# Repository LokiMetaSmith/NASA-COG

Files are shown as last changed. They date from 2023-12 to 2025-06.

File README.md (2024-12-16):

# NASA-MCOG

## Final Report

The final report delivered to NASA for this project can be [read here](https://drive.google.com/file/d/1jfJcSLfsybuC49I7llPhfTNI8ucRUW3h/view?usp=sharing).

## Introduction

This is a repo for a control system made for NASA to drive a Ceramic Oxygen Generation
technology they have developed. It was forked from ["The Ox"]() project of Public Invention run by Mr. Ben Coombs, which was in turn a fork of the VentOS project of Helpful Engineering led by Ben Coombs, Dr. Erich Schulz, and Robert L. Read.

However, the main reason we are starting with this fork is not that the Pressure Swing
Adsorption system of the Ox is a particularly relevant, but rather that the code
represents a nice platform of simple (microcontroller) control of related machines.

To wit, includes PlatformIO configuration, a state machine (finite automata),
a superloop architecture, and a hardware abstraction layer.

This particular project of NASA will improve life support technology in space,
but may eventually greatly improve global health.

An unlisted [YouTube video](https://youtu.be/1nq-Mw7jZ5A) has been uploaded that shows this work in-progress as of September 2022.

## How to run

### Linux
The fundamental way to run this is to perform:  
> cd firmware  
> pio run -e native && ./.pio/build/native/program  
We are currently creating the [RibbonFish](https://github.com/PubInv/NASA-COG/blob/develop/RibbonFish.md) proof-of-concept.
This can be run on a Due by executing:  
> make pio-run-due_ribbonfish  
As this develops, it will use a specific Due hardware configuration,  
please see the [documentation](https://github.com/PubInv/NASA-COG/blob/develop/RibbonFish.md) for details to build your own.  

### Windows
With Powershell
Navigate to the firmware folder. 
Type: pio run -e due_ribbonfish


With Visual Studio Code.  
Install the Plateform IO extension  
To open the project in Visual Studio Code.  
Open Project. Navigate to the firmware folder.   
Select the file platformio.ini  
Press the build check mark on the bottom of the window.


To disable the automatic load and serial monitor comment out the lines with "targets = upload, monitor" in the file "platformio.ini"

## Annoyances

AFAIK, PlatformIO forces a directory tree depth of 5 levels.

This is not enough to organize the Hardware Abstraction Level the way I would prefer, forcing us to make some messy directories that are less than clear.

For example, to implement a Temperature Sensor, we would ideally have an
abstract (or virtual) implementation, a folder for real hardware,
and a folder for mock sensors.  I have no choice now but to jam
the mock sensors into the same directory with the real hardware and
use a naming convention to differentiate them.

## The Command System

The NASA-COG system needs to allow the user to enter commands. The most obvious of these is "turn off".
Because the system should avoid thermal shocks, this is actually not simple.

We have previously used an [approach](https://github.com/PubInv/PIRCS-pubinv-respiration-control-standard) of using simple JSON objects to represent commands. We propose to use the same idea here, but obviously,
the command will be custom to the NASA-COG.

### Parameter Setting Commands
The general scheme is to use a JSON object like:

```JavaScript
{ "com": "T",
  "par": 7,
  "mod": "T",
  "val" : 732.3
  }
```

1. "com" is the command. For example, "T" can mean "set Temperature".
2. "par" is a parameter used to specify something about how to execute the command. For example, 7 could mean location 7, which might be between the 6th and 7th stack.
3. "mod" is a modifier of the command. For example, the "set Temperature" command could be used to
set the minimum, maximum, or the target temperature.
4. "val" is the value that is to be set.

For this problem space, we can specify some global parameters of the problem, some of which
involve safety. These can of course have default values "hard wired" into the code, but an
experimenter may wish to change these values (carefully).

1. The maximum rate of voltage change applied to a stack. Nominally we have defined this as 1 volt/second.
We have evidence that too rapid a voltage change (such as that caused by pulse-width modulation) can destroy
a stack.
2. The maximum rate of temperature change for a stack. Nominally we may say this as 2 degree K per minute,
which would allow the machine to reach operating temperature in 6 hours.
3. The maximum temperature difference across a stack in any dimension. We may not be able to control
this directly, but we can use it as a target.
4. The maximum voltage applied to a stack.
5. The maximum amperage applied to a stack.

### Event-like Commands

We will need other commands that represent discrete events in time. For example, each transition in the
state transition diagram below may be initiated by a command from the user (they may also occur
automatically due to an internal fault or even normal operation.)

COG State Machine

We can implement particular commands with the same scheme.

For example, the simple object:

```JavaScript
{ "com": "C",
  "par": 0,
  "int": "s",
  "mod": "U",
  "val" : 0.0
  }
```

Could mean "Cool Down". The value "U" is used becasue the "mod" command is "unusued" in this case.

```JavaScript
{ "com": "W",
  "par": M,
  "int": "s",
  "mod": "U",
  "val" : 0.0
  }
```

In actual practice, these commands will be pasted into the serial port using either PlatformIO or the Arduino IDE.

Eventually, a user interface may be implemented that uses a knob or a nice webpage to enter commands.
However, by having each of these take only actions that can be implemented as such a command,
we bring discipline to the internal code.

## Actual Serial Commands

The serial port currently supports 6 one-character commands: w,c,e,a,i,o.
These mean:
1. warmup
2. cool down
3. emergency shutdown
4. acknowledge
5. idle
6. operate

Note: "acknowledge" means that the operator acknowledges that a critical
state has occurred and asserts it is okay to return to normal operation,
either because the problem as been removed or for some other reason.

Addtionally, the system supports "full commands", that look like this:

> { "com": "W", "par": "M", "int": "s", "mod": "U", "val" : 0.0 }

> { "com": "C", "par": "M", "int": "s", "mod": "U", "val" : 0.0 }

> { "com": "E", "par": "M", "int": "s", "mod": "U", "val" : 0.0 }

> { "com": "A", "par": "M", "int": "s", "mod": "U", "val" : 0.0 }

> { "com": "I", "par": "M", "int": "s", "mod": "U", "val" : 0.0 }

> { "com": "O", "par": "M", "int": "s", "mod": "U", "val" : 0.0 }

In fact, each "one character" command is a short hand for these commands.

The following format can be used to set parameters (P).
The three most important parameters are:
1. T : Temperature (in C) going into the stack
2. C : Current (in milliamps) going into the stack
3. F : Fan speed in RPM (we expect this to change to flow rate in SLM)
> { "com": "P", "par": "T", "int": "T", "mod": "U", "val" : 35 }

> { "com": "P", "par": "C", "int": "T", "mod": "U", "val" : 500 }

> { "com": "P", "par": "F", "int": "T", "mod": "U", "val" : 2000 }

These three commands set the:
1. Temperature into the stack to 35C
2. Set the Target current into the stack to 500 milliamps
3. Set the flow rate to 2000 ml/seconds

## License

In general we intend to follow the [Public Invention Licensed Guidelines](https://github.com/PubInv/PubInv-License-Guidelines) unless
NASA requests something different. If you are starting your own project, please
feel free to fork the license guidelines as a starting point if you like our
license policy.

This program includes free software: you can redistribute it and/or modify it under the terms of the GNU Affero General Public License as published by the Free Software Foundation, either version 3 of the License, or (at your option) any later version.

See the GNU Affero General Public License for more details. You should have received a copy of the GNU Affero General Public License along with this program. If not, see <https://www.gnu.org/licenses/>.

This program is distributed in the hope that it will be useful, but WITHOUT ANY WARRANTY; without even the implied warranty of MERCHANTABILITY or FITNESS FOR A PARTICULAR PURPOSE.

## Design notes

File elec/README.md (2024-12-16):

# Electrical Information on OEDCS Controler(s) and Plant(s)
PCB Connector Pin signal names, Due Signal Names, Chassis wiring and related information
Inverse cronological order

## Notes for creation of a Control 1.2 PCB  
tbd

## Notes for creation of a Control 1.1 PCB  
This table pulls from information in the references 1 and 2.   
References:
1. Due Pin-Out Map for OEDCS1 : https://docs.google.com/spreadsheets/d/18wP1Cyg5-j3FP92x7no_JsCCFNvo9y2avyn5nvmAj6I/edit#gid=0
2. Fan Controller and Fan Wiring for OEDCOS1: https://docs.google.com/document/d/1n3v-AxqNKEzcKqmHicGKnFmG8sKbNEL_pGaUlU9CZ8U/edit

   WARNING! At present pin D4 works without an external pull up resistor for the termocouples, but D5 does not; it requires an external pull up resistor
   Until we have time to rework our perf board, I am going to continue to use D4 for the MAX31850 OneWire interface.

#### Due Pin Wiring Control 1.1
| **Due Pin Number** 	| **Breakout** 	| **Signal Name** 	| **Set as I/O** 	| **Connection** 	| **Notes** 	|
|---	|---	|---	|---	|---	|---	|
| D0 	| J6-2 	| NA 	| Input pullup. 	| None 	| Not used 	|
| D1 	| J6-1 	| NA 	| Input pullup. 	| None 	| Not used 	|
| D2 	| J6-3 	| NA 	| Input pullup. 	| None 	| Not used 	|
| D3 	| J6-4 	| NA 	| Input pullup. 	| None 	| Not used 	|
| D4 	| J6-5 	| SD ENABLE (BUT ALSO TEMP1) | Input pullup. 	| None 	| SD CS on Ethernet card. 	|
| D5 	| J6-6 	| TEMP1 	| BiDirection 	| Dallas 1 Wire / MAX31850K 	| Three daisy chained, requires 4.7k ohm pull up resistor (but D4 does not!) Please see note 	|
| D6 	| J6-7 	| NA 	| Input pullup. 	| None 	| Not used 	|
| D7 	| J6-8 	| NA 	| Input pullup. 	| None 	| Not used 	|
| D8 	| J7-1 	| NA 	| Input pullup. 	| None 	| Not used 	|
| D9 	| J7-2 	| nFAN1_PWM 	| Output 	| Controlles transistor Q1 	| Was BLOWER_PWM 	|
| D10 	| J7-3 	| NA 	| Input pullup. 	| None 	| Not used 	|
| D11 	| J7-4 	| NA 	| Input pullup. 	| None 	| Not used 	|
| D12 	| J7-5 	| NA 	| Input pullup. 	| None 	| Not used 	|
| D13 	| J7-6 	| NA 	| Input pullup. 	| None 	| Not used 	|
| D13 	| J7-6 	| NA 	| Input pullup. 	| None 	| Not used 	|
| D14 	| J2-1 	| NA 	| 	| None 	| Not used 	|
| D15 	| J2-2 	| NA 	| Input pullup. 	| None 	| Not used 	|
| D16 	| J2-3 	| NA 	| Input pullup. 	| None 	| Can be TX2 	|
| D17 	| J2-4 	| NA 	| Input pullup. 	| None 	| Can be RX2 	|
| D18 	| J2-5 	| D_PSU_TX 	| UART1 TX 	| D_PSU_TX, R15 (then to Power Supply 	| TX1 	|
| D19 	| J2-6 	| D_PSU_RX 	| UART1 RX 	| D_PSU_RX, R14 (then to Power Supply 	| RX1 	|
| D20 	| J2-7 	| SDA 	| SDA 	| test point SDA1, R4, R13 	| SDA 	|
| D21 	| J2-8 	| SCL 	| SCL 	| test point SCL1, R2, R16 	| SCL 	|
| D22 	| J8-4 	| BLOWER_ENABLE 	| OUTPUT 	| R10 	| Enable Switched_Fan_Power at J15 9-12 	|
| D23 	| J8-3 	| NA 	| Input pullup. 	| None 	| Not used 	|
| D24 	| J8-6 	| NA 	| Input pullup. 	| None 	| Not used 	|
| D25 	| J8-5 	| NA 	| Input pullup. 	| None 	| Not used 	|
| D26 	| J8-8 	| NA 	| Input pullup. 	| None 	| Not used 	|
| D27 	| J8-7 	| NA 	| Input pullup. 	| None 	| Not used 	|
| D28 	| J8-10 	| NA 	| Input pullup. 	| None 	| Not used 	|
| D29 	| J8-9 	| NA 	| Input pullup. 	| None 	| Not used 	|
| D30 	| J8-12 	| NA 	| Input pullup. 	| None 	| Not used 	|
| D31 	| J8-11 	| NA 	| Input pullup. 	| None 	| Not used 	|
| D32 	| J8-14 	| nCS_GPAD 	| Output for nCS 	| R55, R61, Q5 	| on 3.3 Volt 	|
| D33 	| J8-13 	| TC_nCS1 	| Output for nCS 	| Thermocouple 1, R7 	| on 3.3 Volt 	|
| D34 	| J8-16 	| TC_nCS2 	| Output for nCS 	| Thermocouple 2, R3 	| on 3.3 Volt 	|
| D35 	| J8-15 	| TC_nCS3 	| Output for nCS 	| Thermocouple 3, R1 	| on 3.3 Volt 	|
| D36 	| J8-18 	| NA 	| Input pullup. 	| None 	| Not used 	|
| D37 	| J8-17 	| NA 	| Input pullup. 	| None 	| Not used 	|
| D38 	| J8-20 	| NA 	| Input pullup. 	| None 	| Not used 	|
| D39 	| J8-19 	| NA 	| Input pullup. 	| None 	| Not used 	|
| D39 	| J8-19 	| NA 	| Input pullup. 	| None 	| Not used 	|
| D40 	| J8-22 	| NA 	| Input pullup. 	| None 	| Not used 	|
| D41 	| J8-21 	| NA 	| Input pullup. 	| None 	| Not used 	|
| D42 	| J8-24 	| NA 	| Input pullup. 	| None 	| Not used 	|
| D43 	| J8-23 	| NA 	| Input pullup. 	| None 	| Not used 	|
| D44 	| J8-26 	| NA 	| Input pullup. 	| None 	| Not used 	|
| D45 	| J8-25 	| NA 	| Input pullup. 	| None 	| Not used 	|
| D46 	| J8-28 	| NA 	| Input pullup. 	| None 	| Not used 	|
| D47 	| J8-27 	| NA 	| Input pullup. 	| None 	| Not used 	|
| D48 	| J8-30 	| NA 	| Input pullup. 	| None 	| Not used 	|
| D49 	| J8-29 	| NA 	| Input pullup. 	| None 	| Not used 	|
| D50 	| J8-32 	| NA 	| Input pullup. 	| None 	| Not used 	|
| D51 	| J8-31 	| SSR_PWM 	| OUTPUT 	| R9 	| Active High. 	|
| D52 	| J8-34 	| NA 	| Input pullup. 	| None 	| Not used 	|
| D53 	| J8-33 	| NA 	| Input pullup. 	| None 	| Not used 	|
| SDA1 	| J7-9 	| NA 	| Input pullup. 	| None 	| Not used 	|
| SCL1 	| J7-10 	| NA 	| Input pullup. 	| None 	| Not used 	|
| CANR 	| J4-7 	| NA 	| Input pullup. 	| None 	| Not used 	|
| CANT 	| J4-8 	| NA 	| Input pullup. 	| None 	| Not used 	|
| DAC0 	| J4-5 	| Disable 	| Only Output 	| None 	| Not used 	|
| DAC1 	| J4-6 	| Disable 	| Only Output 	| None 	| Not used 	|
| A0 	| J5-1 	| BLOWER_TACH 	| Input pullup. 	| R11 	| Measure RPM 	|
| A1 	| J5-2 	| NA 	| Input pullup. 	| None 	| Not used 	|
| A2 	| J5-3 	| NA 	| Input pullup. 	| None 	| Not used 	|
| A3 	| J5-4 	| NA 	| Input pullup. 	| None 	| Not used 	|
| A4 	| J5-5 	| NA 	| Input pullup. 	| None 	| Not used 	|
| A5 	| J5-6 	| NA 	| Input pullup. 	| None 	| Not used 	|
| A6 	| J5-7 	| NA 	| Input pullup. 	| None 	| Not used 	|
| A7 	| J5-8 	| NA 	| Input pullup. 	| None 	| Not used 	|
| A8 	| J4-1 	| NA 	| Input pullup. 	| None 	| Not used 	|
| A9 	| J4-2 	| NA 	| Input pullup. 	| None 	| Not used 	|
| A9 	| J4-2 	| NA 	| Input pullup. 	| None 	| Not used 	|
| A10 	| J4-3 	| NA 	| Input pullup. 	| None 	| Not used 	|
| A11 	| J4-4 	| NA 	| Input pullup. 	| None 	| Not used 	|
| AREF 	| J7-8 	| NA 	| From DUE 	| None 	| Not used 	|
| nRST1 	| J3-6 	| NA 	| Pulled up on DUE 	| None 	| Not used 	|
| IOREF 	| J3-7 	| NA 	| NA 	| None 	| Not used 	|
| VIN 	| J3-1 	| VIN 	| NA 	| +12V into this pin through R76 	| 	|
| +5V 	| J3-4 	| VIN+5V 	| NA 	| Power from Due voltage regulator 	| Three pins. 	|
| 3.3V 	| J3-5 	| 3.3V 	| NA 	| Power from Due voltage regulator 	| One pin. 	|
| MISO 	| tp CPIO1 	| CIPO 	| Input 	| SPI bus 	| 	|
| MOSI 	| tp COPI 	| COPI 	| Output 	| SPI bus 	| 	|
| SCK 	| tp SPI_SCK 	| SPI_SCK 	| Output 	| SPI bus 	| 	|
| nRST2 	| NA 	| SPI_nRST 	| Input 	| S1 reset switch 	| 	|
| end 	| 	| 	| 	| 	| 	|  

**Ethernet pin usage:**
Pins usage on Arduino
* D4: SD card chip select
* D10: W5200 Chip Select
* D11: SPI MOSI
* D12: SPI MISO
* D13: SPI SCK

### Chassis Wiring of OEDCS Unit 2.
Diagram(s) here...

## Unit 1
**Wiring of OEDCOS Unit 1 before the swap out with Control 1.1 assembly**
Notes
1. Due Pin-Out Map for OEDCS SN1 : https://docs.google.com/spreadsheets/d/18wP1Cyg5-j3FP92x7no_JsCCFNvo9y2avyn5nvmAj6I/edit#gid=0
2. Fan Controller and Fan Wiring for OEDCS1: https://docs.google.com/document/d/1n3v-AxqNKEzcKqmHicGKnFmG8sKbNEL_pGaUlU9CZ8U/edit

Wiring of thermocouple amplifires


Revisions:
* 20230821, Update DB25 Male 2-5 from +12V to "+24V Switched (fans)"

| Fan Breakout 	| Signal-Function 	| DB25 MALE Pin # 	| DB25 FEMALE Pin # 	| Other 	| Due Pin 	| Due Signal 	|
|---	|---	|---	|---	|---	|---	|---	|
| 1 	| +24V Switched (fans) 	| 2-5 	| 9-12 	| 	| ??? 	| FAN_POWER 	|
| 2 	| GND for all fans  	| 22-25 	| 14-17 	| 	| GND 	| NA 	|
| 3 	| #1 PWM 	| 13 	| 1 	| J10-1 	| D9 	| nFAN1_PWM  	|
| 4 	| #1 Tach 	| 9 	| 5 	| J9-1  	| A0 	| FAN1_FG 	|
| 5 	| #2 PWM 	| 12 	| 2 	| J10-2 	| 	| nFAN2_PWM  	|
| 6 	| #2 Tach 	| 8 	| 6 	| J9-2  	| 	| FAN2_FG 	|
| 7 	| #3 Tach 	| 11 	| 3 	| J10-3 	| 	| nFAN3_PWM  	|
| 8 	| #3 PWM 	| 7 	| 7 	| J9-3  	| 	| FAN3_FG 	|
| 9 	| #4 Tach 	| 10 	| 4 	| J10-4 	| 	| nFAN4_PWM  	|
| 10 	| #4 PWM 	| 6 	| 8 	| J9-4  	| 	| FAN4_FG 	|
| 	| 	| 	| 25 	| J11-3 	| 	| 	|
| 	| 	| 	| 13 	| J11-4 	| 	| 	|
| 	| 	| 	| 18 	| J12-1 	| 	| 	|
| 	| 	| 	| 19 	| J12-2 	| 	| 	|
| 	| 	| 	| 20 	| J12-3 	| 	| 	|
| 	| 	| 	| 21 	| J12-4 	| 	| 	|
| 	| 	| 	| 22 	| J12-5 	| 	| 	|
| 	| 	| 	| 23 	| J12-6 	| 	| 	|
| 	| 	| 	| 24 	| J12-7 	| 	| 	|

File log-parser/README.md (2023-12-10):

json_log_parser.py is a simple scraper that reads malformed JSON data and performs a series of statistical operations on the data to display the graphs of different properties of the data. 

Usage:

Server access to raw files is nessisary for viewing, in the script there is an array of file locations that can be used to load one or more logs for analysis. They are read in order, so time series data should be preserved if read in the correct order. 

Currently the standard deviation for Temperature, Voltage, Current, and Resistance(as a function of Voltage and Current) are calculated
Other statistical parameters can be added easily

Currently six graphs are produced, Temperature vs Time (unitless), Voltage and current vs Time (unitless), Resistance vs Time (Unix Standard ), Change in Resistance Vs Change in Temperature (this doesn't appear useful at this time), Delta Resistance vs average temperature

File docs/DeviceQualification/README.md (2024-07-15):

# Summary
Part of a test plan for qualifying the OEDCS (Oxygen Engine Digital Control System) 
Written during the Task6 development effort which is to deliver a controller for "long duration" reliability testing of the OEDCS when attached to a CFC.  

## Scope: AC Drop Out / Brown Out Testing
A test specification and procedure for low AC input, aka Brownout.  
A test specification and procedure for interrupted AC input, aka drop out.  

## Required Test Equipment and Setup
Device under test. The device under test must NOT be receiving power from the USB connection.  Modify (cut up) a USB cable to interrupt the +5V to the DUT.  

In addition to a device under test, 
Both typical and corner case loads for the stack supply 
* Shunt
* Nominal load
* Open 
AC line auto transformer make: Model number: Serial number: 
Device for interrupting the AC power. (A switched outlet is a start. However an AC relay under computer control for set drop out duration and phase is even better.)  
Multi meter for monitoring RAW AC Line Input.  
Multi meter for monitoring AC output of Auto transformer, the input to the OEDCS.  
Multi meter for monitoring +24 power supply at Controller TP20.  
Multi meter for monitoring +12 power supply at Controller TP2.  
Multi meter for monitoring +5 power supply at Controler J3 pin 4.  
Multi meter for monitoring voltage Back Up (Sealed Lead Acid batter) at Controller TP???  
Possible oscilloscope for capturing sequence of events and the unexpected.  
Possible logic analyzer for capturing sequence of events and the unexpected.  
Lab thermometer to capture ambient temperature.  

### Setup For Test
*Describe the solution you'd like* 
*A clear and concise description of what you want to happen.* 
Set up of DUT and testing system in a test state(s) 
Connect multi meters at TP2, TP20, the sealed lead acid battery.
> Screen shot of +5V, TP2 and TP20 


Connect OEDCS at front panel (except where noted) to:
1. USB and a PC with a logging terminal program such as TeraTerm
2. NO LAN connection (Future feature expansion)
3. Three or four thermocouples
4. I2C to pressure transducer (Future feature expansion)
5. Blower
6. AC to heater
7. DC to: Stack or shunt or open
8. Through the AC interrupt fixture and the auto transformer connect the AC input **on back panel**

Connect multi meters at +5V, +12 PT2, and +24 TP20.  
Connect current meter in line with Back Up battery.  

## Test Procedure Brown Out
Test conditions and procedures and expected results or information to be captured 
### Test Capture Normal Operation Conditions with Stack Supply: Open Load
During this test, journal how the system fails, the sequence and at what voltages supplies go out of regulation. At what AC input voltage does the controller stop if any?

Capture lab ambient temperature.  
All external power to the device is off.
Connect the USB cable to the DUT and a PC.
Use Serial Monitor the USB to Serial connection to the DUT.  Capture to a TIME STAMPED file with a name reflecting the test a log during the test. Example OEDCS_SN1_NOMINAL_AC_STACK_OPEN.txt 
??? Do we press reset now ???

Apply nominal 120VAC power. 
Monitor system status.  Verify that the controller is operating normally by monitoring the USB serial report.
Capture these parameters at this nominal input.
1. AC into ODECS
2. +24 at TP20
3. +12 at TP2
4. V sealed battery
5. +5V at Back Up battery
6. Current drain on the sealed lead acid battery

### Test For Condition Brown Out with Stack Supply: Open Load
Capture lab ambient temperature.  
Lower AC input voltage, 5V steps may be a good step size. Allow to stabilize for 15 seconds (Verify that this seams to be a good time.) 
At each AC voltage input capture the following:
1. AC into ODECS
2. +24 at TP20
3. +12 at TP2
4. V sealed battery
5. +5V at Back Up battery
6. Current drain on the sealed lead acid battery

### Test For Condition Brown Out Recovery with Stack Supply: Open Load
Capture lab ambient temperature.  
Raise from zero AC input voltage, 5V steps may be a good step size. Allow to stabilize for 15 seconds (Verify that this seams to be a good time.) 
Journal how the system restarts, what is the sequence of each supply. 
At each AC voltage input capture the following:
1. AC into ODECS
2. +24 at TP20
3. +12 at TP2
4. V sealed battery
5. +5V at Back Up battery
6. Current drain on the sealed lead acid battery

Any pathological behaviours?
On what conditions do the controller become active?  
On what conditions does the +12V supply become active?  
On what conditions does the +24V supply become active?  
Describe how the stack power supply recovers and any intervention required by firmware to be implemented in an issue.

### Test For Condition Brown Out with Stack Supply: Shunt
Change out stack supply for a shunt. Retest same as above 
### Test For Condition Brown Out Recovery with Stack Supply: Shunt
Retest same as above. 

### Test For Condition Brown Out with Stack Supply: Nominal load
Change out stack supply for a shunt. Retest same as above 
### Test For Condition Brown Out Recovery with Stack Supply: Nominal load
Retest same as above. 

## Test Procedure AC Drop Out
Test conditions and procedures and expected results or information to be captured 
It is assumed the system still has normal conditions as per the test above "Test Capture Normal Operation Conditions with Stack Supply"
If not journal again the nominal conditions

### Test Capture Normal Operation Conditions with Stack Supply: Nominal load
During this test, journal how the system fails, the sequence and at what voltages supplies go out of regulation or recover in pathological ways. 
Power will be interrupted for short but increasingly long times to root out pathological behavior. 

All external power to the device is off.
Connect the USB cable to the DUT and a PC.
Use Serial Monitor the USB to Serial connection to the DUT.  Capture to a TIME STAMPED file with a name reflecting the test a log during the test. Example OEDCS_SN1_NOMINAL_AC_STACK_OPEN.txt 
??? Do we press reset now ???

Apply nominal 120VAC power. 
Monitor system status.  Verify that the controller is operating normally by monitoring the USB serial report.
Capture these parameters at this nominal input.
1. AC into ODECS
2. +24 at TP20
3. +12 at TP2
4. V sealed battery
5. +5V at Back Up battery
6. Current drain on the sealed lead acid battery

### Test For Condition Manual AC Drop Out with Stack Supply: Nominal load
#### Minimum Interruption
Assuming using a toggle switch, Interrupt (off then on) the AC as fast as possible at least five times in hopes of sampling several phases of the AC line at the time of interruption.
Observe the system for pathological behaviors.
Did the system operate normally through the interruption?  Describe system operation: 
______________________________________________________________________________________ 
______________________________________________________________________________________ 
______________________________________________________________________________________ 

#### Longer Interruption
Gradually Increase the off time repeating with the same off time for about five times

Observe the system for pathological behaviors.
Did the system operate normally through the interruption?  Describe system operation: 
______________________________________________________________________________________ 
______________________________________________________________________________________ 
______________________________________________________________________________________ 

### Test For Condition Automated AC Drop Out with Stack Supply: Nominal load
An AC Drop Out test system based on OEDCS.
Use an OEDCS with custom firmware for this test function as a AC interrupt fixture with which to test the OEDCS under actual test.
Connect from the AC output of the the drop out text fixture in to the the OEDCS under actual test.
Develop firm ware which can turn off (Open) the solid state relay SSR1 for increasing duration. Extra credit if the firmware can be phased triggered from the AC line. 

#### Interruption profile
Set for minimum phase delay
Set for minimum interruption time
Set for number if interruptions

With zero phase delay, increase interruption time till the system behavior changes and journal that change. Continue to look for pathological behaviors.
Observe the system for pathological behaviors.
Did the system operate normally through the interruption?  Describe system operation: 
______________________________________________________________________________________ 
______________________________________________________________________________________ 
______________________________________________________________________________________ 

With insight from the interruption time increase phase delay from zero through at least 32mS (two AC cycles),
Observe the system for pathological behaviors.
Did the system operate normally through the interruption?  Describe system operation: 
______________________________________________________________________________________ 
______________________________________________________________________________________ 
______________________________________________________________________________________

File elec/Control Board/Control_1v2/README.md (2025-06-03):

# Contents of This Folder Copyed. MAKE NO MORE CHANGES HERE
See: https://github.com/PubInv/high-amp-controller-board
Copied on date: 20250526

<hr>
# Control V1.1 aka 1V1
Version 1.1 control board for NASA COG

On line schematic viewing from **Kicanvas** See: https://kicanvas.org  
The Control V1 is an Arduino DUE "Shield". The DUE will live below this printed wiring assembly. An Ethernet shield will live above as a "Socket". See KiCad Symbol & Footprint Library for Arduino Modules for "Shield" and "Socket"

## Schematics
### Browser page view of the schematic by KiCanvas.org 
Top page is "Control v1.kicad_sch". Note the page for MAX31856 is actualy for an MCP9600 but the page was not renamed (as of 20230830)
*  [Control1v1.kicad_sch](https://kicanvas.org/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)
* [Adafruit-MAX31850-thermocouple-breakout-board.kicad_sch](https://kicanvas.org/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)
* [Adafruit-MAX31855-breakout-board.kicad_sch](https://kicanvas.org/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)
* [Adafruit-MAX31856-PCB-master.kicad_sch](https://kicanvas.org/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)
* [Fan controller.kicad_sch](https://kicanvas.org/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)
* [I2C_Level_Shifter.kicad_sch](https://kicanvas.org/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)
* [SPI_ControllerLevel_Shifter.kicad_sch](https://kicanvas.org/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)
* [SSR Interface.kicad_sch](https://kicanvas.org/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)
* [display_interface.kicad_sch](https://kicanvas.org/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)

## PCB / PWA
### Browser page view of the PCB by KiCanvas.org 
Printed Circuit Board, Printed Wiring Assembly
* [Control 1v1.kicad_pcb](https://kicanvas.org/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)

### PCB / PWA 3D Snapshot


### BOM and Parts List
File Notes:
See notes on the Gerbers, BOM and placement files at:
https://github.com/PubInv/NASA-COG/issues/342

## License, Public Invention for this PCB, PWA
* [Firmware: Affero GPL 3.0](https://www.gnu.org/licenses/agpl-3.0.en.html#license-text)
* [CERN Open Hardware Licence Version 2 - Strongly Reciprocal](https://ohwr.org/cern_ohl_s_v2.txt)

<hr> 

## KiCad Symbol & Footprint Library for Arduino Modules
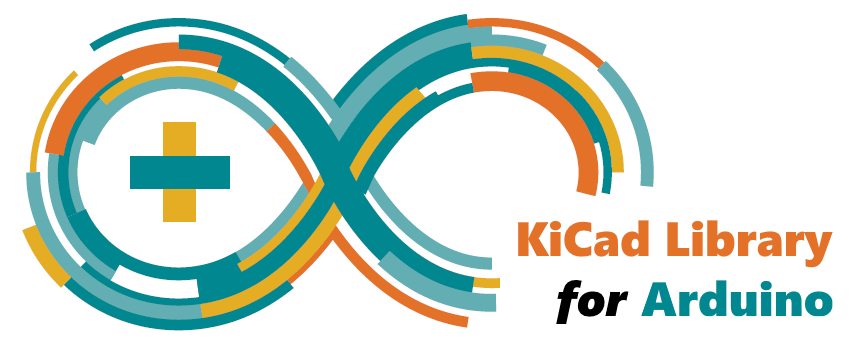
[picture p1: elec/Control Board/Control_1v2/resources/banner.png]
<a href="./PICS/Rev2/PWA_FrontView.png">  
*Version 4.1.0*  

     

This is a library of KiCad schematic symbols and PCB footprints for most Arduino modules. You can use them to make your own PCB design which will effortlessly connect with your chosen Arduino module.

Currently included modules:
- Arduino **101** Shield
- Arduino **Due** Shield
- Arduino **Giga R1 WiFi** Shield
- Arduino **Leonardo** Shield
- Arduino **M0** Shield
- Arduino **M0 Pro** Shield
- Arduino **Mega 2560 R3** Shield
- Arduino **Micro** Socket
- Arduino **Mini** Socket
- Arduino **MKR 1000 WiFi** Socket
- Arduino **MKR WiFi 1010** Socket
- Arduino **MKR FOX 1200** Socket
- Arduino **MKR WAN 1300** Socket
- Arduino **MKR WAN 1310** Socket
- Arduino **MKR GSM 1400** Socket
- Arduino **MKR NB 1500** Socket
- Arduino **MKR Vidor 4000** Socket
- Arduino **MKR Zero** Socket
- Arduino **Nano** Socket
- Arduino **Nano 33 BLE** Socket / Tile
- Arduino **Nano 33 BLE Sense** Socket / Tile
- Arduino **Nano 33 BLE Sense R2** Socket / Tile
- Arduino **Nano 33 IoT** Socket / Tile
- Arduino **Nano Every** Socket / Tile
- Arduino **Nano RP2040 Connect** Socket / Tile
- Arduino **Nicla Sense ME** Socket / Tile
- Arduino **Nicla Vision** Socket / Tile
- Arduino **Nicla Voice** Socket / Tile
- Arduino **Pro Mini** Socket
- Arduino **Uno R1** Shield
- Arduino **Uno R2** Shield
- Arduino **Uno R3** Shield
- Arduino **Uno R3 SMD** Shield
- Arduino **Uno R4 Minima** Shield
- Arduino **Uno R4 WiFi** Shield
- Arduino **Uno WiFi R2** Shield
- Arduino **Zero** Shield
- Clone **Mega 2560 Pro** Socket
- Clone **Pro Mini** Socket

*"Shield" means the module is designed to plug in from beneath your PCB. "Socket" means the module is designed to plug in from above your PCB. "Tile" means the module is designed to be soldered directly on to your PCB using surface-mount pads.*

## KiCad Version Compatibility
This library requires at least KiCad 6 to function, and is tested on KiCad versions 6.0.8 and 7.0.2. Note that the installation procedure is different for KiCad 6 and 7; please see the [Library Installation](#library-installation) section below.

## Comments, Requests, Bugs & Contributions
All are welcome!
Please open an [Issue](https://github.com/Alarm-Siren/arduino-kicad-library/issues) or [Pull Request](https://github.com/Alarm-Siren/arduino-kicad-library/pulls), as appropriate.

## Library Installation
To install this library in your copy of KiCad, choose the correct section for your version of KiCad and follow the steps given. These instructions only cover automated installation using KiCad's built-in Package and Content Manager (PCM); manual installation is possible but not supported.

### KiCad 7

**Warning**: Do not change the nickname prefix from that given in step 4 below. If you do so KiCad will not assign the correct footprints to the symbols by default.

1. Open KiCad and open the Preferences window at "Preferences" -> "Preferences..."
2. Select the "Plugin and Content Manager" section in the left-hand pane.
3. Ensure that the "Automatically add installed libraries to the global lib table" option is ticked.
4. Ensure that the "Library nickname prefix" is set to "PCM_".
5. Ensuring that the "Check for package updates on startup" option is ticked is recommended. **(Optional)**
6. Click "OK" to close the Preferences window.
7. Click the "Plugin and Content Manager" button.
8. Select the "KiCad official repository" from the top drop-down box (if not already selected).
9. Go the Libraries tab and locate the "KiCad Library for Arduino Modules" in the list.
10. Click the "Install" button for that entry in the list.
11. Click "Apply Pending Changes".
12. Close the "Applying Package Changes" window once it has finished.
13. You should now find that this library is listed in the "Installed" tab.
14. Close the Plugin and Content Manager.
15. You may need to restart KiCad for the library installation to fully take effect. **(Optional)**
16. All done: you are now ready to use these schematic components and footprints in your projects!

### KiCad 6
**Recommendation:** If you can, you should upgrade to KiCad 7.

**Warning**: Do not change the Nicknames from those given in steps 12 and 18 below. If you do so KiCad will not assign the correct footprints to the symbols by default.

1. Open KiCad and click the "Plugin and Content Manager" button.
2. Select the "KiCad official repository" from the top drop-down box (if not already selected).
3. Go the Libraries tab and locate the "KiCad Library for Arduino Modules" in the list.
4. Click the "Install" button for that entry in the list.
5. Click "Apply Changes".
6. Close the "Applying Package Changes" window once it has finished.
7. You should now find that this library is listed in the "Installed" tab.
8. Close the Plugin and Content Manager.
9. Go to the "Preferences" -> "Manage Symbol Libraries..." menu option.
10. In the Symbol Libraries dialogue that appears, switch to the "Global Libraries" tab (if not already selected).
11. Click "Add empty row to table" button (the button with a big cross in it, beneath the table).
12. In the new line of the table, set the Nickname to "PCM_arduino-library", and ensure the Library Format is set to "KiCad".
13. In the same line of the table, set Library Path to "${KICAD6_3RD_PARTY}/symbols/com_github_alarm-siren_arduino-kicad-library/arduino-library.kicad_sym".
14. Click "OK" to close the Symbol Libraries dialogue.
15. Go to "Preferences" -> "Manage Footprint Libraries..." menu option.
16. In the Footprint Libraries dialogue that appears, switch to the "Global Libraries" tab (if not already selected).
17. Click "Add empty row to table" button (the button with a big cross in it, beneath the table).
18. In the new line of the table, set the Nickname to "PCM_arduino-library", and ensure the Library Format is set to "KiCad".
19. In the same line of the table, set Library Path to "${KICAD6_3RD_PARTY}/footprints/com_github_alarm-siren_arduino-kicad-library/arduino-library.pretty".
20. Click "OK" to close the Footprint Libraries dialogue.
21. All done: you are now ready to use these schematic components and footprints in your projects!

## Donations

I really hope you've found this library useful. If you'd like to buy me a beer in thanks for the work I put into it, you can make a donation using the button below:



## License & Legal
Copyright 2017-2023, [Nicholas Parks Young](https://github.com/Alarm-Siren).

Except as otherwise noted, all content of this library is licensed under the 
[Creative Commons Attribution-ShareAlike 4.0 International License](https://creativecommons.org/licenses/by-sa/4.0/), with the following additional exception:
> To the extent that the creation of electronic designs that use the Licensed Material can be considered to be Adapted Material, the Licensor waives Section 3 of the Public License with respect to these electronic designs and any generated files which incorporate data provided as part of the Licensed Material.



### "KiCad Library for Arduino" Banner & Icon

The two images "resources/banner.png" and "resources/icon.png" are licensed under the [Creative Commons Attribution-NonCommercial-ShareAlike 4.0 International License](https://creativecommons.org/licenses/by-nc-sa/4.0/). These images are derivatives of ["Arduino Open-Source Community: Main Logotype RGB Colors" originally created by Arduino](https://www.arduino.cc/en/trademark/community-logo). 

Original Images: Copyright 2013, [Arduino](https://www.arduino.cc/). Derived Images: Copyright 2023, [Nicholas Parks Young](https://github.com/Alarm-Siren).



### Arduino Trademark

The word "Arduino" is a registered trademark of [Arduino](https://www.arduino.cc/). This trademark is used in this library to refer to Arduino products and to identify Arduino-related non-commercial content, as permitted by Arduino's [trademark guidelines](https://www.arduino.cc/en/trademark). This project is not affiliated with nor endorsed by Arduino.

## FAQ

Answers to some common questions about this library.

### Is this library in active development?

Yes. For the foreseeable future, I will be providing support, bug-fixes and updating the library with any new Arduino modules as they are released.

### What does the license exception in the License & Legal section mean?

This library uses the same license as KiCad's own built-in parts library does, including the exception. The KiCad Libraries team have a [page which explains the meaning of the exception](https://www.kicad.org/libraries/license/). My version of the exception uses slightly better wording, but the effect is the same.

### Why do the footprints not have an `Edge.Cuts` outline?

If I put in an `Edge.Cuts` outline, then those users who want to have a PCB larger than the module footprint would have to modify the footprint to do so. In my experience, it is far more common for users to want a PCB larger than the module anyway, so I prefer to cater to those users. If you want your PCB to be the same size and shape as the Arduino module, you can trace the `F.Silkscreen` or `B.Silkscreen` layer (as appropriate) out in the `Edge.Cuts` layer yourself, or you can modify the footprint to change the outline from `F.Silkscreen` or `B.Silkscreen` layer to `Edge.Cuts`.

### Why do the Nicla Vision and Nicla Voice tile footprints have cut-outs?

The cut-outs are necessary to accommodate components on the back of those modules; without them the components would physically prevent you from getting the module's pads down to the footprint's SMD pads.

### Why does the whole footprint have an `F.Courtyard` or `B.Courtyard` outline? I can't place my components where I need to!

Firstly, this does not stop you from placing your components wherever you want. It does mean that the KiCad DRC will, by default, report errors or warnings in some circumstances because the module footprint and your circuit's footprints' courtyards are overlapping, but you can ignore or disable these errors/warnings without issue.

Secondly, the intention is that it acts as a warning to the user that they've put components in the 'danger zone' between their PCB and the Module. I do not model all of the tall components on the module, so it is possible that a user might unknowingly place their own tall component in a position that would conflict with one on the module. My hope is that the DRC errors/warnings will flag this potential problem to the user to manually check that their placement does not conflict with the module.

In principle I'm open to marking the taller components specifically, which would remove this issue, but this is a lot of work and requires data I don't have access to for all the modules.

### Why is this Power Pin set to Power Input/Power Output/Unconnected? I get DRC errors because of it!

The short answer is that some power pins on some modules can be used as either inputs or outputs, depending on your circuit design / where you're powering the assembly from.

For those pins where I've been able to categorically confirm that the given power pin is Unconnected by default, or must necessarily be a Power Input or a Power Output, I have set it as such. For those pins that can be used as either an input or output, I have set it to Power Input as this is the more flexible option whilst still preserving some element of DRC capability. If you're using one of these Power Input pins as a Power Output from the module, you'll need to add the special "PWR_FLAG" component to the affected net to make the DRC error go away.

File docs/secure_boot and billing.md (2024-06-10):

## Secure Billing Using Secure Boot and TrustZone

### Overview

Secure Boot is a series of techniques designed to ensure the integrity of firmware and prevent unauthorized modifications without detection. Leveraging cryptographic methods, Secure Boot creates a unique cryptographic identity for the device, protecting it from being copied, modified, or compromised. This ensures that only trusted software is executed during the boot process.

Espressif's Secure Boot[^1]  and ARM's TrustZone technology[^2] provides a hardware-enforced security boundary between the secure world (trusted) and the non-secure world (untrusted) within a single processor. This separation ensures that sensitive operations can be carried out in a secure environment, even if the non-secure world is compromised.

[^1]: https://docs.espressif.com/projects/esp-idf/en/v5.2.2/esp32s3/security/security.html

[^2]: https://developer.arm.com/documentation/PRD29-GENC-009492/c/TrustZone-Software-Architecture/Booting-a-secure-system/Secure-boot

### Secure Billing System Design

**1. Logging Coulombs:**

- The firmware integrates (sums) the amperage over time to calculate the total number of coulombs used, ensuring accurate billing.
- The log of total coulombs is stored in non-volatile memory, such as EEPROM or an external flash memory connected via SPI or I2C. This ensures that the data is retained even if the device is powered off or disconnected from the internet.

**2. Secure Storage:**

- The logs are encrypted using a secure encryption algorithm before being stored, preventing unauthorized access or tampering.
- Encryption keys are securely stored within the device’s secure hardware, such as the ESP32’s Secure Boot or ARM’s TrustZone capabilities.

**3. Offline Operation:**

- The device can operate offline and continue logging the total coulombs. When the device reconnects to the internet, it transmits the encrypted logs to the billing system.
- Each log entry includes a timestamp and a cryptographic signature to ensure authenticity and integrity.

**4. External Server Monthly Billing:**

* An external server reads the encrypted logs transmitted by the device, when the device is online.
* The cryptographic signature ensures that the logs cannot be altered without detection.
* The server decrypts the logs and verifies the cryptographic signatures to ensure the data's integrity.
* Based on the verified data, the server generates the monthly bill. The bill includes the total coulombs logged during the period.
- At the end of each billing period, an external server  generates a bill of usage for a customer.
- This bill includes the total coulombs logged during the period and is transmitted to the billing system.

**5. Verification and Integrity:**

- To prevent cheating by either party, the system must be designed to allow for independent verification of the oxygen production.
- A pressure transducer and other sensors validate the oxygen produced, cross-referencing with the logged coulombs, providing an additional layer of integrity.

### Implementation Example

**ESP32-S3:**

- The ESP32-S3’s Secure Boot feature ensures the integrity of the firmware.
- Encrypted logs are stored in external flash memory via SPI or I2C, utilizing the ESP32’s built-in cryptographic capabilities for secure storage and encryption.

**ARM TrustZone:**

- ARM’s TrustZone creates a secure environment for storing encryption keys and performing cryptographic operations.
- Logs are securely stored in non-volatile memory, with TrustZone ensuring that only trusted software can access and modify these logs.

### Diagram

```plaintext
                          +-----------------------+
                          |                       |
                          |     Secure Boot       |
                          |   (ESP32 / TrustZone) |
                          |                       |
                          +-----------------------+
                                    |
                                    |
                                    V
                       +---------------------------+
                       |                           |
                       |  Firmware Integrates      |
                       |  Amperage Over Time       |
                       |  (Calculates Coulombs)    |
                       |                           |
                       +---------------------------+
                                    |
                                    |
                                    V
                       +---------------------------+
                       |                           |
                       |    Store Encrypted Logs   |
                       |  (EEPROM / External Flash)|
                       |                           |
                       +---------------------------+
                                    |
                                    |
                                    V
                       +---------------------------+
                       |                           |
                       |    Generate Monthly Bill  |
                       |  (Signed with Secret Key) |
                       |                           |
                       +---------------------------+
                                    |
                                    |
                                    V
                       +---------------------------+
                       |                           |
                       |    Transmit Bill and Logs |
                       |    When Online            |
                       |                           |
                       +---------------------------+
```

### Conclusion

This secure billing system ensures that the reported usage is accurate and tamper-proof, providing a reliable basis for billing in a commercial setting. By leveraging Secure Boot and TrustZone technologies, the system can operate independently of an internet connection while maintaining the integrity and authenticity of the usage data.

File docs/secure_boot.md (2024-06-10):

Secure Boot [^1] and TrustZone [^2] are a series of techniques to ensure the integrity of the firmware and to prevent unauthorized modification without detection. Modern microprocessors use cryptographic techniques to achieve this security. 

By establishing a unique cryptographic idenity that is protected from being copied, modified, or compromised, devices can securely sign messages with a private key. The recipient of these messages can then verify that the underlying firmware is secure, ensuring that only trusted software can be executed during the boot process.

For example, on the ESP32-S3, Secure Boot is implemented by ensuring that the firmware is cryptographically signed, and this signature is verified during the boot process . Similarly, ARM's TrustZone architecture uses Secure Boot to create a chain of trust, starting from a root of trust that validates each subsequent stage of the boot process . This approach helps maintain the integrity and security of the system from the moment it powers on.

[^1]: https://docs.espressif.com/projects/esp-idf/en/v5.2.2/esp32s3/security/security.html

[^2]: https://developer.arm.com/documentation/PRD29-GENC-009492/c/TrustZone-Software-Architecture/Booting-a-secure-system/Secure-boot

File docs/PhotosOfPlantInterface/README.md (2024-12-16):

| Column 1 | Column 2 | Notes |
|---|---|---|
|  |  | |
| Austin CFC with Interface Panel.png | Austin Plant Interface Panel.png | |
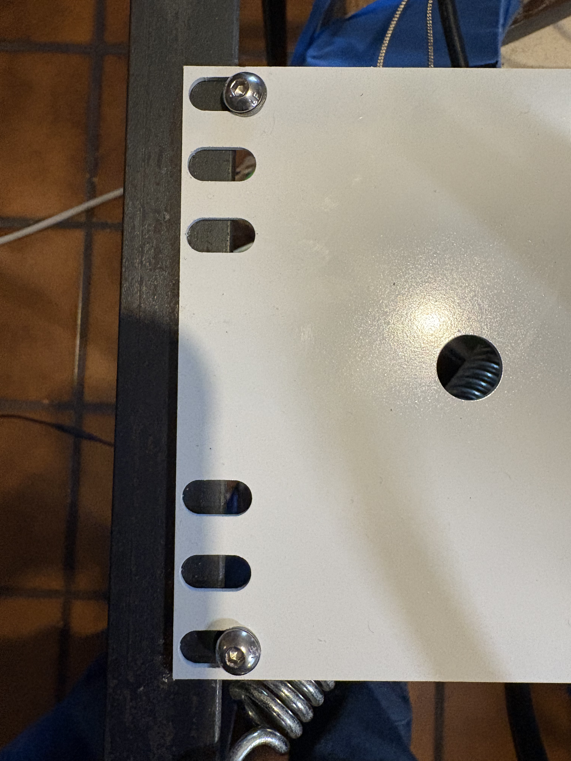
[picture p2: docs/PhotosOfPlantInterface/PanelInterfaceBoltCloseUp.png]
|  |  | |
| Complete System.png | PanelInterfaceBoltCloseUp.png | |

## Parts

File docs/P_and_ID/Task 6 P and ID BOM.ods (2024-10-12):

Note: Update this document, then copy changes to P&ID diagram SVG
Quantity | Reference | Connections | Description | Merchant Link | Purchase Date | Price |  | model | notes
1 | R1 | 1/4 NPT Male x 1/4 NPT Female | Oxygen Hose, with Brass 1/4 NPT Male x 1/4 NPT Female Fittings, 5/8" OD , Length 6 ft. | https://www.mcmaster.com/5665K61-5665K65/ |  | $147.29 | don’t need
1 | R2 | 1/8" Barbed Tube ID | Miniature Brass Quick-Disconnect Coupling for Air, Socket, for 1/8" Barbed Tube ID | https://www.mcmaster.com/9414K31/ | 07/05/24 | $12.41
1 | R3 | 1/4 NPT Female x male | High-Pressure Inline Filter,Brass Housing, 1/4 NPT Female x Male, 10 Microns | https://www.mcmaster.com/9811K64/ | 09/07/24 | $24.15
1 | R4 | 3/8 NPT Male | Muffler, 3/8 NPT Male, Steel, 23 scfm @ 100 PSI Maximum Flow Rate | https://www.mcmaster.com/4450K3/ |  | $4.07 | don’t need
1 | R5 | 3/8 NPT Inlet x 1/4 NPT Outlet | Brass Right-Angle Flow Rectangular Manifold, 3 Outlets, 3/8 NPT Inlet x 1/4 NPT Outlet | https://www.mcmaster.com/5627K505/ | 09/07/24 | $82.50 | Will return
1 | R6 | 1/4 NPT Male | Gas Pressure Gauge 0 to 30psi with Brass Case.1/4 NPT Male Bottom Connection, 2" Dial | https://www.mcmaster.com/products/gauges/case-material~brass-2/ |  | $33.90
1 | R7 | Two 1/8" NPT Female | Digital Mass Flow Meter with Temperature and Pressure | https://www.aalborg.com/index.php/main_page/product_info/products_id/534448/show_table_build/show/confback/28 |  | $1,033.00
1 | R8 | 0-5v, 4-20mA, USB | USB DAQ and Stand-alone Data Logger, 32GB USB Flash Drive, 4-8 Analog Inputs, ±10 V, 160kHz, Anti-aliasing Filter, 7 D I/O, Free WinDaq Software | https://www.dataq.com/products/di-2108/ |  | $199.00
1 | R9 | 1/4 NPT Male | Fast-Acting Pressure-Relief Valve 5 psi,for Cryogenic Liquids, 1/4 NPT Male | https://www.mcmaster.com/9137K11-9137K41/ | 09/07/24 | $59.29
1 | R10 | Male Hose Plugs x Female Regulator Sckts CGA-022 and 023(cga-23 not used) | Quick-Disconnect Hose Coupling Set for Compre,CGA-022 and 023, Male Hose Plugs x Female Regulator Sckts | https://www.mcmaster.com/7934A6/ | 09/07/24 | $104.13
1 | R11 | 1/4" OD | General Purpose Copper Tubing, 1/4" OD, 0.049" Wall Thickness, Coil | https://www.mcmaster.com/8955K112-8955K31/ | 09/07/24 | $48.15 |  | 8955K31_General Purpose Copper Tubing.STEP
1 | R12 | 4mm x 1/4" Tube OD | Yor-Lok Fitting for Stainless Steel Tubing, Straight Adapter for 4mm x 1/4" Tube OD | https://www.mcmaster.com/5305K401/ | 09/07/24 | $23.69 |  | 5305K401_Yor-Lok Fitting for Stainless Steel Tubing.STEP
1 | R13 | 1/4 NPTF Female | High-Pressure Nickel-Plated Brass Pipe Fitting, Tee Connector, 1/4 NPTF Female | https://www.mcmaster.com/9151K42/ | 09/07/24 | $8.48 |  | 9151K42_High-Pressure Nickel-Plated Brass Pipe Fitting.STEP
1 | R14 | 18 UNF Right-Hand Female x 1/4 NPT Male | Hose Fitting for Compressed Gas, Adapter, CGA-022, 9/16"-18 UNF Right-Hand Female x 1/4 NPT Male | https://www.mcmaster.com/7919A51/ | 07/05/24 | $10.42 |  | 7919A51_Hose Fitting for Compressed Gas.STEP
1 | R15 | 1/4" Tube OD x 1/4 NPT Male | Yor-Lok Fitting for Copper Tubing, Straight Adapter for 1/4" Tube OD x 1/4 NPT Male | https://www.mcmaster.com/5272K191/ | 07/05/24 | $6.93 |  | 5272K191_Yor-Lok Fitting for Copper Tubing.STEP
2 | R16, R17 | 1/4 x 1/8 NPT Male | Precision Extreme-Pressure Brass Pipe Fitting, Straight Reducer, 1/4 x 1/8 NPT Male | https://www.mcmaster.com/9171K213/ | 07/05/24 | $11.94
1 | R18 | 1/8" Hose ID x 1/4 NPT Male | Barbed Hose Fitting for Drinking Water, Straight Adapter for 1/8" Hose ID x 1/4 NPT Male | https://www.mcmaster.com/2838N12/ | 07/05/24 | $3.52
1 | R19, | 1/8" ID, 1/4" OD | High-Purity Soft Tygon Plastic Blend Tubing, 1/8" ID, 1/4" OD | https://www.mcmaster.com/5466K32/ | 07/05/24 | $13.15
2 | R20, R21 | 13/64" to 1/4" ID | Vibration-Resistant Pinch Clamp for Soft Hose and Tube, 13/64" to 1/4" ID, Packs of 10 | https://www.mcmaster.com/52545K932/ | 07/05/24 | $6.47
1 | R22 | 3/8 Male x 1/4 Female NPT | Low-Pressure Brass Threaded Pipe Fitting, Bushing Adapter with Hex Body, 3/8 Male x 1/4 Female NPT | https://www.mcmaster.com/4429K412/ | 07/05/24 | $4.27 | ordered on amazon
1 | R23 | 9/16"-18 UNF Male x 1/4 NPT Male | Hose Fitting for Compressed Gas, CGA 022 Adapter, 9/16"-18 UNF Male x 1/4 NPT Male | https://www.mcmaster.com/79215a1/ | 07/05/24 | $1.84
 | R24 | 1/4 NPT Male | Fast-Acting Pressure-Relief Valve 200 psi,for Cryogenic Liquids, 1/4 NPT Male | https://www.mcmaster.com/9137K11-9137K71/ | 09/07/24 | $59.29 |  | 9137K71_Fast-Acting Pressure-Relief Valve.STEP
 | R25 | M18 x 1.5 Male Thread | Air Quality Sensors Oxygen Sensor System, zirconia, 0.1 to 100% O2, RS485 Modbus RTU output | https://www.mouser.com/ProductDetail/SST-Sensing/ZrO2-System-485?qs=3jNSNtuqJTLI%2FbQpiEeOeA%3D%3D | 01/01/23 | $462.16
 | R26 | Right-Angle Tee Adapter, 3/8 NPT Female x Male | Low-Pressure Brass Threaded Pipe Fitting, Right-Angle Tee Adapter, 3/8 NPT Female x Male | https://www.mcmaster.com/4429K325/ |  | $29.10 | ordered on amazon
 | R27 | 3/8 NPT Male, M18 x 1.50 mm Male | Compact Extreme-Pressure Steel Pipe Fitting, Adapter, 3/8 NPT Male, M18 x 1.50 mm Male Thread | https://www.mcmaster.com/4936K768/ |  | $28.36 | don’t need
 | R28 | M18 x 1.5 Female Thread | Compact Extreme-Pressure Steel Pipe Fitting, Straight Connector, M18 x 1.5 Female Thread | https://www.mcmaster.com/4936K984/ |  | $20.98 |  |  | This coupled correctly to the sensor
 | R29 | ID 18 mm | Chemical-Resistant Viton® Fluoroelastomer O-Ring, Super-Resilient, 2 mm Wide, 18 mm ID | https://www.mcmaster.com/1295n244/ | 09/07/24 | $5.26 |  |  | Turned out to be too big, needs to be inner dia.=17mm, 2mm or less thickness.
 | R30 | 5 mm (0.19") OD stub with “quickconnect” barb fitting for 6.3 mm (¼") ID tube | OMEGA GAB-1700 oxygen analyzer non-depleting, (magnetodynamic paramagnetic) | https://sea.omega.com/th/pptst/GAB-1700.html | 01/01/23 | $2,600.00
 | R31 | 1/2" Screw Size, 0.562" ID, 1.5" OD, 0.112"-0.138" Thick | Chemical-Resistant PVC Plastic Washer for 1/2" Screw Size, 0.562" ID, 1.5" OD, 0.112"-0.138" Thick | https://www.mcmaster.com/95611A286/ | 09/07/24 | $4,892.94 |  | 95611A286_Chemical-Resistant PVC Plastic Washer.STEP
 | R32 | ¼” NPT Female inlet, ¼” NPT Female outlet | Back Pressure Regulator 100 to 350 PSIG (6.9 to 24.1 bar) , P/N: BPR-250-C-325 | https://www.generant.com/product/back-pressure-regulator-bpr/ |  | $250.00
 | R33 | ¼” NPT Male | Gas Pressure Gauge 0 to 200psi with Brass Case.1/4 NPT Male Bottom Connection, 2" Dial | https://www.mcmaster.com/32255K7/ |  | $33.90
 | R34 | 1/8" NPT Male | digital pressure gauge 5psi, Pressure Transducer Sender Sensor with Connector, 1/8"NPT Thread Stainless Steel Fuel Pressure Sensor for Oil Fuel Air Water (5 PSI) | https://www.amazon.com/dp/B0D2H253X1 |  | $19.99
 | R35 | 1/8" NPT Male | digital pressure gauge 200psi, 200 PSI Pressure Transducer Sensor with Connector Harness, 1/8"NPT Thread Stainless Steel Pressure Transmitter | https://www.amazon.com/dp/B0CRQVDJJ7 | 08/27/24 | $16.69
 | R36, R37 | 1/8” NPT Female to ¼” NPT Male | High-Pressure Brass Pipe Fitting, Bushing Adapter with Hex Body, 1/4 Male x 1/8 Female NPT | https://www.mcmaster.com/50785K61/ |  | $1.23
 | R38 | ¼” NPT male to ½” NPT Female | High-Pressure Brass Pipe Fitting, Reducing Adapter, 1/2 NPT Female x 1/4 NPT Male | https://www.mcmaster.com/50785K614/ |  | $6.28
 | R39 | ½” NPT Male to M16x1mm Female | Schedule 80 3” pipe, cut in half, with M16x1mm tapped thread | https://www.mcmaster.com/9149K54/ |  | $18.26
 | R40 | M16x1mm Male | Air Quality Sensors Air Quality Sensors Oxygen Sensor 0-100% | https://www.mouser.com/ProductDetail/523-SGX-VOX | 09/01/24 | $59.40

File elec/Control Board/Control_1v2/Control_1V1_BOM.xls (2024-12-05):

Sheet: RAW
Source: | C:\Users\Public\Downloads\Arduino\PubInv\NASA-COG\elec\Control Board\Control_1v1\Control_1v1\Control_1v1.kicad_sch
Date: | 10/11/2023 9:02:01 PM
Tool: | Eeschema 7.0.5
Generator: | C:\Program Files\KiCad\6.0\bin\scripting\plugins/bom_csv_grouped_by_value.py
Component Count: | 287
Individual Components:
Item | Qty | Reference(s) | Value | LibPart | Footprint | Datasheet | Assembly Type | AssemblyType | Category | Cost | DK_Datasheet_Link | DK_Detail_Page | Description | Digi-Key_PN | Distributor 1 | Distributor 1 PN | Distributor 2 | Distributor 2 PN | Family | LongLead | MPN | Manufacturer | Part Number | Status
 |  | A1 | Arduino_Due_Shield | arduino-library:Arduino_Due_Shield | PubInv_KiCad_PCB:Arduino_Due_Shield_Annotated | https://docs.arduino.cc/hardware/due
 |  | C1 | 39pF | Device:C | Capacitor_SMD:C_0603_1608Metric_Pad1.08x0.95mm_HandSolder | https://datasheet.lcsc.com/lcsc/1811082118_YAGEO-CC0603JRNPO9BN390_C107049.pdf |  | SMT |  | 0.003 |  |  | 50V 39pF NP0 Â±5% 0603 Multilayer Ceramic Ca |  | JLCPCB | C107049 |  |  |  | NO | CC0603JRNPO9BN390 | YAGEO
 |  | C2 | 39pF | Device:C | Capacitor_SMD:C_0603_1608Metric_Pad1.08x0.95mm_HandSolder | https://datasheet.lcsc.com/lcsc/1811082118_YAGEO-CC0603JRNPO9BN390_C107049.pdf |  | SMT |  | 0.003 |  |  | 50V 39pF NP0 Â±5% 0603 Multilayer Ceramic Ca |  | JLCPCB | C107049 |  |  |  | NO | CC0603JRNPO9BN390 | YAGEO
 |  | C3 | 39pF | Device:C | Capacitor_SMD:C_0603_1608Metric_Pad1.08x0.95mm_HandSolder | https://datasheet.lcsc.com/lcsc/1811082118_YAGEO-CC0603JRNPO9BN390_C107049.pdf |  | SMT |  | 0.003 |  |  | 50V 39pF NP0 Â±5% 0603 Multilayer Ceramic Ca |  | JLCPCB | C107049 |  |  |  | NO | CC0603JRNPO9BN390 | YAGEO
 |  | C4 | 39pF | Device:C | Capacitor_SMD:C_0603_1608Metric_Pad1.08x0.95mm_HandSolder | https://datasheet.lcsc.com/lcsc/1811082118_YAGEO-CC0603JRNPO9BN390_C107049.pdf |  | SMT |  | 0.003 |  |  | 50V 39pF NP0 Â±5% 0603 Multilayer Ceramic Ca |  | JLCPCB | C107049 |  |  |  | NO | CC0603JRNPO9BN390 | YAGEO
 |  | C5 | 39pF | Device:C | Capacitor_SMD:C_0603_1608Metric_Pad1.08x0.95mm_HandSolder | https://datasheet.lcsc.com/lcsc/1811082118_YAGEO-CC0603JRNPO9BN390_C107049.pdf |  | SMT |  | 0.003 |  |  | 50V 39pF NP0 Â±5% 0603 Multilayer Ceramic Ca |  | JLCPCB | C107049 |  |  |  | NO | CC0603JRNPO9BN390 | YAGEO
 |  | C6 | 39pF | Device:C | Capacitor_SMD:C_0603_1608Metric_Pad1.08x0.95mm_HandSolder | https://datasheet.lcsc.com/lcsc/1811082118_YAGEO-CC0603JRNPO9BN390_C107049.pdf |  | SMT |  | 0.003 |  |  | 50V 39pF NP0 Â±5% 0603 Multilayer Ceramic Ca |  | JLCPCB | C107049 |  |  |  | NO | CC0603JRNPO9BN390 | YAGEO
 |  | C7 | 39pF | Device:C | Capacitor_SMD:C_0603_1608Metric_Pad1.08x0.95mm_HandSolder | https://datasheet.lcsc.com/lcsc/1811082118_YAGEO-CC0603JRNPO9BN390_C107049.pdf |  | SMT |  | 0.003 |  |  | 50V 39pF NP0 Â±5% 0603 Multilayer Ceramic Ca |  | JLCPCB | C107049 |  |  |  | NO | CC0603JRNPO9BN390 | YAGEO
 |  | C8 | 39pF | Device:C | Capacitor_SMD:C_0603_1608Metric_Pad1.08x0.95mm_HandSolder | https://datasheet.lcsc.com/lcsc/1811082118_YAGEO-CC0603JRNPO9BN390_C107049.pdf |  | SMT |  | 0.003 |  |  | 50V 39pF NP0 Â±5% 0603 Multilayer Ceramic Ca |  | JLCPCB | C107049 |  |  |  | NO | CC0603JRNPO9BN390 | YAGEO
 |  | C9 | 39pF | Device:C | Capacitor_SMD:C_0603_1608Metric_Pad1.08x0.95mm_HandSolder | https://datasheet.lcsc.com/lcsc/1811082118_YAGEO-CC0603JRNPO9BN390_C107049.pdf |  | SMT |  | 0.003 |  |  | 50V 39pF NP0 Â±5% 0603 Multilayer Ceramic Ca |  | JLCPCB | C107049 |  |  |  | NO | CC0603JRNPO9BN390 | YAGEO
 |  | C10 | 39pF | Device:C | Capacitor_SMD:C_0603_1608Metric_Pad1.08x0.95mm_HandSolder | https://datasheet.lcsc.com/lcsc/1811082118_YAGEO-CC0603JRNPO9BN390_C107049.pdf |  | SMT |  | 0.003 |  |  | 50V 39pF NP0 Â±5% 0603 Multilayer Ceramic Ca |  | JLCPCB | C107049 |  |  |  | NO | CC0603JRNPO9BN390 | YAGEO
 |  | C11 | 39pF | Device:C | Capacitor_SMD:C_0603_1608Metric_Pad1.08x0.95mm_HandSolder | https://datasheet.lcsc.com/lcsc/1811082118_YAGEO-CC0603JRNPO9BN390_C107049.pdf |  | SMT |  | 0.003 |  |  | 50V 39pF NP0 Â±5% 0603 Multilayer Ceramic Ca |  | JLCPCB | C107049 |  |  |  | NO | CC0603JRNPO9BN390 | YAGEO
 |  | C12 | 39pF | Device:C | Capacitor_SMD:C_0603_1608Metric_Pad1.08x0.95mm_HandSolder | https://datasheet.lcsc.com/lcsc/1811082118_YAGEO-CC0603JRNPO9BN390_C107049.pdf |  | SMT |  | 0.003 |  |  | 50V 39pF NP0 Â±5% 0603 Multilayer Ceramic Ca |  | JLCPCB | C107049 |  |  |  | NO | CC0603JRNPO9BN390 | YAGEO
 |  | C13 | 39pF | Device:C | Capacitor_SMD:C_0603_1608Metric_Pad1.08x0.95mm_HandSolder | https://datasheet.lcsc.com/lcsc/1811082118_YAGEO-CC0603JRNPO9BN390_C107049.pdf |  | SMT |  | 0.003 |  |  | 50V 39pF NP0 Â±5% 0603 Multilayer Ceramic Ca |  | JLCPCB | C107049 |  |  |  | NO | CC0603JRNPO9BN390 | YAGEO
 |  | C14 | 39pF | Device:C | Capacitor_SMD:C_0603_1608Metric_Pad1.08x0.95mm_HandSolder | https://datasheet.lcsc.com/lcsc/1811082118_YAGEO-CC0603JRNPO9BN390_C107049.pdf |  | SMT |  | 0.003 |  |  | 50V 39pF NP0 Â±5% 0603 Multilayer Ceramic Ca |  | JLCPCB | C107049 |  |  |  | NO | CC0603JRNPO9BN390 | YAGEO
 |  | C15 | 39pF | Device:C | Capacitor_SMD:C_0603_1608Metric_Pad1.08x0.95mm_HandSolder | https://datasheet.lcsc.com/lcsc/1811082118_YAGEO-CC0603JRNPO9BN390_C107049.pdf |  | SMT |  | 0.003 |  |  | 50V 39pF NP0 Â±5% 0603 Multilayer Ceramic Ca |  | JLCPCB | C107049 |  |  |  | NO | CC0603JRNPO9BN390 | YAGEO
 |  | C16 | 1uF | Device:C | Capacitor_SMD:C_0603_1608Metric_Pad1.08x0.95mm_HandSolder | CC0603JRX7R9BB104.pdf |  | SMT |  | 0.0037 |  |  | 50V 1uF Â±5% 0603 Multilayer Ceramic Ca |  | JLCPCB | C91183 |  |  |  | NO | CC0603JRX7R9BB104 | YAGEO
 |  | C17 | 1uF | Device:C | Capacitor_SMD:C_0603_1608Metric_Pad1.08x0.95mm_HandSolder | CC0603JRX7R9BB104.pdf |  | SMT |  | 0.0037 |  |  | 50V 1uF Â±5% 0603 Multilayer Ceramic Ca |  | JLCPCB | C91183 |  |  |  | NO | CC0603JRX7R9BB104 | YAGEO
 |  | C18 | 1uF | Device:C | Capacitor_SMD:C_0603_1608Metric_Pad1.08x0.95mm_HandSolder | CC0603JRX7R9BB104.pdf |  | SMT |  | 0.0037 |  |  | 50V 1uF Â±5% 0603 Multilayer Ceramic Ca |  | JLCPCB | C91183 |  |  |  | NO | CC0603JRX7R9BB104 | YAGEO
 |  | C19 | 1uF | Device:C | Capacitor_SMD:C_0603_1608Metric_Pad1.08x0.95mm_HandSolder | CC0603JRX7R9BB104.pdf |  | SMT |  | 0.0037 |  |  | 50V 1uF Â±5% 0603 Multilayer Ceramic Ca |  | JLCPCB | C91183 |  |  |  | NO | CC0603JRX7R9BB104 | YAGEO
 |  | C20 | 39pF | Device:C | Capacitor_SMD:C_0603_1608Metric_Pad1.08x0.95mm_HandSolder | https://datasheet.lcsc.com/lcsc/1811082118_YAGEO-CC0603JRNPO9BN390_C107049.pdf |  | SMT |  | 0.003 |  |  | 50V 39pF NP0 Â±5% 0603 Multilayer Ceramic Ca |  | JLCPCB | C107049 |  |  |  | NO | CC0603JRNPO9BN390 | YAGEO
 |  | C21 | 39pF | Device:C | Capacitor_SMD:C_0603_1608Metric_Pad1.08x0.95mm_HandSolder | https://datasheet.lcsc.com/lcsc/1811082118_YAGEO-CC0603JRNPO9BN390_C107049.pdf |  | SMT |  | 0.003 |  |  | 50V 39pF NP0 Â±5% 0603 Multilayer Ceramic Ca |  | JLCPCB | C107049 |  |  |  | NO | CC0603JRNPO9BN390 | YAGEO
 |  | C22 | 10nF | Device:C | Capacitor_SMD:C_0603_1608Metric_Pad1.08x0.95mm_HandSolder | ~ |  | SMT |  | 0.0132 |  |  |  |  | JLCPCB | C389113 |  |  |  |  | CC0603JRNPO9BN103 | YAGEO
 |  | C23 | 39pF | Device:C | Capacitor_SMD:C_0603_1608Metric_Pad1.08x0.95mm_HandSolder | https://datasheet.lcsc.com/lcsc/1811082118_YAGEO-CC0603JRNPO9BN390_C107049.pdf |  | SMT |  | 0.003 |  |  | 50V 39pF NP0 Â±5% 0603 Multilayer Ceramic Ca |  | JLCPCB | C107049 |  |  |  | NO | CC0603JRNPO9BN390 | YAGEO
 |  | CIPO1 | CIPO | Connector:TestPoint | TestPoint:TestPoint_Loop_D2.54mm_Drill1.5mm_Beaded | ~ |  | HAND |  | 0
 |  | COPI1 | COPI | Connector:TestPoint | TestPoint:TestPoint_Loop_D2.54mm_Drill1.5mm_Beaded | ~ |  | HAND |  | 0
 |  | D1 | 5.1V | Diode:BZV55B3V3 | Diode_SMD:D_MiniMELF | https://assets.nexperia.com/documents/data-sheet/BZV55_SER.pdf BZV55B3V3 |  | SMT |  | 0.0433 |  |  | Â±5% Single 1W 5.1V MELF Zener Diodes ROHS |  | JLCPCB | C841097 |  |  |  |  | DL4733A | LGE
 |  | D2 | 5.1V | Diode:BZV55B3V3 | Diode_SMD:D_MiniMELF | https://assets.nexperia.com/documents/data-sheet/BZV55_SER.pdf BZV55B3V3 |  | SMT |  | 0.0433 |  |  | Â±5% Single 1W 5.1V MELF Zener Diodes ROHS |  | JLCPCB | C841097 |  |  |  |  | DL4733A | LGE
 |  | D3 | 1N5819WS | Diode:1N5819WS | Diode_SMD:D_SOD-323 | https://datasheet.lcsc.com/lcsc/2204281430_Guangdong-Hottech-1N5819WS_C191023.pdf |  | SMT |  | 0.0119 |  |  | 40V 600mV@1A 1A SOD-323 Schottky Barrier Diodes (SBD) ROHS |  | JLCPCB | C191023 |  |  |  |  | 1N5819WS | Guangdong Hottech
 |  | D4 | RED 0603 | Device:LED | LED_SMD:LED_0603_1608Metric_Pad1.05x0.95mm_HandSolder | ~ |  | HAND | Optoelectronics | 0.0054 | http://optoelectronics.liteon.com/upload/download/DS22-2000-109/LTST-C171KRKT.pdf | /product-detail/en/lite-on-inc/LTST-C171KRKT/160-1427-1-ND/386800 | LED RED CLEAR SMD | 160-1427-1-ND | JLCPCB | C2286 |  |  | LED Indication - Discrete |  | LTST-C171KRKT | Lite-On Inc. |  | Active
 |  | D_PSU_RX1 | D_PSU_RX | Connector:TestPoint | TestPoint:TestPoint_Loop_D2.54mm_Drill1.5mm_Beaded | ~ |  | HAND |  | 0
 |  | D_PSU_RX2 | D_PSU_RX2 | Connector:TestPoint | TestPoint:TestPoint_Loop_D2.54mm_Drill1.5mm_Beaded | ~ |  | HAND |  | 0
 |  | D_PSU_TX1 | D_PSU_TX | Connector:TestPoint | TestPoint:TestPoint_Loop_D2.54mm_Drill1.5mm_Beaded | ~ |  | HAND |  | 0
 |  | D_PSU_TX2 | D_PSU_TX2 | Connector:TestPoint | TestPoint:TestPoint_Loop_D2.54mm_Drill1.5mm_Beaded | ~ |  | HAND |  | 0
 |  | H1 | MountingHole_Pad_3.5mm | GPAD_SCH_LIB:MountingHole_Pad_3.5mm | PubInv_KiCad_PCB:MountingHole_3.5mm_Pad_Via | ~ |  | NA |  | 0 |  |  | MountingHole_Pad_3.5mm |  | NA | NA
 |  | H2 | MountingHole_Pad_3.5mm | GPAD_SCH_LIB:MountingHole_Pad_3.5mm | PubInv_KiCad_PCB:MountingHole_3.5mm_Pad_Via | ~ |  | NA |  | 0 |  |  | MountingHole_Pad_3.5mm |  | NA | NA
 |  | H3 | MountingHole_Pad_3.5mm | GPAD_SCH_LIB:MountingHole_Pad_3.5mm | PubInv_KiCad_PCB:MountingHole_3.5mm_Pad_Via | ~ |  | NA |  | 0 |  |  | MountingHole_Pad_3.5mm |  | NA | NA
 |  | H4 | MountingHole_Pad_3.5mm | GPAD_SCH_LIB:MountingHole_Pad_3.5mm | PubInv_KiCad_PCB:MountingHole_3.5mm_Pad_Via | ~ |  | NA |  | 0 |  |  | MountingHole_Pad_3.5mm |  | NA | NA
 |  | H5 | MountingHole_Pad_3.5mm | GPAD_SCH_LIB:MountingHole_Pad_3.5mm | PubInv_KiCad_PCB:MountingHole_3.5mm_Pad_Via | ~ |  | NA |  | 0 |  |  | MountingHole_Pad_3.5mm |  | NA | NA
 |  | ISO1 | MountingHole_Pad_3.5mm | GPAD_SCH_LIB:MountingHole_Pad_3.5mm | PubInv_KiCad_PCB:MountingHole_3.5mm_Pad_Via | ~ |  | NA |  | 0 |  |  | MountingHole_Pad_3.5mm |  | NA | NA
 |  | ISO2 | MountingHole_Pad_3.5mm | GPAD_SCH_LIB:MountingHole_Pad_3.5mm | PubInv_KiCad_PCB:MountingHole_3.5mm_Pad_Via | ~ |  | NA |  | 0 |  |  | MountingHole_Pad_3.5mm |  | NA | NA
 |  | ISO3 | MountingHole_Pad_3.5mm | GPAD_SCH_LIB:MountingHole_Pad_3.5mm | PubInv_KiCad_PCB:MountingHole_3.5mm_Pad_Via | ~ |  | NA |  | 0 |  |  | MountingHole_Pad_3.5mm |  | NA | NA
 |  | ISO4 | MountingHole_Pad_3.5mm | GPAD_SCH_LIB:MountingHole_Pad_3.5mm | PubInv_KiCad_PCB:MountingHole_3.5mm_Pad_Via | ~ |  | NA |  | 0 |  |  | MountingHole_Pad_3.5mm |  | NA | NA
 |  | ISO5 | MountingHole_Pad_3.5mm | GPAD_SCH_LIB:MountingHole_Pad_3.5mm | PubInv_KiCad_PCB:MountingHole_3.5mm_Pad_Via | ~ |  | NA |  | 0 |  |  | MountingHole_Pad_3.5mm |  | NA | NA
 |  | J1 | DB9_Female_MountingHoles | Connector:DB9_Female_MountingHoles | Connector_Dsub:DSUB-9_Female_Horizontal_P2.77x2.84mm_EdgePinOffset4.94mm_Housed_MountingHolesOffset7.48mm | C141882_D-DMR009PF-D002.pdf |  | HAND |  | 0.2718 |  |  | 9P Female D-Sub Shrouded 2 3A -50â„ƒ~+105â„ƒ Plugin D-Sub/DVI/HDMI Connectors ROHS |  | JLCPCB | C141882 |  |  |  |  | D-DMR009PF-D002 | Ckmtw(Shenzhen Cankemeng)
 |  | J2 | Conn_01x08 | Connector_Generic:Conn_01x08 | Connector_PinSocket_2.54mm:PinSocket_1x08_P2.54mm_Vertical | https://jlcpcb.com/partdetail/Hctl-PZ254_1_08_Z_85/C2894931 |  | HAND |  | 0.0762 |  |  | 3A Straight Square Pins 2.5mm 8P 6mm -40â„ƒ~+105â„ƒ 3mm 2.54mm Plugin Black 1x8P Plugin,P=2.54mm Pin Headers ROHS |  | JLCPCB | C2894931 |  |  |  |  | PZ254-1-08-Z-8.5 | HCTL
 |  | J3 | Conn_01x08 | Connector_Generic:Conn_01x08 | Connector_PinSocket_2.54mm:PinSocket_1x08_P2.54mm_Vertical | https://jlcpcb.com/partdetail/Hctl-PZ254_1_08_Z_85/C2894931 |  | HAND |  | 0.0762 |  |  | 3A Straight Square Pins 2.5mm 8P 6mm -40â„ƒ~+105â„ƒ 3mm 2.54mm Plugin Black 1x8P Plugin,P=2.54mm Pin Headers ROHS |  | JLCPCB | C2894931 |  |  |  |  | PZ254-1-08-Z-8.5 | HCTL
 |  | J4 | Conn_01x08 | Connector_Generic:Conn_01x08 | Connector_PinSocket_2.54mm:PinSocket_1x08_P2.54mm_Vertical | https://jlcpcb.com/partdetail/Hctl-PZ254_1_08_Z_85/C2894931 |  | HAND |  | 0.0762 |  |  | 3A Straight Square Pins 2.5mm 8P 6mm -40â„ƒ~+105â„ƒ 3mm 2.54mm Plugin Black 1x8P Plugin,P=2.54mm Pin Headers ROHS |  | JLCPCB | C2894931 |  |  |  |  | PZ254-1-08-Z-8.5 | HCTL
 |  | J5 | Conn_01x08 | Connector_Generic:Conn_01x08 | Connector_PinSocket_2.54mm:PinSocket_1x08_P2.54mm_Vertical | https://jlcpcb.com/partdetail/Hctl-PZ254_1_08_Z_85/C2894931 |  | HAND |  | 0.0762 |  |  | 3A Straight Square Pins 2.5mm 8P 6mm -40â„ƒ~+105â„ƒ 3mm 2.54mm Plugin Black 1x8P Plugin,P=2.54mm Pin Headers ROHS |  | JLCPCB | C2894931 |  |  |  |  | PZ254-1-08-Z-8.5 | HCTL
 |  | J6 | Conn_01x08 | Connector_Generic:Conn_01x08 | Connector_PinSocket_2.54mm:PinSocket_1x08_P2.54mm_Vertical | https://jlcpcb.com/partdetail/Hctl-PZ254_1_08_Z_85/C2894931 |  | HAND |  | 0.0762 |  |  | 3A Straight Square Pins 2.5mm 8P 6mm -40â„ƒ~+105â„ƒ 3mm 2.54mm Plugin Black 1x8P Plugin,P=2.54mm Pin Headers ROHS |  | JLCPCB | C2894931 |  |  |  |  | PZ254-1-08-Z-8.5 | HCTL
 |  | J7 | Conn_01x10 | Connector_Generic:Conn_01x10 | Connector_PinSocket_2.54mm:PinSocket_1x10_P2.54mm_Vertical | https://jlcpcb.com/partdetail/Hctl-PZ254_1_10_Z_85/C2894933 |  | HAND |  | 0.0942 |  |  | 3A Straight Square Pins 2.5mm 10P 6mm -40â„ƒ~+105â„ƒ 3mm 2.54mm Plugin Black 1x10P Plugin,P=2.54mm Pin Headers ROHS |  | JLCPCB | C2894933 |  |  |  |  | PZ254-1-10-Z-8.5 | HCTL
 |  | J8 | Conn_02x18_Odd_Even | Connector_Generic:Conn_02x18_Odd_Even | Connector_PinSocket_2.54mm:PinSocket_2x18_P2.54mm_Vertical | C132131_DS1023-2_18SF11.pdf |  | HAND |  | 0.3441 |  |  | 2.54mm 2.54mm åŒæŽ’ 36P Straight 2x18P Plugin,P=2.54mm Female Headers ROHS |  | JLCPCB | C132131
 |  | J9 | Conn_01x10 | Connector_Generic:Conn_01x10 | Connector_PinSocket_2.54mm:PinSocket_1x10_P2.54mm_Vertical | https://jlcpcb.com/partdetail/Hctl-PZ254_1_10_Z_85/C2894933 |  | HAND |  | 0.0942 |  |  | 3A Straight Square Pins 2.5mm 10P 6mm -40â„ƒ~+105â„ƒ 3mm 2.54mm Plugin Black 1x10P Plugin,P=2.54mm Pin Headers ROHS |  | JLCPCB | C2894933 |  |  |  |  | PZ254-1-10-Z-8.5 | HCTL
 |  | J10 | Conn_02x12_Odd_Even | Connector_Generic:Conn_02x12_Odd_Even | PubInv_KiCad_PCB.pretty:PinHeader_2x12_P2.00mm_Vertical_JST | https://www.jst-mfg.com/product/pdf/eng/ePHD.pdf |  | HAND |  | 1000000 |  |  |  |  |  |  | JLCPCB | ?https://jlcpcb.com/partdetail/Jst_SalesAmerica-B24B_PHDSS_B_LF_SN/C160327? |  |  |  |  | B24B-PHDSS
 |  | J11 | Screw_Terminal_01x02 | Connector:Screw_Terminal_01x02 | TerminalBlock_TE-Connectivity:TerminalBlock_TE_282834-2_1x02_P2.54mm_Horizontal | DB128V-5.08-2P-GN-S.pdf |  | HAND |  | 0.1537 |  |  | 1x2P 20A -40â„ƒ~+105â„ƒ 300V Green 12~30 Straight pin 5.08mm 2.5 1 2 Plugin,P=5.08mm Screw terminal ROHS |  | JLCPCB | C918120 |  |  |  |  | DB125-2.54-2P-GN-S | DIBO
 |  | J12 | Screw_Terminal_01x02 | Connector:Screw_Terminal_01x02 | TerminalBlock_TE-Connectivity:TerminalBlock_TE_282834-2_1x02_P2.54mm_Horizontal | DB128V-5.08-2P-GN-S.pdf |  | HAND |  | 0.1537 |  |  | 1x2P 20A -40â„ƒ~+105â„ƒ 300V Green 12~30 Straight pin 5.08mm 2.5 1 2 Plugin,P=5.08mm Screw terminal ROHS |  | JLCPCB | C918120 |  |  |  |  | DB125-2.54-2P-GN-S | DIBO
 |  | J13 | Screw_Terminal_01x02 | Connector:Screw_Terminal_01x02 | TerminalBlock_TE-Connectivity:TerminalBlock_TE_282834-2_1x02_P2.54mm_Horizontal | DB128V-5.08-2P-GN-S.pdf |  | HAND |  | 0.1537 |  |  | 1x2P 20A -40â„ƒ~+105â„ƒ 300V Green 12~30 Straight pin 5.08mm 2.5 1 2 Plugin,P=5.08mm Screw terminal ROHS |  | JLCPCB | C918120 |  |  |  |  | DB125-2.54-2P-GN-S | DIBO
 |  | J14 | Conn_01x10 | Connector_Generic:Conn_01x10 | Connector_PinSocket_2.54mm:PinSocket_1x10_P2.54mm_Vertical | https://jlcpcb.com/partdetail/Hctl-PZ254_1_10_Z_85/C2894933 |  | HAND |  | 0.0942 |  |  | 3A Straight Square Pins 2.5mm 10P 6mm -40â„ƒ~+105â„ƒ 3mm 2.54mm Plugin Black 1x10P Plugin,P=2.54mm Pin Headers ROHS |  | JLCPCB | C2894933 |  |  |  |  | PZ254-1-10-Z-8.5 | HCTL
 |  | J15 | DB25_Female_MountingHoles | Connector:DB25_Female_MountingHoles | Connector_Dsub:DSUB-25_Female_Horizontal_P2.77x2.84mm_EdgePinOffset4.94mm_Housed_MountingHolesOffset7.48mm | C190083_D-DMR025PF-D002.pdf |  | HAND |  | 0.7217 |  |  | 25P Female D-Sub Shrouded 2 3A -50â„ƒ~+105â„ƒ Plugin D-Sub/DVI/HDMI Connectors ROHS |  | JLCPCB | C190083 |  |  |  |  | D-DMR025PF-D002 | Ckmtw(Shenzhen Cankemeng)
 |  | J16 | Conn_01x04 | Connector_Generic:Conn_01x04 | Connector_PinHeader_2.54mm:PinHeader_1x04_P2.54mm_Vertical | KH-2.54FH-1X4P-H8.5.pdf |  | HAND |  | 0.0342 |  |  | 2.54mm Plugin 3A 4P -40â„ƒ~+105â„ƒ Straight 1x4P 8.5mm Top Square Holes Plugin,P=2.54mm Female Headers ROHS |  | JLCPCB | C2905415 |  |  |  |  | KH-2.54FH-1X4P-H8.5 | Shenzhen Kinghelm Elec
 |  | J17 | Conn_01x05 | Connector_Generic:Conn_01x05 | Connector_PinHeader_2.54mm:PinHeader_1x05_P2.54mm_Vertical | C2897368_PM254-1-05-Z-8.5.pdf |  | HAND |  | 0.0791 |  |  | 2.54mm Plugin 3A 5P -40â„ƒ~+105â„ƒ Straight 1x5P 8.5mm Top Square Holes Plugin,P=2.54mm Female Headers ROHS |  | JLCPCB | C2897368 |  |  |  |  | PM254-1-05-Z-8.5 | HCTL
 |  | J18 | Conn_01x04 | Connector_Generic:Conn_01x04 | Connector_PinHeader_2.54mm:PinHeader_1x04_P2.54mm_Vertical | KH-2.54FH-1X4P-H8.5.pdf |  | HAND |  | 0.0342 |  |  | 2.54mm Plugin 3A 4P -40â„ƒ~+105â„ƒ Straight 1x4P 8.5mm Top Square Holes Plugin,P=2.54mm Female Headers ROHS |  | JLCPCB | C2905415 |  |  |  |  | KH-2.54FH-1X4P-H8.5 | Shenzhen Kinghelm Elec
 |  | J19 | Conn_01x07 | Connector_Generic:Conn_01x07 | Connector_PinHeader_2.54mm:PinHeader_1x07_P2.54mm_Vertical | C2932672_KH-2.54FH-1X7P-H8.5.pdf |  | HAND |  | 0.0543 |  |  | 2.54mm Plugin 3A 7P -40â„ƒ~+105â„ƒ Straight 1x7P 8.5mm Top Square Holes Plugin,P=2.54mm Female Headers ROHS |  | JLCPCB | C2932672
 |  | J20 | Conn_01x04 | Connector:Conn_01x04_Pin | Connector_PinHeader_2.54mm:PinHeader_1x04_P2.54mm_Vertical | KH-2.54FH-1X4P-H8.5.pdf |  | HAND |  | 0.0342 |  |  | 2.54mm Plugin 3A 4P -40â„ƒ~+105â„ƒ Straight 1x4P 8.5mm Top Square Holes Plugin,P=2.54mm Female Headers ROHS |  | JLCPCB | C2905415 |  |  |  |  | KH-2.54FH-1X4P-H8.5 | Shenzhen Kinghelm Elec
 |  | J21 | RJ12_6P6C_HORZ | GPAD_SCH_LIB:RJ12_6P6C_HORZ | PubInv_KiCad_PCB:RJ12_Amphenol_54601 | https://datasheet.lcsc.com/lcsc/1811141146_TE-Connectivity-5555165-1_C305981.pdf |  | HAND |  | 0.8901 |  |  | Jack Modular Connector 6p6c (RJ11, RJ12, RJ14, RJ25) 90Â° Angle (Right) Unshielded Cat3 |  | JLCPCB | C305981 | Digikey | A31422-ND |  | YES | 5555165-1 | TE Connectivity
 |  | J22 | 0.100_2Pin | GPAD_SCH_LIB:22-23-2021 | Connector_PinHeader_2.54mm:PinHeader_1x02_P2.54mm_Vertical | https://datasheet.lcsc.com/lcsc/1811011511_Amphenol-ICC-68000-102HLF_C168673.pdf | HAND | HAND | Connectors, Interconnects | 0.1458 | https://media.digikey.com/pdf/Data%20Sheets/Molex%20PDFs/A-6373-N_Series_Dwg_2010-12-03.pdf | /product-detail/en/molex/22-23-2021/WM4200-ND/26667 | HEADER VERT 2POS 2.54MM | WM4200-ND | JLCPCB | C168673 |  |  | Rectangular Connectors - Headers, Male Pins | YES | 68000-102HLF | Amphenol ICC |  | Active
 |  | J23 | 0.100_2Pin | GPAD_SCH_LIB:22-23-2021 | Connector_PinHeader_2.54mm:PinHeader_1x02_P2.54mm_Vertical | https://datasheet.lcsc.com/lcsc/1811011511_Amphenol-ICC-68000-102HLF_C168673.pdf | HAND | HAND | Connectors, Interconnects | 0.1458 | https://media.digikey.com/pdf/Data%20Sheets/Molex%20PDFs/A-6373-N_Series_Dwg_2010-12-03.pdf | /product-detail/en/molex/22-23-2021/WM4200-ND/26667 | HEADER VERT 2POS 2.54MM | WM4200-ND | JLCPCB | C168673 |  |  | Rectangular Connectors - Headers, Male Pins | YES | 68000-102HLF | Amphenol ICC |  | Active
 |  | J24 | Conn_01x04 | Connector_Generic:Conn_01x04 | Connector_PinHeader_2.54mm:PinHeader_1x04_P2.54mm_Vertical | KH-2.54FH-1X4P-H8.5.pdf |  | HAND |  | 0.0342 |  |  | 2.54mm Plugin 3A 4P -40â„ƒ~+105â„ƒ Straight 1x4P 8.5mm Top Square Holes Plugin,P=2.54mm Female Headers ROHS |  | JLCPCB | C2905415 |  |  |  |  | KH-2.54FH-1X4P-H8.5 | Shenzhen Kinghelm Elec
 |  | J25 | Screw_Terminal_01x02 | Connector:Screw_Terminal_01x02 | TerminalBlock_TE-Connectivity:TerminalBlock_TE_282834-2_1x02_P2.54mm_Horizontal | DB128V-5.08-2P-GN-S.pdf |  | HAND |  | 0.1537 |  |  | 1x2P 20A -40â„ƒ~+105â„ƒ 300V Green 12~30 Straight pin 5.08mm 2.5 1 2 Plugin,P=5.08mm Screw terminal ROHS |  | JLCPCB | C918120 |  |  |  |  | DB125-2.54-2P-GN-S | DIBO
 |  | J26 | Conn_01x10 | Connector_Generic:Conn_01x10 | Connector_PinSocket_2.54mm:PinSocket_1x10_P2.54mm_Vertical | https://jlcpcb.com/partdetail/Hctl-PZ254_1_10_Z_85/C2894933 |  | HAND |  | 0.0942 |  |  | 3A Straight Square Pins 2.5mm 10P 6mm -40â„ƒ~+105â„ƒ 3mm 2.54mm Plugin Black 1x10P Plugin,P=2.54mm Pin Headers ROHS |  | JLCPCB | C2894933 |  |  |  |  | PZ254-1-10-Z-8.5 | HCTL
 |  | J27 | Conn_02x12_Odd_Even | Connector_Generic:Conn_02x12_Odd_Even | PubInv_KiCad_PCB.pretty:PinHeader_2x12_P2.00mm_Vertical_JST | https://www.jst-mfg.com/product/pdf/eng/ePHD.pdf |  | HAND |  | 1000000 |  |  |  |  |  |  | JLCPCB | ?https://jlcpcb.com/partdetail/Jst_SalesAmerica-B24B_PHDSS_B_LF_SN/C160327? |  |  |  |  | B24B-PHDSS
 |  | J28 | Screw_Terminal_01x02 | Connector:Screw_Terminal_01x02 | TerminalBlock_TE-Connectivity:TerminalBlock_TE_282834-2_1x02_P2.54mm_Horizontal | DB128V-5.08-2P-GN-S.pdf |  | HAND |  | 0.1537 |  |  | 1x2P 20A -40â„ƒ~+105â„ƒ 300V Green 12~30 Straight pin 5.08mm 2.5 1 2 Plugin,P=5.08mm Screw terminal ROHS |  | JLCPCB | C918120 |  |  |  |  | DB125-2.54-2P-GN-S | DIBO
 |  | J29 | Conn_01x10 | Connector_Generic:Conn_01x10 | Connector_PinSocket_2.54mm:PinSocket_1x10_P2.54mm_Vertical | https://jlcpcb.com/partdetail/Hctl-PZ254_1_10_Z_85/C2894933 |  | HAND |  | 0.0942 |  |  | 3A Straight Square Pins 2.5mm 10P 6mm -40â„ƒ~+105â„ƒ 3mm 2.54mm Plugin Black 1x10P Plugin,P=2.54mm Pin Headers ROHS |  | JLCPCB | C2894933 |  |  |  |  | PZ254-1-10-Z-8.5 | HCTL
 |  | J30 | Screw_Terminal_01x02 | Connector:Screw_Terminal_01x02 | TerminalBlock_TE-Connectivity:TerminalBlock_TE_282834-2_1x02_P2.54mm_Horizontal | DB128V-5.08-2P-GN-S.pdf |  | HAND |  | 0.1537 |  |  | 1x2P 20A -40â„ƒ~+105â„ƒ 300V Green 12~30 Straight pin 5.08mm 2.5 1 2 Plugin,P=5.08mm Screw terminal ROHS |  | JLCPCB | C918120 |  |  |  |  | DB125-2.54-2P-GN-S | DIBO
 |  | J31 | Screw_Terminal_01x02 | Connector:Screw_Terminal_01x02 | TerminalBlock_TE-Connectivity:TerminalBlock_TE_282834-2_1x02_P2.54mm_Horizontal | DB128V-5.08-2P-GN-S.pdf |  | HAND |  | 0.1537 |  |  | 1x2P 20A -40â„ƒ~+105â„ƒ 300V Green 12~30 Straight pin 5.08mm 2.5 1 2 Plugin,P=5.08mm Screw terminal ROHS |  | JLCPCB | C918120 |  |  |  |  | DB125-2.54-2P-GN-S | DIBO
 |  | J32 | Screw_Terminal_01x02 | Connector:Screw_Terminal_01x02 | TerminalBlock_TE-Connectivity:TerminalBlock_TE_282834-2_1x02_P2.54mm_Horizontal | DB128V-5.08-2P-GN-S.pdf |  | HAND |  | 0.1537 |  |  | 1x2P 20A -40â„ƒ~+105â„ƒ 300V Green 12~30 Straight pin 5.08mm 2.5 1 2 Plugin,P=5.08mm Screw terminal ROHS |  | JLCPCB | C918120 |  |  |  |  | DB125-2.54-2P-GN-S | DIBO
 |  | J33 | Screw_Terminal_01x02 | Connector:Screw_Terminal_01x02 | TerminalBlock_TE-Connectivity:TerminalBlock_TE_282834-2_1x02_P2.54mm_Horizontal | DB128V-5.08-2P-GN-S.pdf |  | HAND |  | 0.1537 |  |  | 1x2P 20A -40â„ƒ~+105â„ƒ 300V Green 12~30 Straight pin 5.08mm 2.5 1 2 Plugin,P=5.08mm Screw terminal ROHS |  | JLCPCB | C918120 |  |  |  |  | DB125-2.54-2P-GN-S | DIBO
 |  | J34 | Screw_Terminal_01x02 | Connector:Screw_Terminal_01x02 | TerminalBlock_TE-Connectivity:TerminalBlock_TE_282834-2_1x02_P2.54mm_Horizontal | DB128V-5.08-2P-GN-S.pdf |  | HAND |  | 0.1537 |  |  | 1x2P 20A -40â„ƒ~+105â„ƒ 300V Green 12~30 Straight pin 5.08mm 2.5 1 2 Plugin,P=5.08mm Screw terminal ROHS |  | JLCPCB | C918120 |  |  |  |  | DB125-2.54-2P-GN-S | DIBO
 |  | JP1 | SolderJumper_3_Bridged12 | Jumper:SolderJumper_3_Bridged12 | Jumper:SolderJumper-3_P1.3mm_Bridged12_RoundedPad1.0x1.5mm | NA |  | DNI |  | 0 |  |  | SolderJumper_3_Bridged12 |  | PublicInvention | NA |  |  |  |  | NA | NA
 |  | JP2 | SolderJumper_3_Bridged12 | Jumper:SolderJumper_3_Bridged12 | Jumper:SolderJumper-3_P1.3mm_Bridged12_RoundedPad1.0x1.5mm | NA |  | DNI |  | 0 |  |  | SolderJumper_3_Bridged12 |  | PublicInvention | NA |  |  |  |  | NA | NA
 |  | JP3 | SolderJumper_3_Bridged12 | Jumper:SolderJumper_3_Bridged12 | Jumper:SolderJumper-3_P1.3mm_Bridged12_RoundedPad1.0x1.5mm | NA |  | DNI |  | 0 |  |  | SolderJumper_3_Bridged12 |  | PublicInvention | NA |  |  |  |  | NA | NA
 |  | JP4 | SolderJumper_3_Bridged12 | Jumper:SolderJumper_3_Bridged12 | Jumper:SolderJumper-3_P1.3mm_Bridged12_RoundedPad1.0x1.5mm | NA |  | DNI |  | 0 |  |  | SolderJumper_3_Bridged12 |  | PublicInvention | NA |  |  |  |  | NA | NA
 |  | JP5 | SolderJumper_3_Bridged12 | Jumper:SolderJumper_3_Bridged12 | Jumper:SolderJumper-3_P1.3mm_Bridged12_RoundedPad1.0x1.5mm | NA |  | DNI |  | 0 |  |  | SolderJumper_3_Bridged12 |  | PublicInvention | NA |  |  |  |  | NA | NA
 |  | JP6 | SolderJumper_3_Bridged12 | Jumper:SolderJumper_3_Bridged12 | Jumper:SolderJumper-3_P1.3mm_Bridged12_RoundedPad1.0x1.5mm | NA |  | DNI |  | 0 |  |  | SolderJumper_3_Bridged12 |  | PublicInvention | NA |  |  |  |  | NA | NA
 |  | JP7 | SolderJumper_3_Bridged12 | Jumper:SolderJumper_3_Bridged12 | Jumper:SolderJumper-3_P1.3mm_Bridged12_RoundedPad1.0x1.5mm | NA |  | DNI |  | 0 |  |  | SolderJumper_3_Bridged12 |  | PublicInvention | NA |  |  |  |  | NA | NA
 |  | JP8 | SolderJumper_3_Bridged12 | Jumper:SolderJumper_3_Bridged12 | Jumper:SolderJumper-3_P1.3mm_Bridged12_RoundedPad1.0x1.5mm | NA |  | DNI |  | 0 |  |  | SolderJumper_3_Bridged12 |  | PublicInvention | NA |  |  |  |  | NA | NA
 |  | JP9 | MAX31850K | Connector_Generic:Conn_01x08 | PubInv_KiCad_PCB:Adafruit_MAX31850K_Module | https://www.adafruit.com/product/1727 |  | HAND |  | 14.95 |  |  | Thermocouple Amplifier with 1-Wire Breakout Board - MAX31850K |  | adafruit | 1727 |  |  |  |  | 1727 | Adafruit
 |  | JP10 | MAX31850K | Control v1-eagle-import:microbuilder_HEADER-1X870MIL | PubInv_KiCad_PCB:Adafruit_MAX31850K_Module | https://www.adafruit.com/product/1727 |  | HAND |  | 14.95 |  |  | Thermocouple Amplifier with 1-Wire Breakout Board - MAX31850K |  | adafruit | 1727 |  |  |  |  | 1727 | Adafruit
 |  | JP11 | SolderJumper_3_Bridged12 | Jumper:SolderJumper_3_Bridged12 | Jumper:SolderJumper-3_P1.3mm_Bridged12_RoundedPad1.0x1.5mm | NA |  | DNI |  | 0 |  |  | SolderJumper_3_Bridged12 |  | PublicInvention | NA |  |  |  |  | NA | NA
 |  | JP12 | SolderJumper_3_Bridged12 | Jumper:SolderJumper_3_Bridged12 | Jumper:SolderJumper-3_P1.3mm_Bridged12_RoundedPad1.0x1.5mm | NA |  | DNI |  | 0 |  |  | SolderJumper_3_Bridged12 |  | PublicInvention | NA |  |  |  |  | NA | NA
 |  | JP13 | SolderJumper_3_Bridged12 | Jumper:SolderJumper_3_Bridged12 | Jumper:SolderJumper-3_P1.3mm_Bridged12_RoundedPad1.0x1.5mm | NA |  | DNI |  | 0 |  |  | SolderJumper_3_Bridged12 |  | PublicInvention | NA |  |  |  |  | NA | NA
 |  | JP14 | SolderJumper_3_Bridged12 | Jumper:SolderJumper_3_Bridged12 | Jumper:SolderJumper-3_P1.3mm_Bridged12_RoundedPad1.0x1.5mm | NA |  | DNI |  | 0 |  |  | SolderJumper_3_Bridged12 |  | PublicInvention | NA |  |  |  |  | NA | NA
 |  | JP15 | MAX31850K | Control v1-eagle-import:microbuilder_HEADER-1X870MIL | PubInv_KiCad_PCB:Adafruit_MAX31850K_Module | https://www.adafruit.com/product/1727 |  | HAND |  | 14.95 |  |  | Thermocouple Amplifier with 1-Wire Breakout Board - MAX31850K |  | adafruit | 1727 |  |  |  |  | 1727 | Adafruit
 |  | JP16 | MAX31855 | Control v1-eagle-import:HEADER-1X676MIL | PubInv_KiCad_PCB:Adafruit_MAX31855_Module | https://www.adafruit.com/product/269 |  | HAND |  | 14.95 |  |  | Thermocouple Amplifier MAX31855 breakout board (MAX6675 upgrade) |  | adafruit | 269 |  |  |  |  | 269 | Adafruit
 |  | JP17 | MAX31855 | Control v1-eagle-import:HEADER-1X676MIL | PubInv_KiCad_PCB:Adafruit_MAX31855_Module | https://www.adafruit.com/product/269 |  | HAND |  | 14.95 |  |  | Thermocouple Amplifier MAX31855 breakout board (MAX6675 upgrade) |  | adafruit | 269 |  |  |  |  | 269 | Adafruit
 |  | JP18 | MAX31855 | Control v1-eagle-import:HEADER-1X676MIL | PubInv_KiCad_PCB:Adafruit_MAX31855_Module | https://www.adafruit.com/product/269 |  | HAND |  | 14.95 |  |  | Thermocouple Amplifier MAX31855 breakout board (MAX6675 upgrade) |  | adafruit | 269 |  |  |  |  | 269 | Adafruit
 |  | JP19 | MCP9600 | Control v1-eagle-import:HEADER-1X970MIL | PubInv_KiCad_PCB:Adafruit_MCP9600_Module | https://www.adafruit.com/product/4101 |  | HAND |  | 15.95 |  |  | Adafruit MCP9600 I2C Thermocouple Amplifier - K, J, T, N, S, E, B and R Type T |  | adafruit | 4101 |  |  |  |  | 4101 | Adafruit
 |  | JP20 | MCP9600 | Control v1-eagle-import:HEADER-1X970MIL | PubInv_KiCad_PCB:Adafruit_MCP9600_Module | https://www.adafruit.com/product/4101 |  | HAND |  | 15.95 |  |  | Adafruit MCP9600 I2C Thermocouple Amplifier - K, J, T, N, S, E, B and R Type T |  | adafruit | 4101 |  |  |  |  | 4101 | Adafruit
 |  | JP21 | MCP9600 | Control v1-eagle-import:HEADER-1X970MIL | PubInv_KiCad_PCB:Adafruit_MCP9600_Module | https://www.adafruit.com/product/4101 |  | HAND |  | 15.95 |  |  | Adafruit MCP9600 I2C Thermocouple Amplifier - K, J, T, N, S, E, B and R Type T |  | adafruit | 4101 |  |  |  |  | 4101 | Adafruit
 |  | MF1 | PCB_BKT_OEDCS_01 | GPAD_SCH_LIB:PCB_GPAD_VER1 | NA | PCB_BKT_OEDCS_01 |  | HAND |  | 1000000 |  |  | PCB_BKT_OEDCS_01 |  | PublicInvention | PCB_BKT_OEDCS_01 |  |  |  | YES | PCB_BKT_OEDCS_01 | PublicInvention
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

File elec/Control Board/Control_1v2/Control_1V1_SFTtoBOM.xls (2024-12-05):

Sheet: Instructions
Instructions for using this spread sheet.
These instructions apply to KiCad 6 and modified for KiCad 7 |  | KiCad BOM generator
Using OpenOffice Calc spread sheet features.
 | This spread sheet is for processing the CSV BOM file generated by KiCad into a form useful for ordering parts and assemblies. It assumes you understand the spread sheet enough to edit the formulas which must change to accommodate the exact number of unique components in a schematic. To the right are screen shots to help you recognize some of the steps described below.
Step# | Description
1 | Using the KiCAD BOM generator “bom_csv_grouped_by_value” generate the “Bill of Materals” CSV file. Rename the file as appropriate to describe the build event.
2 | Open this spread sheet. Save as a new name as appropriate
3 | Open the file from step one OpenOffice CALC by “Text Import” the CSV file in and set for separate by comma delimited fields. This will open in a separate spread sheet. Select the entire contents by clicking on the top cell to the left of “A” column. Copy with <Ctrl>C.
4 | Past into the RAW tab of this spread sheet. To do so, again select the entire RAW sheet by clicking on the top cell to the left of the “A” column. Then Past with <Ctrl>V. Examine the rows till you locate the row “Collated Components:” where several lines below the BOM begins with a row the first cell of which is “item”.
5 | In the BOMNoSort tab on row 5, edit the formula cell by cell to adjust the start of the copy from the row in the RAW tab with the column description cell in the RAW input of the BOM fields. Note the cell copy are not consecutive going to the right an as a consequence the BOMB spread sheet reorders and selects only the information most useful for ordering parts. | OOCalc file import dialog
6 | Copy the BOM_NoSort table into the BOM tab.
7 | Sort the BOM by distributor type (column G) to break out the parts for easy ordering.
8 | Copy the rows with JLCPCB parts from BOM to BOM_JCLPCB tab
9 | Copy the BOM_JLCPCB tab and special past into BOM_JLCPCB_Values for clear text. Save this page as a CSV for example.
 | Use a corresponding process for the PL (Parts List) tab.
 | BOM column headings needed
 |  | Finding the BOM cell A5 and pressing F2 to edit the formula. In this case already set for cell A85
 |  | The formulas in row 5 have been copied down to row 35 which for this BOM includes one empty row of the RAW tab.
 |  | The formulas in PL row 5 have been copied down to row 5 which for this split view of the Parts List includes one empty row of the RAW tab.

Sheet: BOM_NoSort
Selected BOM Report |  |  | A “BOM” has one row per part number.
0 |  |  |  |  |  |  |  |  | Manually Adjust the total part cost summation range |  |  |  | Manually Adjust the total part cost summation range
0 | 0 |  |  |  |  |  |  |  | Total Part Cost= | 0 |  |  | Total Part Cost= | 0
0 | 0 | 0 | 0 | 0 | 0 | 0 | 0 | 0 | 0 | 0 | 0 | 0 | 0 | Extended Cost
0 | 0 | 0 | 0 | 0 | 0 | 0 | 0 | 0 | 0 | 0 | 0 | 0 | 0 | Extended Cost
0 | 0 | 0 | 0 | 0 | 0 | 0 | 0 | 0 | 0 | 0 | 0 | 0 | 0 | Extended Cost
0 | 0 | 0 | 0 | 0 | 0 | 0 | 0 | 0 | 0 | 0 | 0 | 0 | 0 | Extended Cost
0 | 0 | 0 | 0 | 0 | 0 | 0 | 0 | 0 | 0 | 0 | 0 | 0 | 0 | Extended Cost
0 | 0 | 0 | 0 | 0 | 0 | 0 | 0 | 0 | 0 | 0 | 0 | 0 | 0 | Extended Cost
0 | 0 | 0 | 0 | 0 | 0 | 0 | 0 | 0 | 0 | 0 | 0 | 0 | 0 | Extended Cost
0 | 0 | 0 | 0 | 0 | 0 | 0 | 0 | 0 | 0 | 0 | 0 | 0 | 0 | Extended Cost
0 | 0 | 0 | 0 | 0 | 0 | 0 | 0 | 0 | 0 | 0 | 0 | 0 | 0 | Extended Cost
0 | 0 | 0 | 0 | 0 | 0 | 0 | 0 | 0 | 0 | 0 | 0 | 0 | 0 | Extended Cost
0 | 0 | 0 | 0 | 0 | 0 | 0 | 0 | 0 | 0 | 0 | 0 | 0 | 0 | Extended Cost
0 | 0 | 0 | 0 | 0 | 0 | 0 | 0 | 0 | 0 | 0 | 0 | 0 | 0 | Extended Cost
0 | 0 | 0 | 0 | 0 | 0 | 0 | 0 | 0 | 0 | 0 | 0 | 0 | 0 | Extended Cost
0 | 0 | 0 | 0 | 0 | 0 | 0 | 0 | 0 | 0 | 0 | 0 | 0 | 0 | Extended Cost
0 | 0 | 0 | 0 | 0 | 0 | 0 | 0 | 0 | 0 | 0 | 0 | 0 | 0 | Extended Cost
0 | 0 | 0 | 0 | 0 | 0 | 0 | 0 | 0 | 0 | 0 | 0 | 0 | 0 | Extended Cost
0 | 0 | 0 | 0 | 0 | 0 | 0 | 0 | 0 | 0 | 0 | 0 | 0 | 0 | Extended Cost
0 | 0 | 0 | 0 | 0 | 0 | 0 | 0 | 0 | 0 | 0 | 0 | 0 | 0 | Extended Cost
0 | 0 | 0 | 0 | 0 | 0 | 0 | 0 | 0 | 0 | 0 | 0 | 0 | 0 | Extended Cost
0 | 0 | 0 | 0 | 0 | 0 | 0 | 0 | 0 | 0 | 0 | 0 | 0 | 0 | Extended Cost
0 | 0 | 0 | 0 | 0 | 0 | 0 | 0 | 0 | 0 | 0 | 0 | 0 | 0 | Extended Cost
0 | 0 | 0 | 0 | 0 | 0 | 0 | 0 | 0 | 0 | 0 | 0 | 0 | 0 | Extended Cost
0 | 0 | 0 | 0 | 0 | 0 | 0 | 0 | 0 | 0 | 0 | 0 | 0 | 0 | Extended Cost
0 | 0 | 0 | 0 | 0 | 0 | 0 | 0 | 0 | 0 | 0 | 0 | 0 | 0 | Extended Cost
0 | 0 | 0 | 0 | 0 | 0 | 0 | 0 | 0 | 0 | 0 | 0 | 0 | 0 | Extended Cost
0 | 0 | 0 | 0 | 0 | 0 | 0 | 0 | 0 | 0 | 0 | 0 | 0 | 0 | Extended Cost
0 | 0 | 0 | 0 | 0 | 0 | 0 | 0 | 0 | 0 | 0 | 0 | 0 | 0 | Extended Cost
0 | 0 | 0 | 0 | 0 | 0 | 0 | 0 | 0 | 0 | 0 | 0 | 0 | 0 | Extended Cost
0 | 0 | 0 | 0 | 0 | 0 | 0 | 0 | 0 | 0 | 0 | 0 | 0 | 0 | Extended Cost
0 | 0 | 0 | 0 | 0 | 0 | 0 | 0 | 0 | 0 | 0 | 0 | 0 | 0 | Extended Cost
0 | 0 | 0 | 0 | 0 | 0 | 0 | 0 | 0 | 0 | 0 | 0 | 0 | 0 | Extended Cost
0 | 0 | 0 | 0 | 0 | 0 | 0 | 0 | 0 | 0 | 0 | 0 | 0 | 0 | Extended Cost
0 | 0 | 0 | 0 | 0 | 0 | 0 | 0 | 0 | 0 | 0 | 0 | 0 | 0 | Extended Cost
0 | 0 | 0 | 0 | 0 | 0 | 0 | 0 | 0 | 0 | 0 | 0 | 0 | 0 | Extended Cost
0 | 0 | 0 | 0 | 0 | 0 | 0 | 0 | 0 | 0 | 0 | 0 | 0 | 0 | Extended Cost
0 | 0 | 0 | 0 | 0 | 0 | 0 | 0 | 0 | 0 | 0 | 0 | 0 | 0 | Extended Cost
0 | 0 | 0 | 0 | 0 | 0 | 0 | 0 | 0 | 0 | 0 | 0 | 0 | 0 | Extended Cost
0 | 0 | 0 | 0 | 0 | 0 | 0 | 0 | 0 | 0 | 0 | 0 | 0 | 0 | Extended Cost
0 | 0 | 0 | 0 | 0 | 0 | 0 | 0 | 0 | 0 | 0 | 0 | 0 | 0 | Extended Cost
0 | 0 | 0 | 0 | 0 | 0 | 0 | 0 | 0 | 0 | 0 | 0 | 0 | 0 | Extended Cost
0 | 0 | 0 | 0 | 0 | 0 | 0 | 0 | 0 | 0 | 0 | 0 | 0 | 0 | Extended Cost
0 | 0 | 0 | 0 | 0 | 0 | 0 | 0 | 0 | 0 | 0 | 0 | 0 | 0 | Extended Cost
0 | 0 | 0 | 0 | 0 | 0 | 0 | 0 | 0 | 0 | 0 | 0 | 0 | 0 | Extended Cost
0 | 0 | 0 | 0 | 0 | 0 | 0 | 0 | 0 | 0 | 0 | 0 | 0 | 0 | Extended Cost
0 | 0 | 0 | 0 | 0 | 0 | 0 | 0 | 0 | 0 | 0 | 0 | 0 | 0 | Extended Cost
0 | 0 | 0 | 0 | 0 | 0 | 0 | 0 | 0 | 0 | 0 | 0 | 0 | 0 | Extended Cost
0 | 0 | 0 | 0 | 0 | 0 | 0 | 0 | 0 | 0 | 0 | 0 | 0 | 0 | Extended Cost
0 | 0 | 0 | 0 | 0 | 0 | 0 | 0 | 0 | 0 | 0 | 0 | 0 | 0 | Extended Cost
0 | 0 | 0 | 0 | 0 | 0 | 0 | 0 | 0 | 0 | 0 | 0 | 0 | 0 | Extended Cost
0 | 0 | 0 | 0 | 0 | 0 | 0 | 0 | 0 | 0 | 0 | 0 | 0 | 0 | Extended Cost
0 | 0 | 0 | 0 | 0 | 0 | 0 | 0 | 0 | 0 | 0 | 0 | 0 | 0 | Extended Cost
0 | 0 | 0 | 0 | 0 | 0 | 0 | 0 | 0 | 0 | 0 | 0 | 0 | 0 | Extended Cost
0 | 0 | 0 | 0 | 0 | 0 | 0 | 0 | 0 | 0 | 0 | 0 | 0 | 0 | Extended Cost
0 | 0 | 0 | 0 | 0 | 0 | 0 | 0 | 0 | 0 | 0 | 0 | 0 | 0 | Extended Cost
0 | 0 | 0 | 0 | 0 | 0 | 0 | 0 | 0 | 0 | 0 | 0 | 0 | 0 | Extended Cost
0 | 0 | 0 | 0 | 0 | 0 | 0 | 0 | 0 | 0 | 0 | 0 | 0 | 0 | Extended Cost
0 | 0 | 0 | 0 | 0 | 0 | 0 | 0 | 0 | 0 | 0 | 0 | 0 | 0 | Extended Cost
0 | 0 | 0 | 0 | 0 | 0 | 0 | 0 | 0 | 0 | 0 | 0 | 0 | 0 | Extended Cost
0 | 0 | 0 | 0 | 0 | 0 | 0 | 0 | 0 | 0 | 0 | 0 | 0 | 0 | Extended Cost
0 | 0 | 0 | 0 | 0 | 0 | 0 | 0 | 0 | 0 | 0 | 0 | 0 | 0 | Extended Cost
0 | 0 | 0 | 0 | 0 | 0 | 0 | 0 | 0 | 0 | 0 | 0 | 0 | 0 | Extended Cost
0 | 0 | 0 | 0 | 0 | 0 | 0 | 0 | 0 | 0 | 0 | 0 | 0 | 0 | Extended Cost
0 | 0 | 0 | 0 | 0 | 0 | 0 | 0 | 0 | 0 | 0 | 0 | 0 | 0 | Extended Cost
0 | 0 | 0 | 0 | 0 | 0 | 0 | 0 | 0 | 0 | 0 | 0 | 0 | 0 | Extended Cost
0 | 0 | 0 | 0 | 0 | 0 | 0 | 0 | 0 | 0 | 0 | 0 | 0 | 0 | Extended Cost
0 | 0 | 0 | 0 | 0 | 0 | 0 | 0 | 0 | 0 | 0 | 0 | 0 | 0 | Extended Cost
0 | 0 | 0 | 0 | 0 | 0 | 0 | 0 | 0 | 0 | 0 | 0 | 0 | 0 | Extended Cost
0 | 0 | 0 | 0 | 0 | 0 | 0 | 0 | 0 | 0 | 0 | 0 | 0 | 0 | Extended Cost
0 | 0 | 0 | 0 | 0 | 0 | 0 | 0 | 0 | 0 | 0 | 0 | 0 | 0 | Extended Cost
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

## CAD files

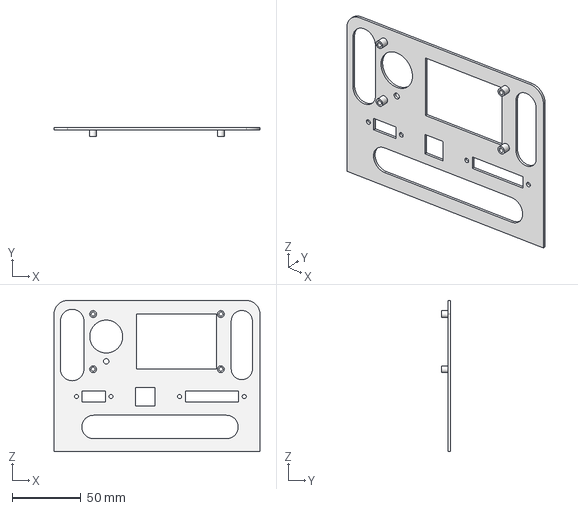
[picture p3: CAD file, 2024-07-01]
elec/Control Board/Control_1v1/MountMini12864/MountMini12864-Part_MountMini12864Body_MountMini12864_c.step
150.0 x 6.35 x 110.0 mm

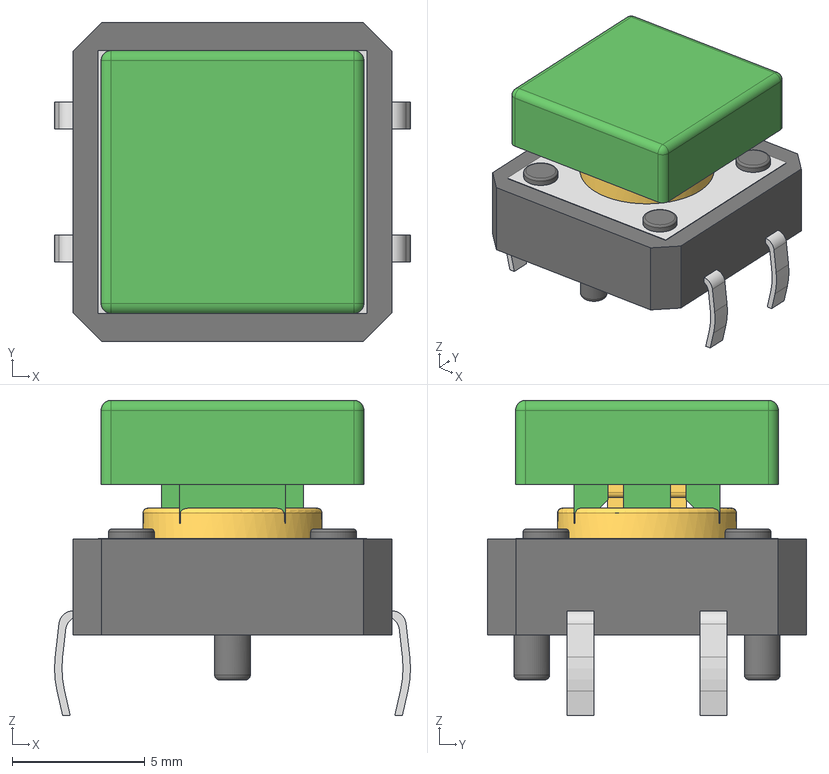
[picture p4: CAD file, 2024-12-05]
elec/Control Board/Control_1v2/PublicInvention_KiCad_Library/Parts/12mmx12mm With Green cap.stp
13.4 x 12.0 x 11.9 mm
Tactal Switch - THRU(12mmx12mmx__mm)-Square Yellow
12mm Cap

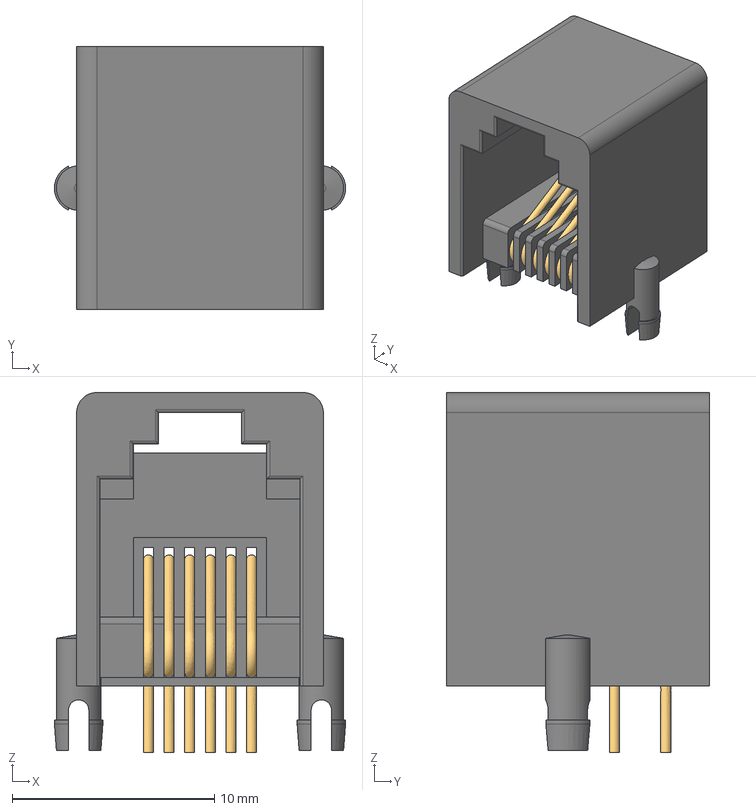
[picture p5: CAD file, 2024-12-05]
elec/Control Board/Control_1v2/PublicInvention_KiCad_Library/Parts/rj11-connectors-6p-1.snapshot.1/rj-69-horiz-615006138421 (rev1).stp
14.4 x 13.0 x 17.8 mm
615006138421_PIN x 3
615006138421_PIN_LONGUE x 3
6150xx138421

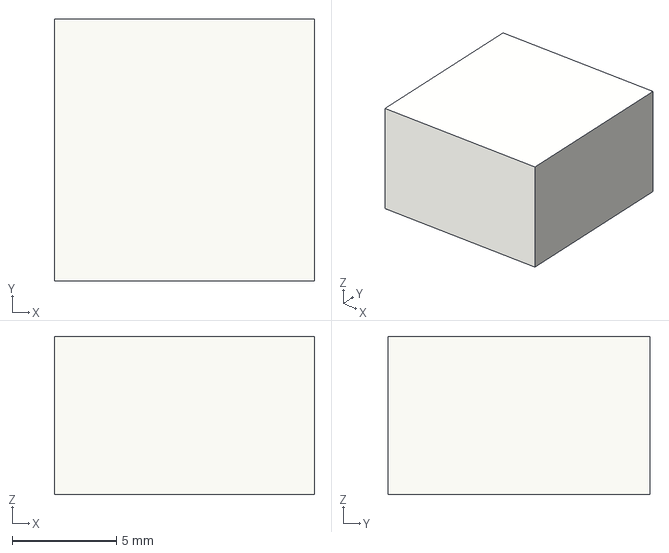
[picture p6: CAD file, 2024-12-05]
elec/Control Board/Control_1v2/PublicInvention_KiCad_Library/Parts/S04B-XASK-1/Cube.step
12.5 x 12.6 x 7.59 mm

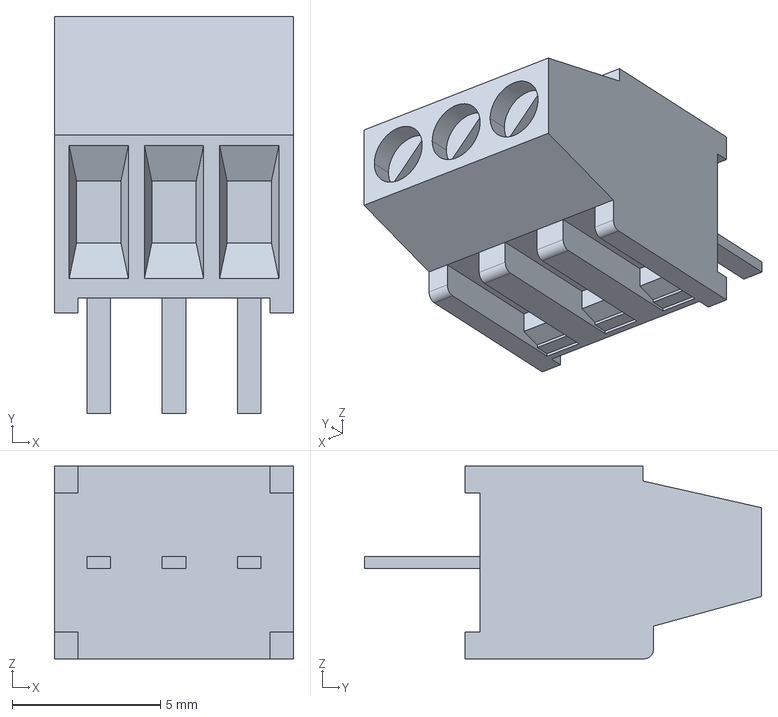
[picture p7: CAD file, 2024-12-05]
elec/Control Board/Control_1v2/PublicInvention_KiCad_Library/Parts/TEConnect/ENG_CVM_CVM_282834-3_C.3d_stp/c-282834-3-c-3d.stp
8.08 x 13.4 x 6.50 mm

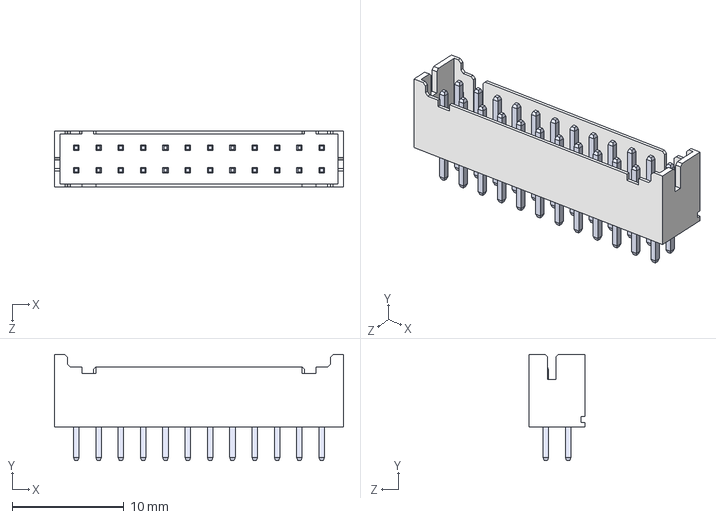
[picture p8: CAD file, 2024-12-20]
elec/Control Board/Control_1v2/resources/B24B/B24B-PHDSS-B-LF--SN---3DModel-STEP-56544.STEP
25.9 x 9.50 x 5.00 mm
BxB-PHDSS_24
pin^BxB-PHDSS ass x 24

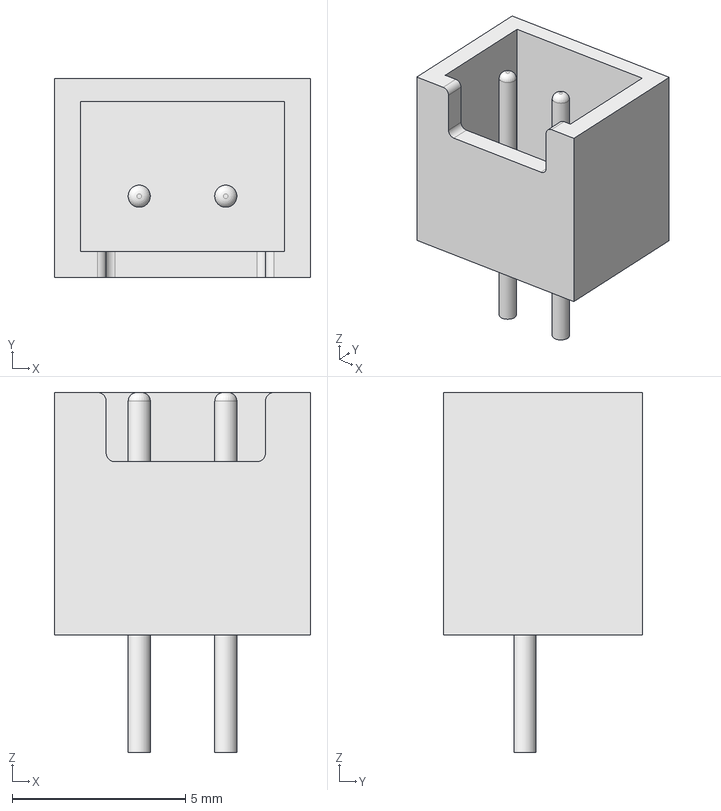
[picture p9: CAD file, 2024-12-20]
elec/Control Board/Control_1v2/resources/B2B-XH-A-GU_MODEL.step
7.40 x 5.75 x 10.4 mm

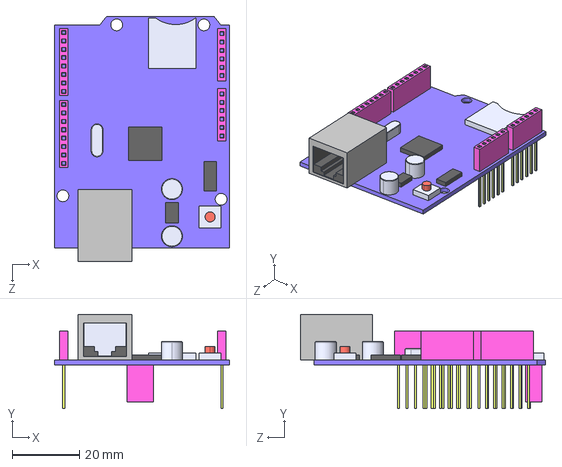
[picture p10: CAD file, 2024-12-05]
elec/Control Board/Control_1v2/resources/Due/Ethernet_shield_Arduino.STEP
52.0 x 28.0 x 72.8 mm

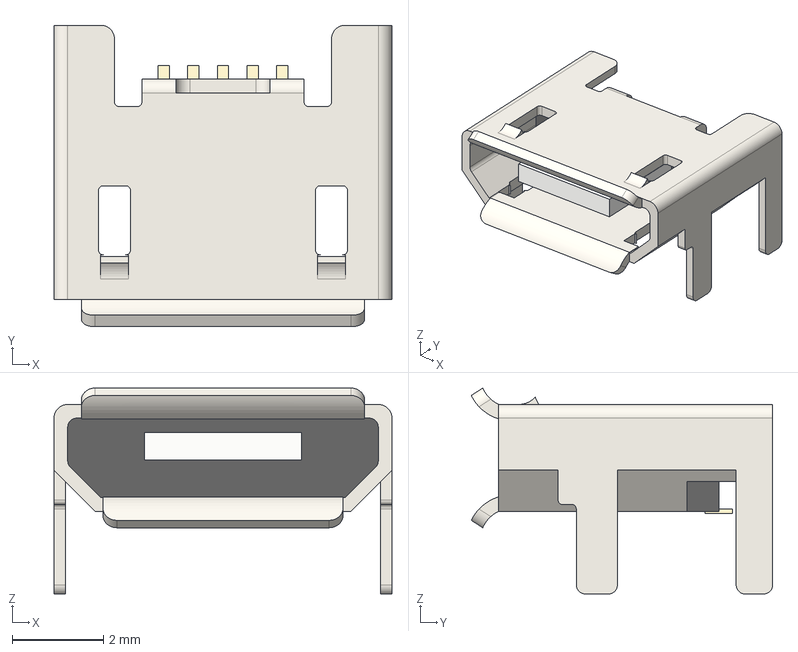
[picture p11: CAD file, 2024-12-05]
elec/Control Board/Control_1v2/PublicInvention_KiCad_Library/Parts/NotGood_XKB Connectivity U254-051N-4BH806.step
7.40 x 6.60 x 4.51 mm

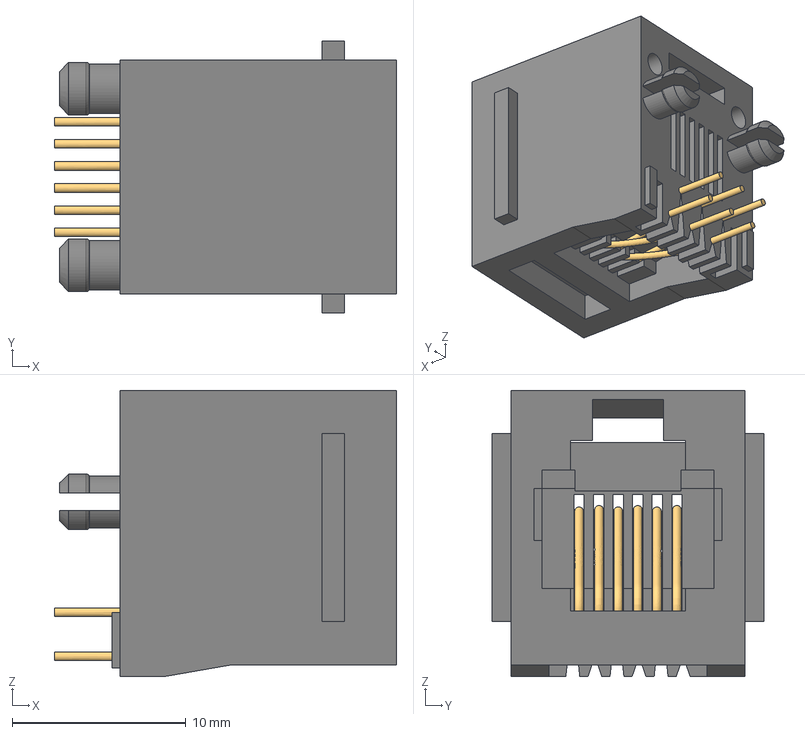
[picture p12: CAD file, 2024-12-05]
elec/Control Board/Control_1v2/PublicInvention_KiCad_Library/Parts/rj11-connectors-6p-1.snapshot.1/rj_6p_615006144121 (rev1).stp
19.7 x 15.7 x 16.5 mm
pin1
pin3
pin5
pin2
pin4
pin6
housing

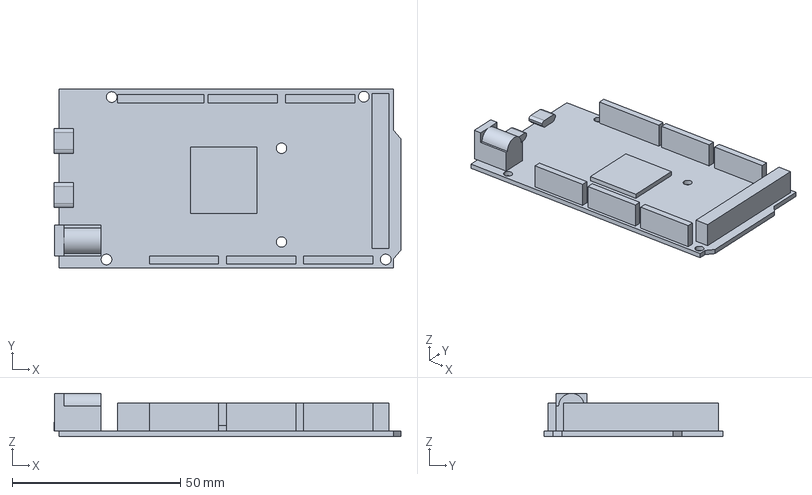
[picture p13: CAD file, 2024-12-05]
elec/Control Board/Control_1v2/resources/Due/Arduino_Due_13571747.stp
103.1 x 53.2 x 12.8 mm

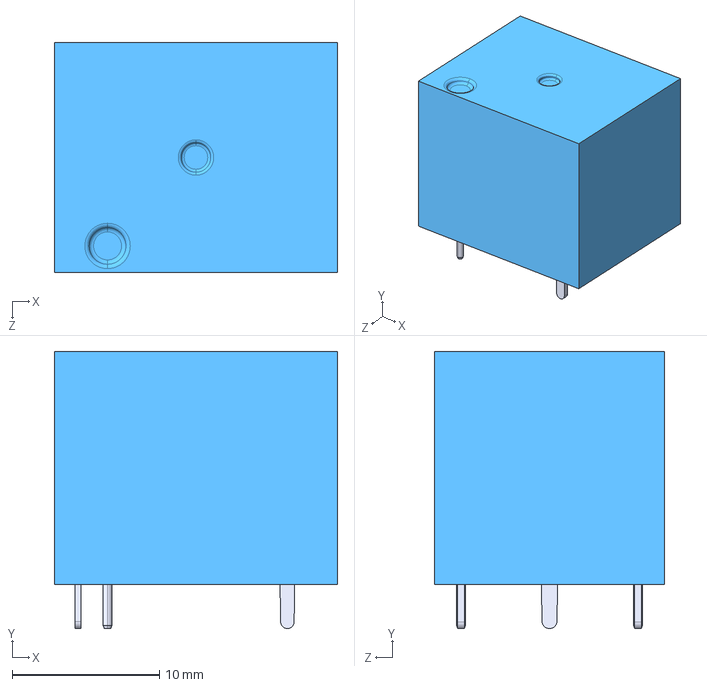
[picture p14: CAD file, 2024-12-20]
elec/Control Board/Control_1v2/resources/SRD-05VDC-SL-C.STEP
19.2 x 18.8 x 15.6 mm

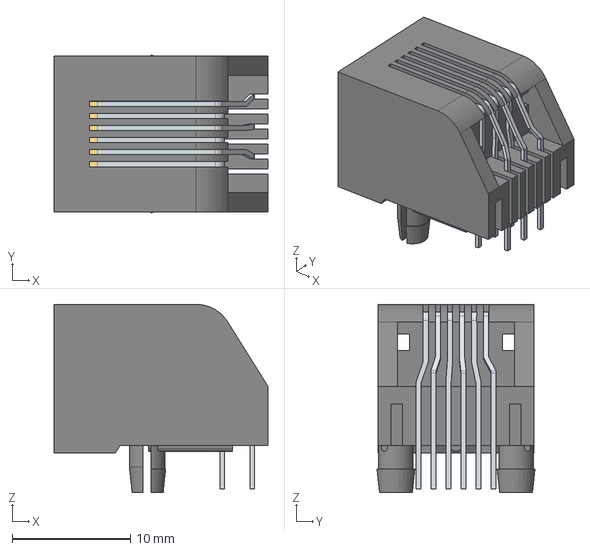
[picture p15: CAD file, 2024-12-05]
elec/Control Board/Control_1v2/PublicInvention_KiCad_Library/Parts/rj11-connectors-6p-1.snapshot.1/rj-6--horiz-tabdown-615006143621 (rev1).stp
18.1 x 13.4 x 15.9 mm

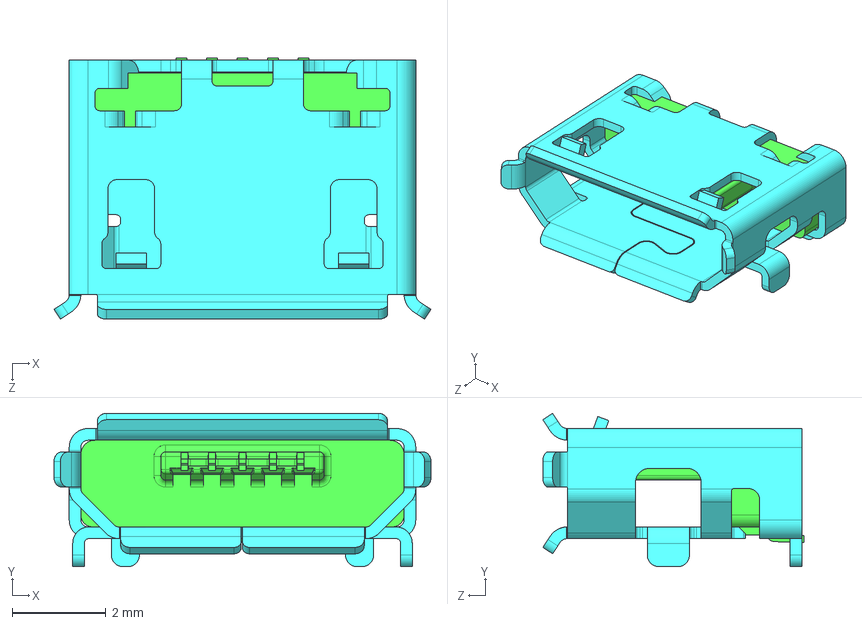
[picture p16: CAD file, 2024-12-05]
elec/Control Board/Control_1v2/PublicInvention_KiCad_Library/Parts/USB User Library-10118194.STEP
8.05 x 3.28 x 5.58 mm

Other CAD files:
elec/Control Board/Control_1v2/PublicInvention_KiCad_Library/Parts/S04B-XASK-1/first/Cube.step
elec/Control Board/Control_1v1/MountMini12864/MountMini12864 - 20231215_1654.FCStd
elec/Control Board/Control_1v1/MountMini12864/MountMini12864-Part_MountMini12864Body_MountMini12864_b.step
elec/Control Board/Control_1v1/MountMini12864/MountMini12864 - Facebook20231209.FCStd
docs/P_and_ID/models/4936K768_Compact Extreme-Pressure Steel Pipe Fitting.STEP
elec/Control Board/Control_1v1/MountMini12864/MountMini12864-Part_MountMini12864Body_MountMini12864.3mf
elec/Control Board/Control_1v1/MountMini12864/MountMini12864-Part_MountMini12864Body_MountMini12864.step
elec/Control Board/Control_1v1/MountMini12864/MountMini12864-Part_MountMini12864Body_MountMini12864.stl
elec/Control Board/Control_1v1/MountMini12864/MountMini12864-Part_MountMini12864Body_MountMini12864_b.3mf
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

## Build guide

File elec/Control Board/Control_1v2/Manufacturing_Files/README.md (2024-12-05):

# Discription of these files

The files used to order Control V1 printed wiring assemblies from JLCPCB on about 20230828

* Control v1 bom and placement 28_8_2023 .zip
* Control v1Gerbers 28_8_2023.zip
* bom (3).xls

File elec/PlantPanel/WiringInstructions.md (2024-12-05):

# Wiring Instructions for the Plant Panel

The plant panel is meant to be close enough to the CFC that it can be directly wired. The direct connections are:
1. The Line Voltage (heater) connections and Grounding
2. The Fan Connector
3. The Thermocouples
4. The High Amperage, Low-voltage stack power

Although simple, some adive may be helpful here.

I choose to use 18" wires for all the wires that I controlled, except the fan wires, which are 24" long (because the must reach the fan, which is further away from the top of the CFC.

## The Line Voltage (heater) connections and Grounding

I found it convenient to use Spade-type connectors here.

Note that the heater has no ground; the ground connection in a 3-prong connector is connected to the CFC chassis with a wire of the same ampacity as the line voltage.



## The Fan Connector

The fan connector wires can be soldered dirctly to the solder cups. This is an error-prone operation,
it is important to get it correct.

Lawrence made the following chart of the connectors:

FanPinChart

This chart must be absolutely respected, because the cable takes these same wires to the OEDCS. Note the plastic connectors have wire numbers (1,2,3,4) embossed on them, but they are VERY hard to read and quite small.



I connect the wires to a terminal block to connect them to fan/blower. However, if making more than a few units, these connections should be soldered.



## The Thermocouples

The thermocouples are directly wired to the connectors. This is quite challenging because the wires in the thermocouples are quite stiff.



## The High-Amperage Connector

I created 18" wires and crimped on the Anderson lugs. These are 6 AWG wires.

We coneect these directly to the two-stranded silver wires for the heaters using ceramic blocks. These ceramics blocks have 
an orifice which is too small to accept the 6AWG wires. We therefore have to carefully trim or bend away many of the 
copper strandes to get them to fit, as shown in the photo below:

As shown here:


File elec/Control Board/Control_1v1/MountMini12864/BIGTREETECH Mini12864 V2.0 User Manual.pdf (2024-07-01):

Shenzhen Big Tree Technology Co., Ltd.

## BIGTREETECH

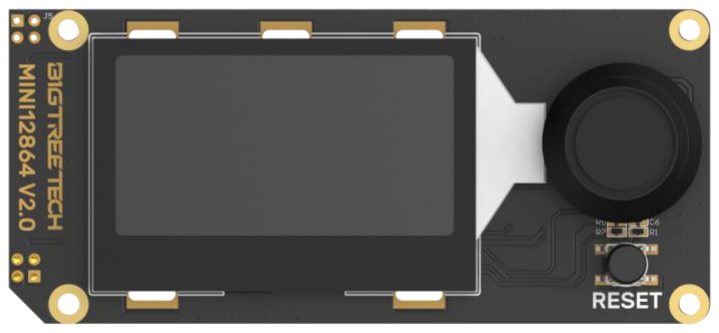
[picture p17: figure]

1 / 8

# BIGTREETECH MINI12864 V2.0

# User Manual

## BIGTREETECH

2 / 8

## CONTENTS

## BIGTREETECH

3 / 8

## Revision History

Version | Revisions | Date
01.00 | Original | 2022/10/11

## BIGTREETECH

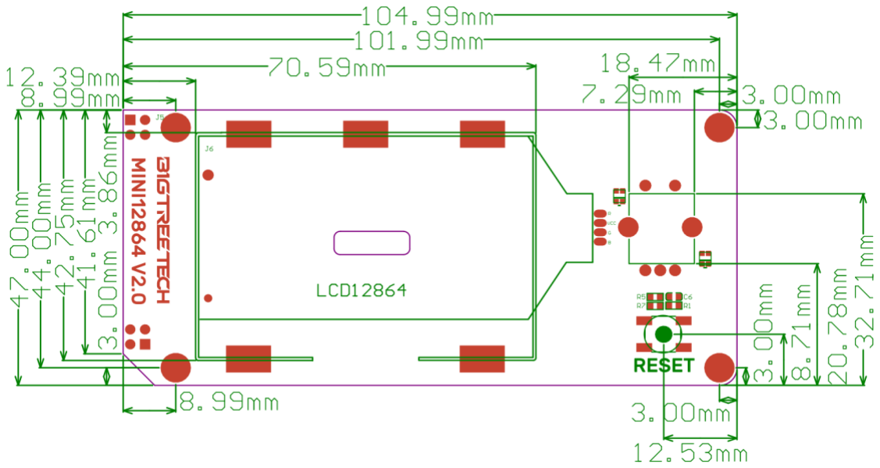
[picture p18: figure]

4 / 8

## Product Profile

BIGTREETECH Mini12864 V2.0 is a medium-sized screen with RGB backlight launched by the 3D printing team of Shenzhen Big Tree Technology Co., Ltd.

### Feature Highlights

1. Communicate with the motherboard via EXP1 and EXP2;
2. RGB backlight, so cool;
3. Designed with the FPC connector to allow customers to choose their preferred connection way.

### Specifications

1. Dimensions: 104.99mm x 47mm
2. Mounting Size: Please refer to BIGTREETECH Mini12864 V2.0top-SIZE.pdf
3. Input: DC 5V
4. SD Card Logic Voltage: 3.3V and 5V (e.g.: motherboards that support MEGA2560 MCU, higher compatibility)
5. Interface: EXP1+EXP2 or FPC (Display)
6. Onboard Buzzer, RGB Light, RGB-LCD Screen

### Dimensions

## BIGTREETECH

## Peripheral Port

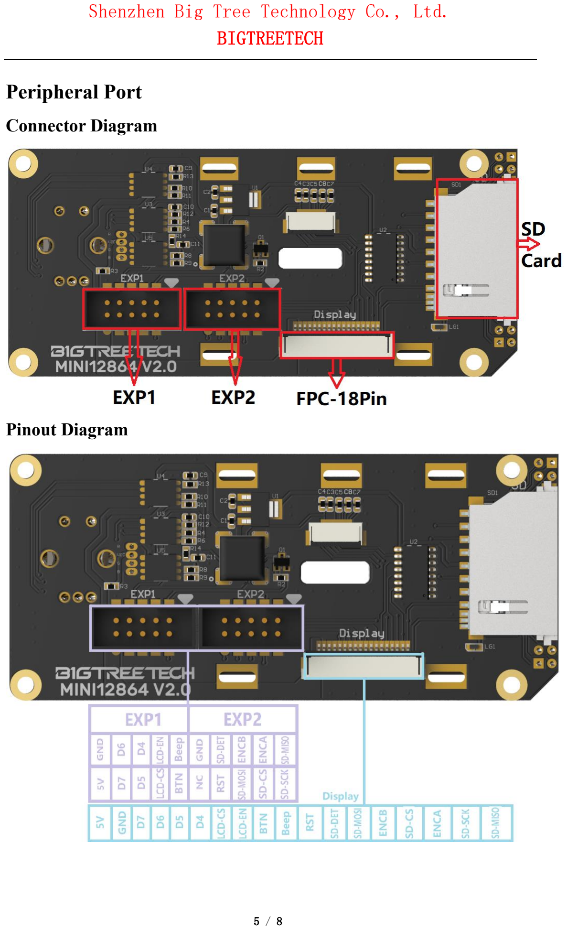
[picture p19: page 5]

5 / 8

### Connector Diagram

### Pinout Diagram

## BIGTREETECH

## Connection Description

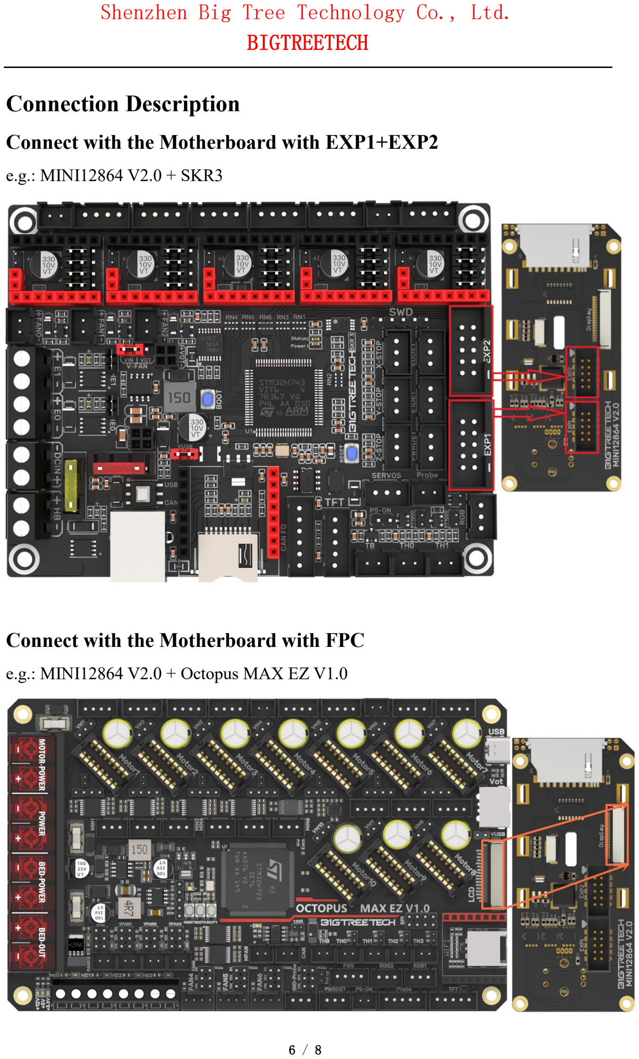
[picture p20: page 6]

6 / 8

### Connect with the Motherboard with EXP1+EXP2

e.g.: MINI12864 V2.0 + SKR3

### Connect with the Motherboard with FPC

e.g.: MINI12864 V2.0 + Octopus MAX EZ V1.0

## BIGTREETECH

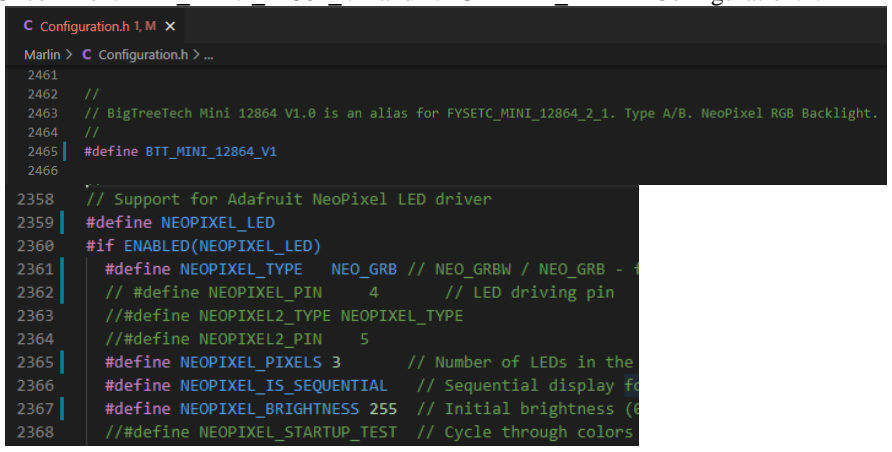
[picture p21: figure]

7 / 8

## Motherboard Firmware Instruction

### Marlin

1. Uncomment BTT_MINI_12864_V1 and NEOPIXEL_LED in Configuration.h.
2. If the screen does not display content, you may need to initialize EEPROM with "M502" and then "M500" after flashing to ensure the new contrast settings are used.

### Klipper

###################################################################### # BigTreeTech mini12864 (with neopixel backlight leds) ######################################################################

[display]
lcd_type: uc1701
cs_pin: EXP1_3
a0_pin: EXP1_4
rst_pin: EXP1_5
contrast: 63
encoder_pins: ^EXP2_5, ^EXP2_3
click_pin: ^!EXP1_2
## Some micro-controller boards may require an spi bus to be specified: #spi_bus: spi

## Alternatively, some micro-controller boards may work with software spi: #spi_software_miso_pin: EXP2_1

#spi_software_mosi_pin: EXP2_6

#spi_software_sclk_pin: EXP2_2

[output_pin beeper]
pin: EXP1_1

## BIGTREETECH

8 / 8

[neopixel btt_mini12864]
pin: EXP1_6
chain_count: 3
color_order: RGB
initial_RED: 0.4
initial_GREEN: 0.4
initial_BLUE: 0.4

### Cautions

Ensure that the power is turned off when wiring. Turn on the power only after checking the correct connection of the cables and the driver to prevent the board and screen from being burnt due to incorrect wiring, causing unnecessary costs.

If you need other resources for this product, please visit https://github.com/bigtreetech/ and find them yourself. If you cannot find the resources you need, you can contact our after-sales support.

If you encounter other problems during use, feel free to contact us, and we are answering them carefully; any good opinions or suggestions on our products are welcome, too and we will consider them carefully. Thank you for choosing BIGTREETECH. Your support means a lot to us!

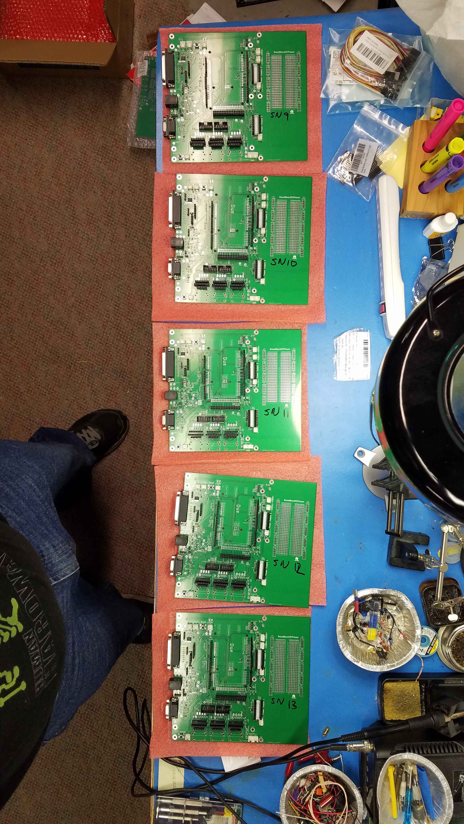
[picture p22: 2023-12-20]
elec/Control Board/Control_1v1/FabricationPhotos/20231026_185839.jpg

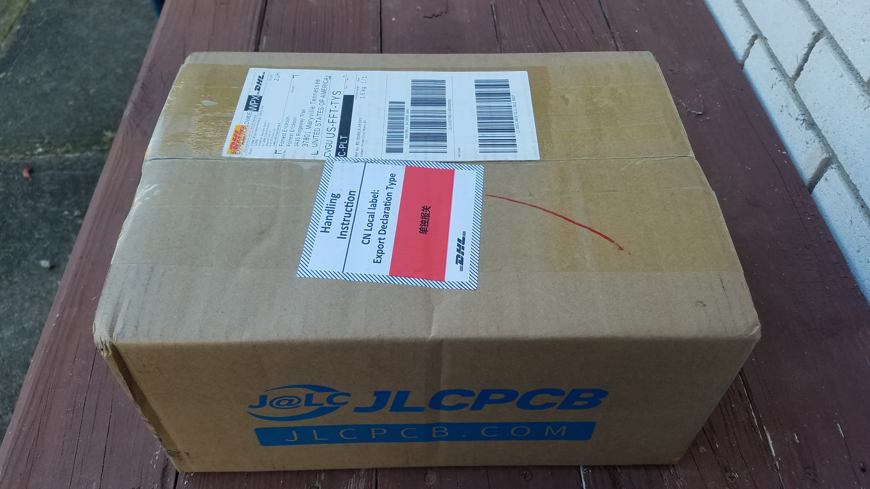
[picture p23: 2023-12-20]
elec/Control Board/Control_1v1/FabricationPhotos/20231026_165317.jpg

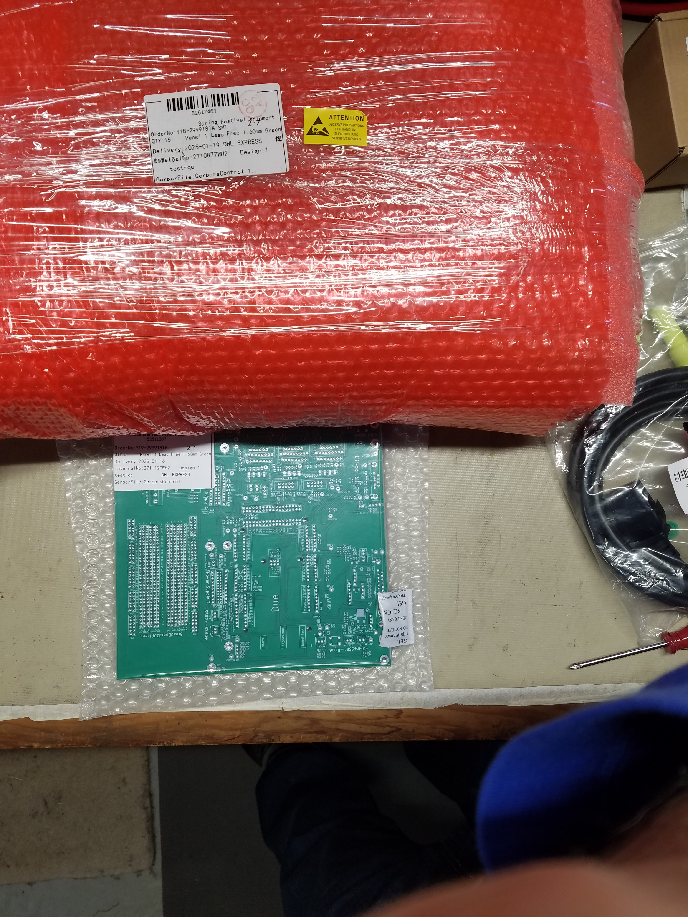
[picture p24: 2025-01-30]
elec/Control Board/Control_1v2/Manufacturing_Files/FabricationPhotos/20250129_141251.jpg

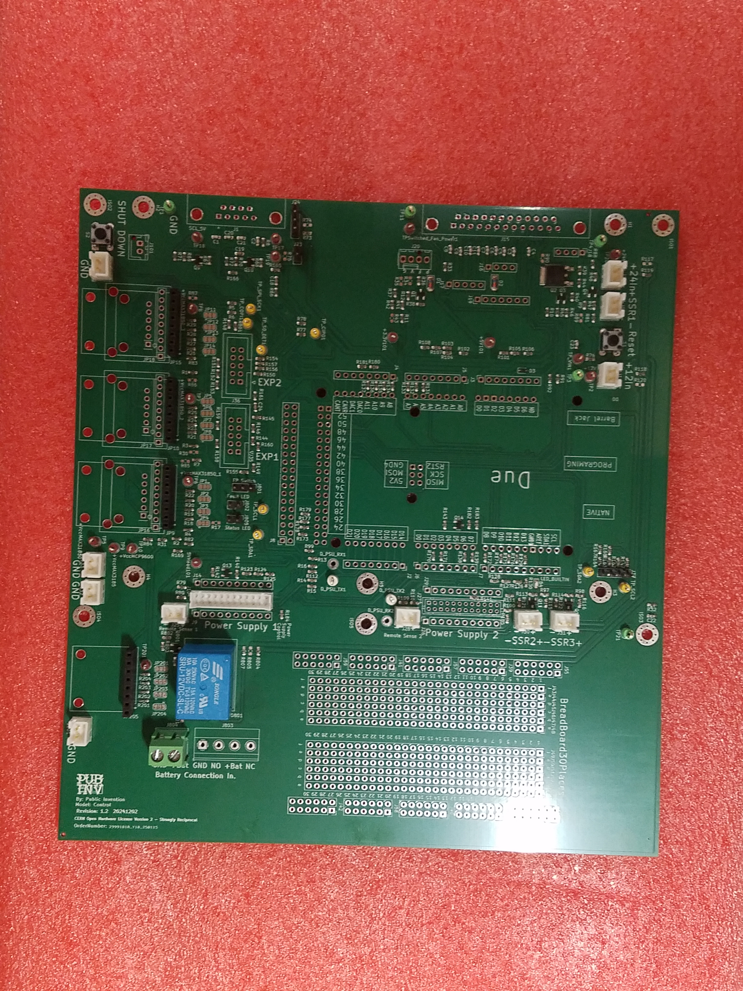
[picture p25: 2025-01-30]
elec/Control Board/Control_1v2/Manufacturing_Files/FabricationPhotos/20250130_080157.jpg

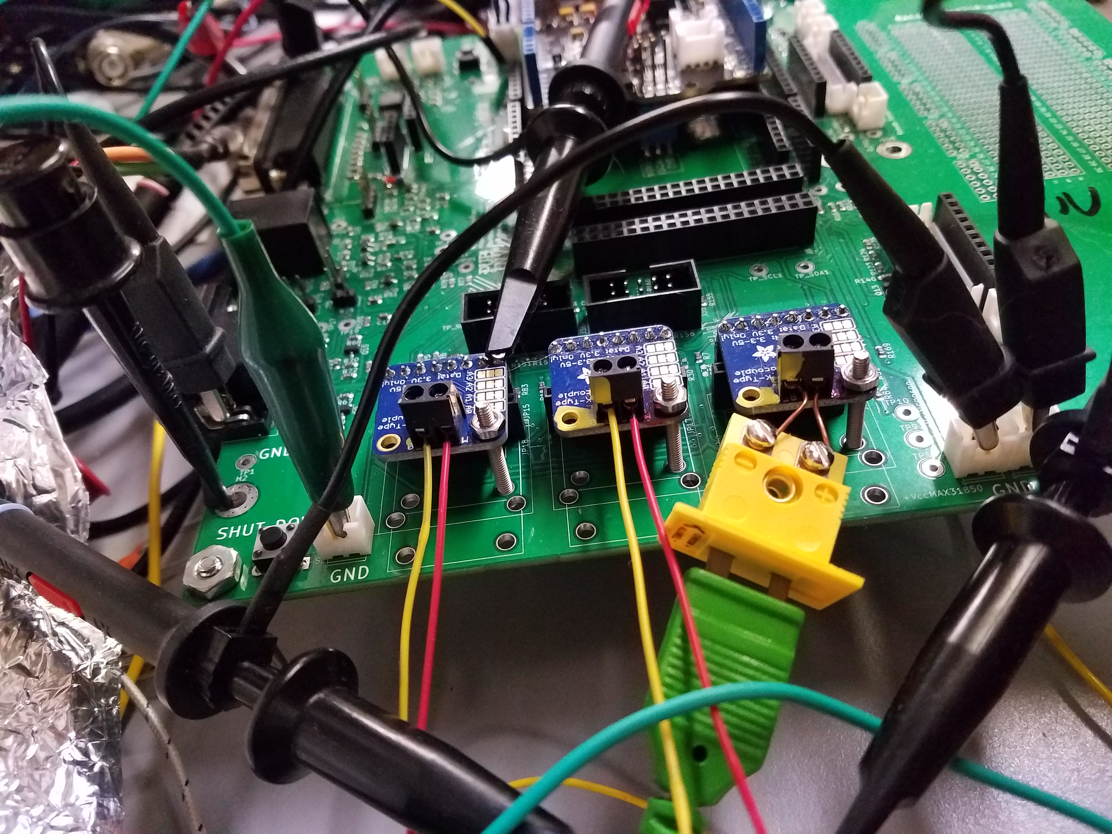
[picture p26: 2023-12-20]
elec/Control Board/Control_1v1/FabricationPhotos/20231117_172314.jpg

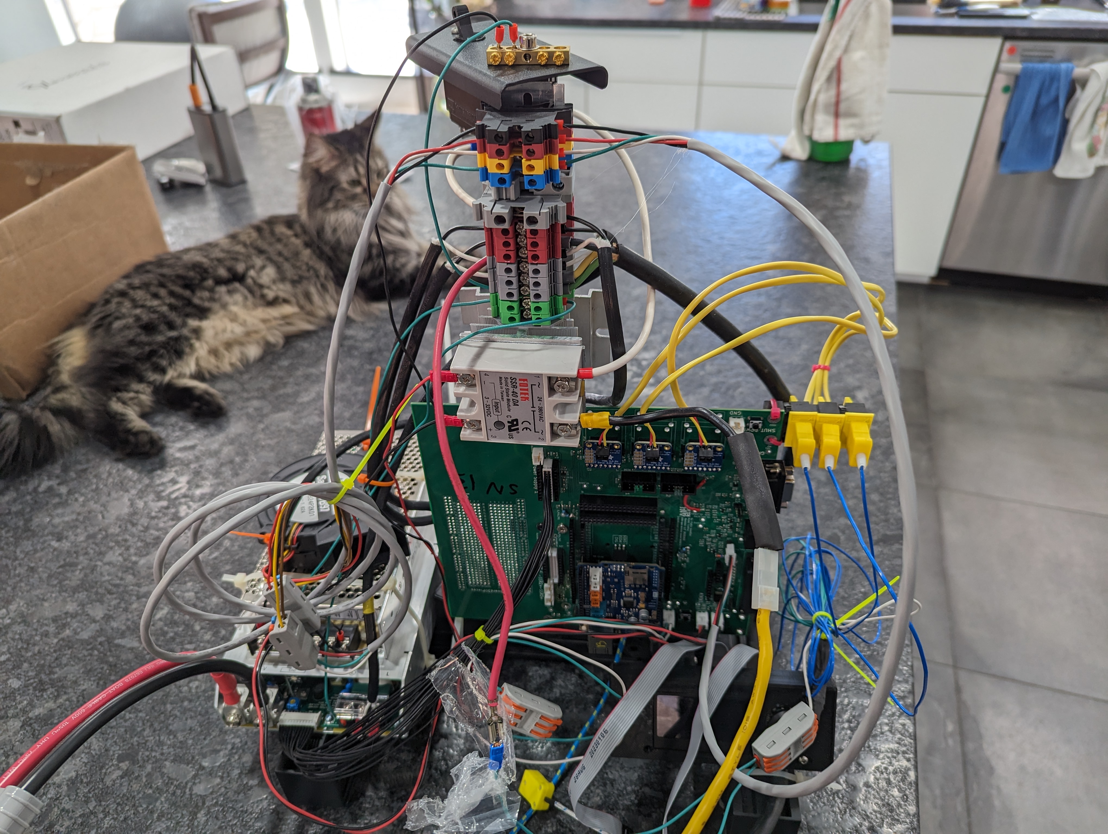
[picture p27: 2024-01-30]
elec/Control Board/Control_1v1/FabricationPhotos/PXL_20240129_171152876.jpg

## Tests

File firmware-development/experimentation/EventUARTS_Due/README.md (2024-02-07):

## Event driven code for all four Due UARTS.
The loop() is empty of code.
The hardware under test was a TF800 series power supply on UART`. (Caution obout 5V and 3.3V system apply.)

Here a message typed into the Serial Monitor is forwared to UART1. The UART1 event handeler forwards the UART1 response back to the Serial Monitor  


This measures the time from the LF:
1. at the Serial Monitor input  UART0
2. at the UART 1 from the power supply after processing the "***IDN?**" command

The power supply interpreting the command and reporting the output "SL Power, TF Series" took 86 mS.  At 4800 BAUD the 19 characters time 10 bits is 39.5mS
So the processing time was about 86-39.5 or 46mS.
Then 9 mS later the "=>" was printed.  

The power supply interpreting the command "**DEVI?**" took roughtly the same time


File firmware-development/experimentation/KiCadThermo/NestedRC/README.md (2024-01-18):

## Ideas for Simulating Nested Structure of the Stack inside a Heat Exchanger using SPICE

Motivated by ideas such as found at: https://lpsa.swarthmore.edu/Systems/Thermal/SysThermalModel.html#:~:text=To%20model%20this%20system%20with,to%20the%20thermal%20system%20above.  

Lee has made a circuit model using a current source as a heat source and resistors and capacitors to represent the heat exchanged, then nesting another resistor and capacitor to represent the stack and added a currrent (sink) as a non linear load (O2 and heat out) for the PLANT as a the load of the ODECS.

### Schematic Viewer
Stale screen shot of schematic but with circuit blocks outlines.  


[Select this link for current schematic ***View on KiCanvas***.](https://kicanvas.org/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)  
_(Unfortunatly the KiCanvase view does not show the dashed outlines around circuit blocks.)_

**Notes**  
* The resistors have units DegreeC/Watt   
* The thermo capicatance should be in J/kg-K and should be Farad, however for the schematic capacitors are in uF and we have to enter as very large numbers of uF.  
* The current source are Watts.  
* The V out is actualy Degrees C.  

### Simulation results


### Limitations / Errors in Approximations

This simulation does not represent air flow. It is as if only thermoconducation through a solid was responsible for all heat flow.

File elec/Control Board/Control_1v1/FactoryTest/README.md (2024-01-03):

# Factory Test Plan, Control V1.1, Printed Wiring Assembly
Journal of tests for assemblies of October 2023.  
PCB assembly by JLCPCB with some finish work in Maryville TN.  
Five Assemblies assigned SN 9-14.  

Notes made in issue #89 during the development of this test plan.

## Resources
12V power supply with current monitor. Color the plug Red. 
Multi meter to measure voltage and resistance.  (Actual Multimeter (EMCO DMR-3800) )  
PC with Arduino IDE to connect to USB programing port of Due  
Firmware: https://github.com/PubInv/NASA-MCOG/tree/develop/elec/Control%20Board/Control_1v1/FactoryTest  
Arduino Sketches: 
1. DueWithThreeSSRs
2. GraphicsTest

## Test Procedure
### Before Test, Finish Assembly
Install on these units the feed through headers for the Due connections which make this assembly become a shield for a Due.
Color the connector J11, +12VIn red with a sharpie.

### Unpowered Test of PWA.

Summary and data capture table

Tester Name ____ F. Lee Erickson ________________
Date of Test _____ 20231026 _____________________

| Test ID 	| Test Name 	| Setup 	| Test Location 	| Requirements 	| Results SN 9 	| Results SN 10 	| Results SN 11 	| Results SN 12 	| Results SN 13 	|
|---:	|---	|---	|---	|---	|---	|---	|---	|---	|---	|
| 1 	| Inspection 	| Inspect correct orientation on polarized parts 	| 	| 	| D1 and D2 Probably backwards. | 	| 	| 	| 	|
| 2 	| +24In In No Short 	| Set ohm meter 20M. Com to GND 	| TP20 (J12 Pin 1) 	|  > 10K 	|  34.6K  	|  34.6K 	| 34.5K  	|  34.6K 	| 	|
| 3 	| +12In In No Short 	| Set ohm meter 20M. Com to GND 	| TP 2 (J11 Pin 1) | > 10K 	 | 39.8K |  39.9K 	| 39.8K | 39.8k 	| 	|
| 4 	| 5VHEAD net 	| Set ohm meter 20M. Com to GND 	| J8 Pin 1 | Open or > 1 Meg 	| Open | Open 	| Open 	| Open 	| 	|
| 5 	| +5V net 	| Set ohm meter 20M. Com to GND 	| J3 Pin 4 | Open or > 1 Meg 	| 12.1 Meg | Open 	| Open 	| 2.4K (Issue #126 https://github.com/PubInv/NASA-MCOG/issues/126) | 	|
| 6 	| +3.3V net 	| Set ohm meter 20M. Com to GND 	| J3 Pin 5 | Open or > 1 Meg 	| 11.7 Meg | Open 	| Open 	| Open 	| 	|

### Program Due with Firmware
Before connecting to the Controller V1.1 Assembly, program the Due with Load the factory test firmware "MAX31850_Tester.ino" 

## Finish Assembly

#### Build Up MAX31850 Thermocouple Amplifier Sub Assemblies
Note that the side of the board to be up has the pads for configuring the addresses of the assemblies. 
Solder the header and screw terminal to the MAX31850 on the correct side.

1. Install the MAC13850 thermocouple amplifier assemblies to the Control V1.1 at JP9, JP10 and JP15.
Add a ?2.5mm? x 10 mm screw with nut as mechanice support and retention.
Observing polarity, connect thermocouples to the MAX31850 amplifire assemblies.
Cut the four on board shunt on each MAX31850 PCB (See image below for where to cut on one).  Measure with multimeter that the shunt to GND is open.


3. Add screws for legs such as 8-32 x 2") with nuts.  These legs are necessary because the long stacking connectors to be installed must not be bent which would happen if the legs were not installed.
4. Solder in the stakcing Due connectors, seven locations.  The long tails must go in the top and through to the bottom
5. Connect the Due to the Controller assembly.  The Due is under the Controller V1.1 assembly as a "shield".
6. Connect the Ethernet W5200 (or similar) sheild on the top of the Controller V1.1

### Apply power. 
Note the +12VIn, the +24VIn and the Stack programable power supply are connected to a switchable outlet switch.  
With the power outlet off, 
Connect the +12VIn power at J11, the RED connector.  
Connect the  +24VIn power at J12.  
Connect SSR simulator LEDS at  SSR1, SSR2, SSR3.  
Connect the Stack power supply at J10 ( or J27) at this time.

Apply power by switching on the AC power strip.
**Test ID7:** Note current in table on the +12VIn supply current monitor for excessive, above 100 mA.  THIS NUMBER WILL NEED TO BE CHECKED WITH DUE's THAT HAVE NEVER BEEN PROGRAMED.
Check that the BUILDIN_LED ner the LAN Shield and SSR2 and SSR3 connectors is blinking rapidly as an idication that the firmware is running.
Open the Arduino Serial Plotter (<Ctrl> <Shift> <L>) and touch some thermocouples.

### Temperature Measurements.
**Test ID8:** Typical Serial Plotter results. Touching some of the thermocouples to ensure they respond.
Note resutls in table


**Results continued...**
| Test ID 	| Test Name  | Setup | Test Location | Requirements  | Results SN 9 | Results SN 10 | Results SN 11 | Results SN 12 | Results SN 13 	|
|---:	|--- | --- |--- | ---	|---	|---	|--- |--- |--- |
| 7 | Current, Temperature Only  | In line DC current meter | Due input |  85 mA | | 270mA |  200mA | |
| 8 | Check thermocouples  | Connect three | Serial Plolter |  Three traces | OK | OK | OK | | |
| 9 | future use  |  | | | | | | | |

Load and run factory test firmware DueWithThreeSSRs.ino
Open the Arduino Serial Monitor. Observe the data.
**Test ID10 ** Observe SSR1, SSR2, SSR3 LED Blinking.
**Test ID11 ** Observe Mini12864 Display back lit and displaying splash message and four measurements.
**Test ID12 ** Encoder Rotation Knob is back lit. Rotate the know and observe the serial port reporting changes.
**Test ID13 ** Encoder knob switch. Press the knob and observer serial port message about shutdown.
**Test ID14 ** PCB mount SHUT DOWN button. Press the button and observer serial port message about shutdown.

**Results continued...**
| Test ID 	 | Test Name  | Setup | Test Location | Requirements  | Results SN 9 | Results SN 10 | Results SN 11 | Results SN 12 | Results SN 13 	|
|---:	|--- | --- |--- | ---	|---	|---	|--- |--- |--- |
| 10 | SSR1, SSR2, SSR3 LED Blink  |  | | | OK | OK | OK | | |
| 11 | Mini12864 Display |  | | | | OK | OK | | |
| 12 |Encoder Rotation Knob |  | | | | OK | OK | | |
| 13 |Encoder knob switch |  | | | | OK | OK | | |
| 14 | PCB button SHUT DOWN |  | | | | OK | OK | | |
| 15 | LAN CONNECTION |  | | | | OK | OK | | |
| 16 | Stack voltage at reset 1V |  | | | | OK | OK | | |
| 17 | Stack power to load |  | | | | OK | OK | | |
| 18 | Cumulocity reporting |  | | | | OK | OK | | |
| 19 | Reset to safe |  | | | | OK | OK | | |
| 20 | PxxxxxxxxxxxxxxxxxN |  | | | | | | | |

### Stack Power Supply Control 
With AC power on.

#### PS1_EN Jumper

| Nets to Jumper 	| Description  |
|---	|--- |
|  | Untill the OEDCS firmware is modified to support the PS1_EN and PS2_EN control lines place a jumper wire from J14 Pin 5 to J9 pin 9 |

Load the OEDCS firmware into the unit under test.  
Open the serial monitor. 
Observe the traffice and note that a Power supply  is reported.  
  
Observe the traffice and note that an IP address is reported.  
  
On serial port monitor confirm device connects to LAN **ID16**.  

#### Set Stack power supply and +24VIn.  
Connect a 1.5K 1/2 wat resistor load on the Stack Power Supply ouput.
With multi meeter observe the voltage on the stack power supply load.  
After observe and record voltage **ID16** after reset it should be 1V the power on voltage.
Send OEDCS serial port commands to set Stack power to load manual.
* s:1
* a:0.1
* w:2.5
Observe and record **ID17** Stack power to load should now be about 12V

### Observe data on Cumulocity  
https://mcogs.us.cumulocity.com/apps/app-builder/index.html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

Observe and report **ID19**. 

### Reset to Safe
Press and hold the reset button.
Observe that the Stack power supply voltage goes to zero.  (IT DID NOT as of 20231218 with TF800A12K)
Observe that the blower stops.
Observe that the SSR LEDs go off.
Recorde results in test **ID19**  

### Capture MAC, Send for Server Setup
After reset and connection to a LAN the Serial Monitor report displays the device MAC address. Catpure to the table below.
| Unit Serial Number 	| MAC ADDRESS  |
|---	|--- |
| 1	| FE:ED:1B:70:08:77 |
| 2	| FE:ED:10:69:73:70 |
| 3	| NA |
| 4	| NA |
| 5	| NA |
| 9	| FE:ED:1D:70:05:6D |
| 10	| FE:ED:12:71:06:65 |
| 11	| FE:ED:16:6B:72:67 |
| 12	| FE:ED:17:73:0E:69 |
| 13	|  |

At end of shift send all new MAC Addresses for addition ot the server.

Other Stage II Controler: FE:ED:14:71:02:77

### End of Test
Power off the unit under test.
Remove all connections including the jumper wire at J14 and J25.
Very carfuly so as to not bend pins, remove the LAN Sheild.
Very carfuly so as to not bend pins, remove the Due controller. A modified pop cycle stick helps.

## Rejoice another great OEDCS has been born!

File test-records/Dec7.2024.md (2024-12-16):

# Dec. 7th High temperature test

After improving the RPM envelope safety feature, I performed a high-temperature test on Dec. 6th.
Upon awaking on Dec. 7th, the system was operating but appeared to be stuck, with post-getter temperature at 474 and unable to climb.
The SetPoint seemed to keep rising, which appears to be a bug.

```
Timestamp: 74545653
Machine State: Warmup
Target     C: 750.00
Setpoint   C: 645.63
Target Ramp C: 0.50
Max Stack   A: 30.00
Max Stack   W: 250.00
Fan PWM   0-1: 0.65
Fan Target % : 80.00
Post Heater C: 535.50
Post Getter C: 473.75
Post Stack  C: 505.25
Heater DC 0-1: 1.00000
Stack amps  A: 0.07
Stack watts W: 0.11
Stack volts V: 1.64
Stack ohms  O: 23.43
Fan RPM      : 8479.00
analogRead(SENSE_12V)= 845
13.63
12V bus voltage = 13.63
```

The system is stuck because the Post Stack temperature - Post Getter Temperature is greater than 30 degrees, the edege difference limit.
Note that the Post Getter temperature is lower than the Post Stack temperature, which I believe is because of air leaks around the stack in the Austin CFC.

I am also truouble by the fact that the stack volts are only 1.89. We should at this temperature be able to put more head directoy into the stack.

It is possible that as the general system warms up, it may be able to get "unstuck", but since the setpoint is 100 degrees higher than the stack temperature,
I believe it has been stuck for 200 minutes = 3 hours and 20 minutes.

I decide to increase the stack edge limit to 40C with the absolute limit set to 60C.

At 7:30 I realized I had the Post Stack and the Post Getter thermocouples mistaken for each other. I swapped them.

at 7:31, the system Stad "STARTING DUMPING LOG RECORDS: 10" but abarted in the middle of that -- this is unexplained buggy behavior.

After rearranging the thermocouples, I let the system run. I am concerned that the stack is not receiving 12Volts, even though at this point in the algorithm I think it should.

at 10:00 pm I enterred cooldown mode. I was unable to get above these temperatures:

```
Timestamp: 50970480
Machine State: Cooldown
Target     C: 50.00
Setpoint   C: 582.17
Target Ramp C: 0.50
Max Stack   A: 30.00
Max Stack   W: 250.00
Fan PWM   0-1: 0.63
Fan Target % : 40.00
Post Heater C: 576.50
Post Getter C: 549.50
Post Stack  C: 510.75
Heater DC 0-1: 1.00000
Stack amps  A: 1.24
Stack watts W: 6.08
Stack volts V: 4.90
Stack ohms  O: 3.95
Fan RPM      : 8391.00
analogRead(SENSE_12V)= 845
```

Monday morning, I tried to excute this command:

```
pio device monitor --filter=direct --baud=115200 2>&1 | tee -a oedcs.logfile.txt
```

After unplugging and replugging the cable and performing "make" it connected.  They ssytem was down to 50C:

```
Timestamp: 884342
Machine State: Off
Target     C: 30.00
Setpoint   C: 30.00
Target Ramp C: 0.50
Max Stack   A: 0.00
Max Stack   W: 0.00
Fan PWM   0-1: 0.00
Fan Target % : 0.00
Post Heater C: 51.25
Post Getter C: 50.50
Post Stack  C: 44.25
Heater DC 0-1: 0.00000
Stack amps  A: 0.00
Stack watts W: 0.00
Stack volts V: 0.00
Stack ohms  O:  N/A
Fan RPM      : 0.00
analogRead(SENSE_12V)= 846
13.65
12V bus voltage = 13.65
```

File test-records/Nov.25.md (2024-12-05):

# Test of Nov. 24th-Nov. 25th

Hardware Context: OEDCS V1.1 SN9 control board, Austin CFC, plant interface fully wired.

On Nov. 24th and Nov. 25th, we attempted to run a full test to temperature and back down. 

In the middle of the night, at about 500C, 

In the morning, during cooldown, the system erroenously turned itself off due to a TEMPERATURE_OUT_OF_BOUNDS
error. The threshold for this was set to only 20C. 

I believe this limit may be too low---this is an example of something that is likely to be 
quite different for two different CFC designs. I intend to open it.

After waking at 7:00 in the morning and finding it off and the temperature about 150C, (further 
documentation will be provided later), I turned it on and put it into CoolDown mode to 30C.
However, this ALSO turned itself off prematurely due to TEMPERATURE_OUT_OF_BOUNDS.

Upon reflection, this made me believe in a significant improvement. I now believe many
of our errors should enter a controlled CoolDown. This may require us to create a new state,
"CoolDownToOff".  I believe most of these errors, (with the exception of those associated with
a failure of mains power), should take the system to "OFF" which shouold require a human intervention
to restart---this is where our previous creation of the state for just that purpose will pay off.

The failure in the middle of the night was caused by the FanUnresponsive error:

```{verbatim}
Timestamp: 57690153
Machine State: Warmup
Target     C: 750.00
Setpoint   C: 503.18
Target Ramp C: 0.50
Max Stack   A: 30.00
Max Stack   W: 250.00
Fan PWM   0-1: 0.73
Fan Target % : 80.00
Post Heater C: 502.25
Post Getter C: 440.75
Post Stack  C: 471.50
Heater DC 0-1: 1.00000
Stack amps  A: 0.07
Stack watts W: 0.16
Stack volts V: 2.25
Stack ohms  O: 32.14
Fan RPM      : 9031.00
analogRead(SENSE_12V)= 843
13.60
12V bus voltage = 13.60
=======================Fan Inputs : 0.73
9104.00
Fan Fault FAN_UNRESPONSIVE Present: 0
fan_pwm_ratio: 0.73
rpms: 9104.00
rpm_actual: 6060.67
rpm_difference: -3043.33
rpm_tested: 3764.87
Fan Fault Present
BEFORE RUN GENERIC!
Enter s:0 to Turn Off, s:1 to Enter Troubleshooting Mode (NOT SUPPORTED FOR PRODUCTION),
Enter s:3 to Turn Enter Automatic Control (at 750C) or s:2 (set temp with h).
Enter a:XX.X to set (a)mperage limit, (w)attage limit, (h)eater set p.
WILL AUTOMATICALLY SHUTDOWN IF NOT RESTORED IN 179.77 SECONDS DUE TO : Fan TACH unresponsive
calling update Fan Speed!
73.31
XXXX HI_DELTA: 1
XXXX Mode: 1
XXXX Fan Action: Increase
```

Here is the failure at the cool temperature, the post heater more than 20 degrees less than the post getter of 50.5 degrees:

```{verbatim}
Updating Stack Voltage (BBB): 12.00
2320543
Done (BBB): 
2320754
Updating Stack Amperage (CCC):
0.10
AFTER RUN GENERIC!
Free Memory: 28567

Timestamp: 2330004
Machine State: Cooldown
Target     C: 25.00
Setpoint   C: 38.46
Target Ramp C: 0.50
Max Stack   A: 30.00
Max Stack   W: 250.00
Fan PWM   0-1: 0.40
Fan Target % : 40.00
Post Heater C: 43.50
Post Getter C: 50.50
Post Stack  C: 44.00
Heater DC 0-1: 0.00000
Stack amps  A: 0.00
Stack watts W: 0.00
Stack volts V: 11.96
Stack ohms  O: inf
Fan RPM      : 5929.00
analogRead(SENSE_12V)= 845
13.63
12V bus voltage = 13.63
=======================Fan Inputs : 0.40
6031.00
Fan Fault FAN_UNRESPONSIVE Present: 0
fan_pwm_ratio: 0.40
rpms: 6031.00
rpm_actual: 4263.21
rpm_difference: -1767.79
rpm_tested: 3106.08
TESTING ENVELOPE
TEMP BOUND EXCEEDED
5.04
Heater Fault Present
BEFORE RUN GENERIC!
Enter s:0 to Turn Off, s:1 to Enter Troubleshooting Mode (NOT SUPPORTED FOR PRODUCTION),
Enter s:3 to Turn Enter Automatic Control (at 750C) or s:2 (set temp with h).
Enter a:XX.X to set (a)mperage limit, (w)attage limit, (h)eater set p.
WILL AUTOMATICALLY SHUTDOWN IF NOT RESTORED IN 179.77 SECONDS DUE TO : pid pegged, temp out of bounds
Cooldown Mode!
calling update Fan Speed!
39.90
```

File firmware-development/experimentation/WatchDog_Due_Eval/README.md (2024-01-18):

# Watchdog and Save Some Variables Through Reset
This is a Proof or Concept 
Combined watchdog funcation and Flash memory storage of some variabls representing states.

Screenshot showing the first boot after programing and then some resets (watchdog time out)
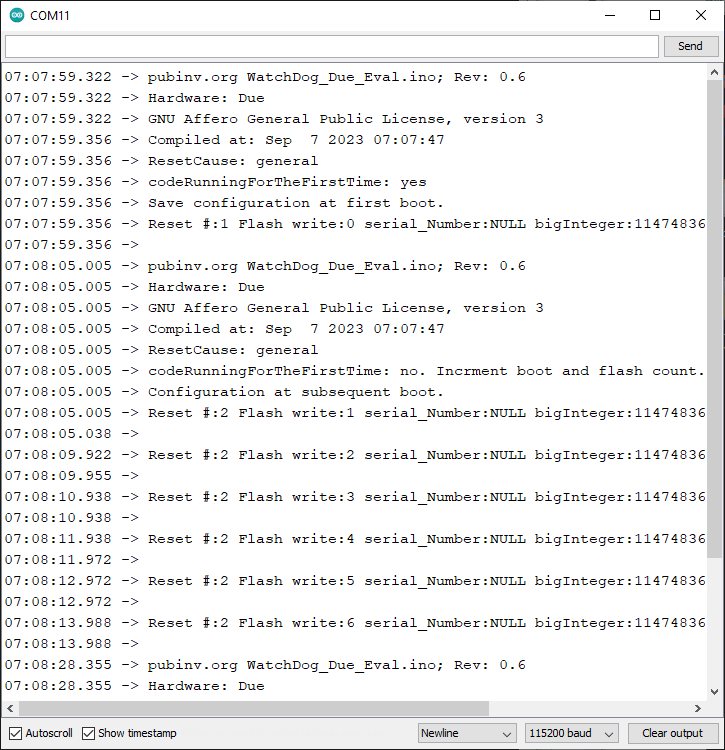
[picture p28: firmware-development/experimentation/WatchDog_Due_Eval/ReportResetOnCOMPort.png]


### TODO
* Needs to count power on reset and watchdog resets independantly
* Make function to report Reset #
* Make function to report Watchdog #
* Make some functions to update states.

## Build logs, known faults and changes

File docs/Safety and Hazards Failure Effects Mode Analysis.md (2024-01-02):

##### In evaluation of proper control of an ODECOS and CFC, the following hazards need to be considered
- Uncontrolled oxygen production
  -- leaking pipes or cracked stacks could cause excessive O2 build up in enclosed spaces
  -- could cause excessive oxygen levels in enclosed spaces
- Thermal runaway
  -- damage to property and equipment
  -- possible ignition source for accelerant gasses such as O2
- Electrical shock hazard
  -- person and equipment hazard
- Oxygen depleted waste exaust gas
--  OSHA dictates that the minimum "safe level" of oxygen in a confined space is 19.5%, while the maximum "safe level" of oxygen in a confined space is 23.5%. 
  With low oxygen levels being the biggest cause of death in confined spaces, accurate oxygen level measurements are essential.
- Excessive ambient temperatures
  -- can cause over temperatures on the heat exchanger
  -- can cause an over temeprature on a hot water exchanger
  -- can cause fire hazards for other devices and materials in the ajoined enclosed space.

##### Resolutions
-  Uncontrolled oxygen production 
  -- a well functioning controller that monitors pressure and meters O2 production satisfies this condition during normal operation
  -- Disabling the stack power supply and the stack heater will eliminate the systems ability to make oxygen 
  -- In an ideal world, a sepearate system would monitor over pressure events on the output O2 stream and could disable the systems ability to make O2 through an electrical signal
  -- a controller function watchdog/fault detection circuit would also satisfy this condition
- Thermal Runaway
  -- A well functoning controller that is monitoring temperature satisfies this condition during normal operation
  -- A thermal fuse on the stacks or on critical components tied to the Estop circuit would fulfill this requriement
  -- a controller function watchdog/fault detection circuit would also satisfy this condition
- Electrical shock hazard
  -- Metallic enclosure and all metal have a reliable connection to ground 
      -- these usually mean a gas tight and dedicated pathway to ground for all metal components
  -- A Ground fault and/or arc fault external protection in addtion to reliably grounding metallic components satisifes this condition
- Oxygen depleted waste exaust gas
  -- External Oxygen Deficiency Monitor for O2 Depletion Safety 0-25%   
  -- a normally closed relay could trigger an e-stop  and satisfy this condition
- Excessive ambient temperatures    
  -- An ambient temperature sensor on the inlet and on the surface of the pcb, in conjunction to a relay tied to an estop should satisfy this condition
  -- a thermal fuse on the inlet temperature should also satisfy this condition
  -- a controller that monitors inlet and ambient temperature should satisfy this condition

##### Controller safety features
- The controller is designed such that on loss of control of the DUE or loss of power, the controller produces a condition that is intrinsically safe and disables production of oxygen

##### References: 

https://www.eaton.com/ie/en-gb/markets/machine-building/service-and-support-machine-building-moem-service-eaton/blogs/emergency-stop-circuit---blogs---eaton.html

https://en.wikipedia.org/wiki/Watchdog_timer

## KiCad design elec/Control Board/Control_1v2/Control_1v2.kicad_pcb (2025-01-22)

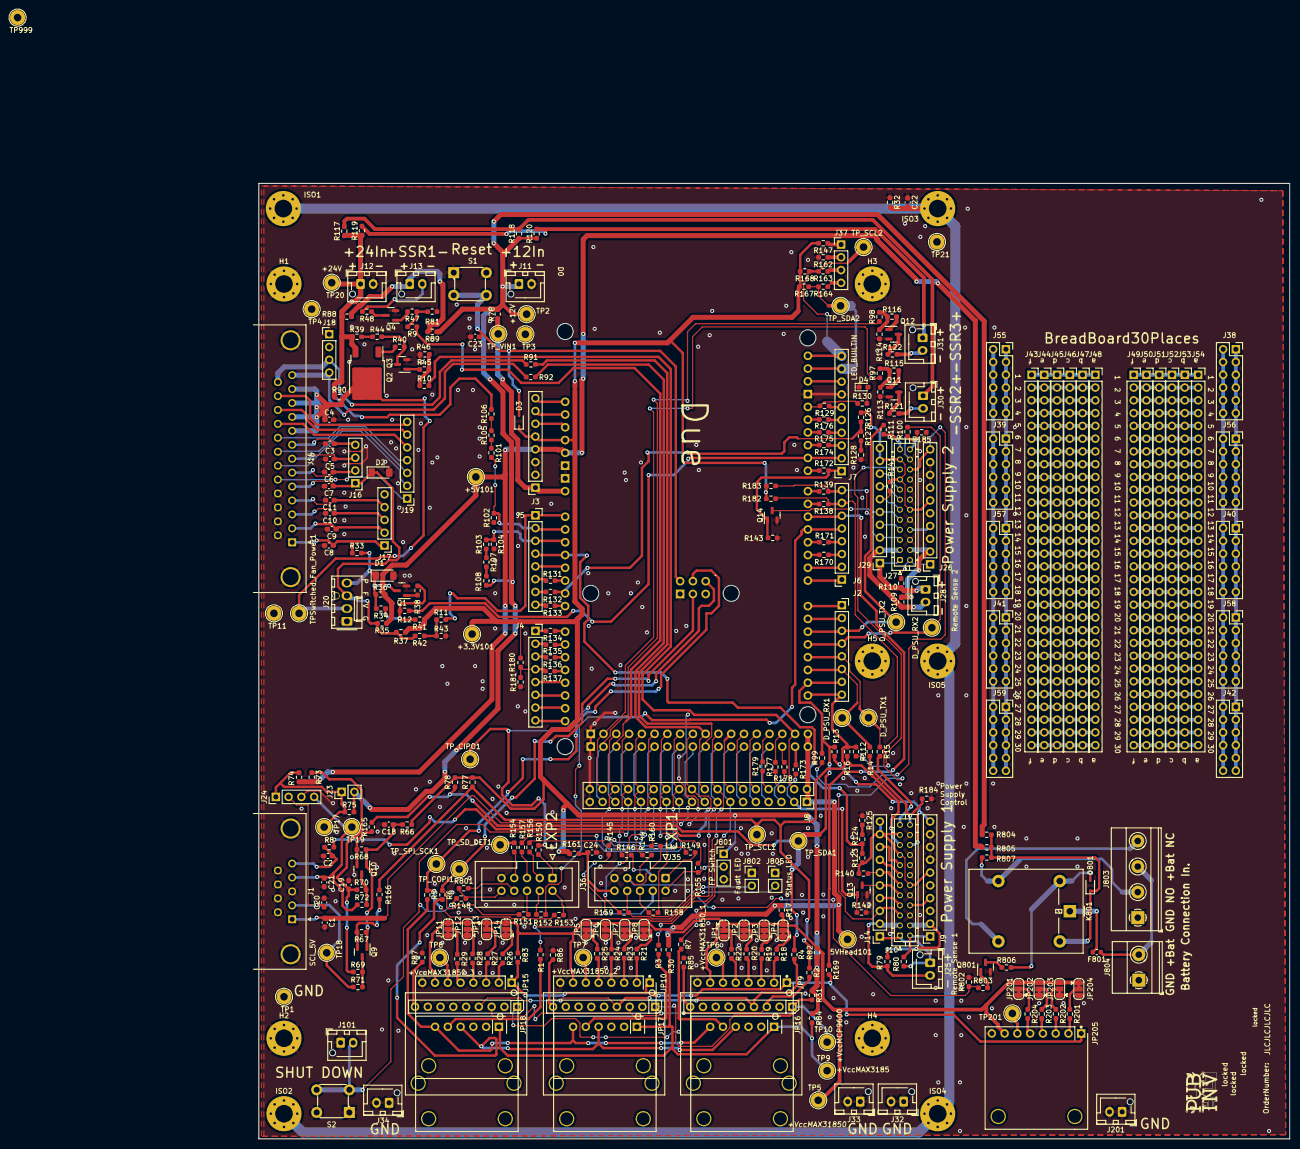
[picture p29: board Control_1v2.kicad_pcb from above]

Board: 2 copper layers, 205.0 x 190.0 mm, 349 parts (0 on the bottom side), 342 nets.

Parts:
5VHead101: 5VHead; TestPoint_Loop_D2.54mm_Drill1.5mm_Beaded
+3.3V101: +3.3V; TestPoint_Loop_D2.54mm_Drill1.5mm_Beaded
+5V101: +5V; TestPoint_Loop_D2.54mm_Drill1.5mm_Beaded
A1: Arduino Due with Headers; Arduino_Due_Shield_Annotated
C1, C2, C3, C4, C5, C6, C7, C8, C9, C10, C11, C20, C21, C23: 39pF; C_0603_1608Metric_Pad1.08x0.95mm_HandSolder
C18, C19, C24: 1uF; C_0603_1608Metric_Pad1.08x0.95mm_HandSolder
C22: 10nF; C_0603_1608Metric_Pad1.08x0.95mm_HandSolder
D1, D2: 5.1V; D_MiniMELF
D3, D801: 1N5819WS; D_SOD-323
D4: RED 0603; LED_0603_1608Metric_Pad1.05x0.95mm_HandSolder
D_PSU_RX1: D_PSU_RX; TestPoint_Loop_D2.54mm_Drill1.5mm_Beaded
D_PSU_RX2: D_PSU_RX2; TestPoint_Loop_D2.54mm_Drill1.5mm_Beaded
D_PSU_TX1: D_PSU_TX; TestPoint_Loop_D2.54mm_Drill1.5mm_Beaded
D_PSU_TX2: D_PSU_TX2; TestPoint_Loop_D2.54mm_Drill1.5mm_Beaded
F801: Polyfuse_0603_1A; Fuse_0603_1608Metric
H1, H2, H3, H4, H5: MountingHole_Pad_3.5mm; MountingHole_3.5mm_Pad_Via
ISO1, ISO2, ISO3, ISO4, ISO5: MountingHole_Pad_3.5mm; MountingHole_3.5mm_Pad_Via
J1: DB9_Female_MountingHoles; DSUB-9_Female_Horizontal_P2.77x2.84mm_EdgePinOffset4.94mm_H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
J2, J3, J4, J5, J6: Conn_01x08; PinSocket_1x08_P2.54mm_Vertical
J7, J9, J14, J26, J29: Conn_01x10; PinSocket_1x10_P2.54mm_Vertical
J8: Conn_02x18_Odd_Even; PinSocket_2x18_P2.54mm_Vertical
J10, J27: Conn_02x12_Odd_Even; JST_PHD_B24B-PHDSS_2x12_P2.00mm_Vertical
J11, J12, J13, J25, J28, J30, J31, J32, J33, J34, J101, J201: Con_01x02_2.5mm; JST_XH_B2B-XH-AM_1x02_P2.50mm_Vertical
J15: DB25_Female_MountingHoles; DSUB-25_Female_Horizontal_P2.77x2.84mm_EdgePinOffset4.94mm_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
J16, J18, J24, J37: Conn_01x04; PinHeader_1x04_P2.54mm_Vertical
J17: Conn_01x05; PinHeader_1x05_P2.54mm_Vertical
J19: Conn_01x07; PinHeader_1x07_P2.54mm_Vertical
J20: Conn_01x04_KK-254_0470531000; Molex_KK-254_0470531000_1x04_P2.54mm_Vertical_ForFAN
J23, J802: Con_01x02_0.1; PinHeader_1x02_P2.54mm_Vertical
J35, J36: Conn_02x05_Odd_Even; IDC-Header_2x05_P2.54mm_Vertical
J38, J39, J40, J41, J42, J55, J56, J57, J58, J59: Conn_02x06_Odd_Even; PinSocket_2x06_P2.54mm_Vertical
J43, J44, J45, J46, J47, J48, J49, J50, J51, J52, J53, J54: Conn_01x30; PinSocket_1x30_P2.54mm_Vertical
J801: Conn_01x03_0.1; PinHeader_1x03_P2.54mm_Vertical
J803: Screw_Terminal_01x04_5.08mm; TerminalBlock_Phoenix_MKDS-1,5-4-5.08_1x04_P5.08mm_Horizont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
J804: Screw_Terminal_01x02_5.08mm; TerminalBlock_Phoenix_MKDS-1,5-2-5.08_1x02_P5.08mm_Horizont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
J805: Con_01x02_0.1"; PinHeader_1x02_P2.54mm_Vertical
JP1, JP2, JP3, JP4, JP5, JP6, JP7, JP8, JP11, JP12, JP13, JP14, JP201, JP202, JP203, JP204: SolderJumper_3_Bridged12; SolderJumper-3_P1.3mm_Bridged12_RoundedPad1.0x1.5mm
JP9, JP10, JP15, JP205: MAX31850K; Adafruit_MAX31850K_Module
JP16, JP17, JP18: MAX31855; Adafruit_MAX31855_Module
JP19, JP20, JP21: MCP9600; Adafruit_MCP9600_Module
K801: Relay SRU-12VDC; Relay_SPDT_Omron-G5LE-1
Q1, Q3, Q4, Q9, Q10, Q11, Q12, Q13, Q14, Q801: BSS138; SOT-23
Q2: NCE01P30K; TO-252-2
R1, R2, R3, R4, R5, R6, R7, R8, R9, R10, R11, R12, R13, R15, R16, R31, R33, R48, R66, R73, R76, R79, R80, R82, R84, R88, R91, R92, R97, R98, R99, R109, R110, R111, R112, R118, R119, R121, R122, R140, R141, R144, R145, R146, R147, R148, R149, R150, R151, R152, R153, R154, R155, R156, R157, R158, R159, R160, R161, R162, R163, R164, R165, R166, R169, R801, R804, R806, R807: 1R0; R_0603_1608Metric_Pad0.98x0.95mm_HandSolder
R14, R18, R19, R20, R21, R22, R23, R24, R25, R26, R27, R28, R29, R36, R37, R38, R42, R45, R47, R100, R115, R116, R130, R172, R173, R201, R202, R203, R204, R803: 1K; R_0603_1608Metric_Pad0.98x0.95mm_HandSolder
R17, R30, R34, R35, R43, R74, R75, R85, R86, R87, R89, R90, R120, R805: DNI; R_0603_1608Metric_Pad0.98x0.95mm_HandSolder
R32: 4M7; R_0603_1608Metric_Pad0.98x0.95mm_HandSolder
R39, R40, R41, R44, R46, R67, R68, R69, R70, R81, R101, R103, R104, R105, R107, R113, R114, R123, R124, R126, R127, R142, R143, R180, R182, R183, R802: 10K; R_0603_1608Metric_Pad0.98x0.95mm_HandSolder
R71, R72, R129, R131, R132, R133, R134, R135, R136, R137, R138, R139, R170, R171, R174, R175, R176, R177, R178, R179: 39R; R_0603_1608Metric_Pad0.98x0.95mm_HandSolder
R77, R78, R83, R102, R125, R128, R167, R168, R181: 4K7; R_0603_1608Metric_Pad0.98x0.95mm_HandSolder
R106, R108: 20K; R_0603_1608Metric_Pad0.98x0.95mm_HandSolder
R117: 1M; R_0603_1608Metric_Pad0.98x0.95mm_HandSolder
R184, R185: 2K; R_0603_1608Metric_Pad0.98x0.95mm_HandSolder
S1, S2: SWITCH_TACTILE_SPST-NO_0.05A_24V; Switch_Tactile_THT_6x6mm
TP1, TP3, TP4, TP11, TP21: GND; TestPoint_Loop_D2.54mm_Drill1.5mm_Beaded
TP2: +12V; TestPoint_Loop_D2.54mm_Drill1.5mm_Beaded
TP5: +VccMAX31850; TestPoint_Loop_D2.54mm_Drill1.5mm_Beaded
TP6: +VccMAX31850_1; TestPoint_Loop_D2.54mm_Drill1.5mm_Beaded
TP7: +VccMAX31850_2; TestPoint_Loop_D2.54mm_Drill1.5mm_Beaded
TP8, TP201: +VccMAX31850_3; TestPoint_Loop_D2.54mm_Drill1.5mm_Beaded
TP9: +VccMAX3185; TestPoint_Loop_D2.54mm_Drill1.5mm_Beaded
TP10: +VccMCP9600; TestPoint_Loop_D2.54mm_Drill1.5mm_Beaded
TP17: I2C_VCC; TestPoint_Loop_D2.54mm_Drill1.5mm_Beaded
TP18: SCL_5V; TestPoint_Loop_D2.54mm_Drill1.5mm_Beaded
TP19: SDA_5V; TestPoint_Loop_D2.54mm_Drill1.5mm_Beaded
TP20: +24V; TestPoint_Loop_D2.54mm_Drill1.5mm_Beaded
TP999: TestPoint; TestPoint_Loop_D2.54mm_Drill1.5mm_Beaded
TPSwitched_Fan_Power1: Switched_Fan_Power; TestPoint_Loop_D2.54mm_Drill1.5mm_Beaded
TP_CIPO1: CIPO; TestPoint_Loop_D2.54mm_Drill1.5mm_Beaded
TP_COPI1: COPI; TestPoint_Loop_D2.54mm_Drill1.5mm_Beaded
TP_SCL1: SCL; TestPoint_Loop_D2.54mm_Drill1.5mm_Beaded
TP_SCL2: SCL1; TestPoint_Loop_D2.54mm_Drill1.5mm_Beaded
TP_SDA1: SDA; TestPoint_Loop_D2.54mm_Drill1.5mm_Beaded
TP_SDA2: SDA1; TestPoint_Loop_D2.54mm_Drill1.5mm_Beaded
TP_SD_DET1: TP_SD_DET; TestPoint_Loop_D2.54mm_Drill1.5mm_Beaded
TP_SPI_SCK1: SPI_SCK; TestPoint_Loop_D2.54mm_Drill1.5mm_Beaded
TP_VIN1: VIN1; TestPoint_Loop_D2.54mm_Drill1.5mm_Beaded

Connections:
5VHead: 5VHead101.1, A1.5V3 (5V), A1.5V4 (5V), J8.1, J8.2, R17.1, R30.1
+3.3V: +3.3V101.1, A1.3V3 (3.3V), D3.1 (K), J3.5, J801.1, R31.1, R37.2, R41.1, R66.1, R77.2, R78.2, R82.1, R84.1, R147.2, R161.2, R167.2, R168.2, R180.1, R182.1, R183.1
+5V: +5V101.1, A1.5V1 (5V), J3.4, R35.1, R36.2, R73.2, R74.2, R805.1
+12V: J11.1, J23.2, R75.2, R76.1, R89.1, R108.2, R118.1, R120.1, R804.1, TP2.1
+24V: J12.1, Q2.3 (S), R39.1, R88.1, R90.1, R106.2, R117.1, R119.1, TP20.1
/ACI: J10.13, J14.7
/ACI2: J27.13, J29.7
/AUX: J9.6, J10.12, J10.17, J10.21, J14.9, J14.10, R123.1, R140.1
/AUX2: J26.6, J27.12, J27.17, J27.21, J29.9, J29.10, R126.1, R141.1
/Blower controller/FAN1_FG: R11.1, R42.1, R43.1
/Blower controller/FAN_POWER: R10.1, R45.2, R46.1
/Blower controller/LOOPBACK13: J15.13, J18.4, R92.1
/Blower controller/LOOPBACK25: J15.25, J18.3, R91.1
/Blower controller/PWMFan1: C8.1, J15.1, J17.1, R33.1
/Blower controller/PWMFan2: C9.1, J15.2, J17.2
/Blower controller/PWMFan3: C10.1, J15.3, J17.3
/Blower controller/PWMFan4: C11.1, J15.4, J17.4
/Blower controller/Switched_Fan_Power: C4.1, J15.9, J15.10, J15.11, J15.12, J20.2, Q2.2 (D), R90.2, TPSwitched_Fan_Power1.1
/Blower controller/TachFan1: C7.1, D2.1 (K), J15.5, J16.1, J20.3, R35.2, R37.1, R42.2
/Blower controller/TachFan2: C6.1, J15.6, J16.2
/Blower controller/TachFan3: C5.1, J15.7, J16.3
/Blower controller/TachFan4: C3.1, J15.8, J16.4
/Blower controller/nFAN1_PWM: R12.1, R34.1, R38.2, R41.2
/D_PSU_RX: A1.D19 (D19/RX1), D_PSU_RX1.1, J2.6, R14.1
/D_PSU_RX2: A1.D17 (D17/RX2), D_PSU_RX2.1, J2.4, R100.1
/D_PSU_TX: A1.D18 (D18/TX1), D_PSU_TX1.1, J2.5, R15.1
/D_PSU_TX2: A1.D16 (D16/TX2), D_PSU_TX2.1, J2.3, R111.1
/Display Interface/+3v3_local: C24.1, J35.10, R161.1
/Display Interface/BTN_EN1: J36.3, R156.2
/Display Interface/BTN_EN2: J36.5, R157.2
/Display Interface/BTN_ENC: J35.2, J801.2, R155.2
/Display Interface/Beeper: J35.1, R149.1
/Display Interface/LCD_MOSI/CS: J35.3, R146.1
/Display Interface/LCD_RS: J35.4, R145.1
/Display Interface/LCD_SCK: J35.5, R144.1
/Display Interface/LED_Blue: J35.8, J805.2, R159.2
/Display Interface/LED_Green: J35.7, R160.2, R802.1, R803.1
/Display Interface/LED_Red: J35.6, J802.2, R158.2
/Display Interface/RESET: J36.8, R801.2
/Display Interface/SD_CS: J36.4, R152.1
/Display Interface/SD_DET: J36.7, R154.1
/Display Interface/SD_MISO: J36.1, R150.1
/Display Interface/SD_MOSI: J36.6, R151.1
/Display Interface/SD_SCK: J36.2, R153.1
/Display Interface/STOP/KILL: J36.10, R148.1, R801.1
/EN2+: J27.11, J29.6, R141.2
/EN2-: J27.9, J29.5, Q14.3 (D)
/EN+: J10.11, J14.6, R140.2
/EN-: J10.9, J14.5, Q13.3 (D)
/I2C_LevelShift/+3V3Local: C18.1, Q9.1 (G), Q10.1 (G), R66.2, R67.1, R68.1
/I2C_LevelShift/+5VLocal: C19.1, R69.1, R70.1, R73.1
/I2C_LevelShift/I2C_VCC: J23.1, J24.1, R74.1, R75.1, TP17.1
/I2C_LevelShift/SCL_3.3V: Q9.2 (S), R67.2, R166.1
/I2C_LevelShift/SCL_5V: C20.1, J1.2, J24.2, R71.1, TP18.1
/I2C_LevelShift/SDA_3.3V: Q10.2 (S), R68.2, R165.1
/I2C_LevelShift/SDA_5V: C21.1, J1.4, J24.4, R72.1, TP19.1
/PAR: J10.7, J14.4
/PAR2: J27.7, J29.4
/PS2_SCL: J27.19, R112.2
/PS2_SDA: J26.10, J27.20, R99.1
/PS_SCL: J10.19, R16.2
/PS_SDA: J9.10, J10.20, R13.1
/RX: J10.23, R15.2
/RX2: J27.23, R111.2
/SD_CS: A1.D4 (D4_CS1), J6.5, R152.2
/SSR Interface/+VFan: J30.1, R117.2, R118.2
/SSR Interface/-VFan: J30.2, R121.2
/SSR Interface/Heater1: R9.2, R47.1, R81.1
/SSR Interface/Heater2: R97.2, R113.1, R115.1
/SSR Interface/Heater3: R98.2, R114.1, R116.1
/SSR Interface/SSR1+: J13.1, R88.2, R89.2
/SSR Interface/SSR1-: J13.2, R48.2
/SSR Interface/SSR3+: J31.1, R119.2, R120.2
/SSR Interface/SSR3-: J31.2, R122.2
/TX: J10.24, R14.2, R184.2
/TX2: J27.24, R100.2, R185.2
/Thermocouple Amplifier I2C breakout board - MCP9600/+VccMCP9600: JP19.1, JP20.1, JP21.1, R31.2, TP10.1
/Thermocouple Amplifier I2C breakout board - MCP9600/SCL: JP19.3, JP20.3, JP21.3, R2.2
/Thermocouple Amplifier I2C breakout board - MCP9600/SDA: JP19.4, JP20.4, JP21.4, R4.2
/Thermocouple Amplifier SPI Interface breakout board - MAX31855 /+VccMAX31855: JP16.1, JP17.1, JP18.1, R30.2, R84.2, TP9.1
/Thermocouple Amplifier SPI Interface breakout board - MAX31855 /DO: JP16.4, JP17.4, JP18.4, R6.2
/Thermocouple Amplifier SPI Interface breakout board - MAX31855 /SCK: JP16.6, JP17.6, JP18.6, R5.2
/Thermocouple Amplifier SPI Interface breakout board - MAX31855 /nCS_1: JP16.5, R7.2
/Thermocouple Amplifier SPI Interface breakout board - MAX31855 /nCS_2: JP17.5, R3.2
/Thermocouple Amplifier SPI Interface breakout board - MAX31855 /nCS_3: JP18.5, R1.2
/Thermocouple Amplifier with 1-Wire Breakout Board - MAX31850K/+VccMAX31850: JP1.1 (A), JP2.3 (B), JP3.3 (B), JP4.3 (B), JP5.3 (B), JP6.1 (A), JP7.3 (B), JP8.3 (B), JP9.7, JP10.7, JP11.3 (B), JP12.3 (B), JP13.1 (A), JP14.3 (B), JP15.7, JP201.3 (B), JP202.3 (B), JP203.3 (B), JP204.1 (A), JP205.7, R17.2, R82.2, R83.2, TP5.1
/Thermocouple Amplifier with 1-Wire Breakout Board - MAX31850K/DATA: JP9.1, JP10.1, JP15.1, JP205.1, R83.1, R169.1
/VCI: J10.15, J14.8
/VCI2: J27.15, J29.8
/VO2+: J26.1, J27.2, R110.2
/VO2-: J26.2, J27.4, R109.2
/VO+: J9.1, J10.2, R80.2
/VO-: J9.2, J10.4, R79.2
/VS2+: J27.1, J28.1, J29.1, R110.1
/VS2-: J27.3, J28.2, J29.2, R109.1
/VS+: J10.1, J14.1, J25.1, R80.1
/VS-: J10.3, J14.2, J25.2, R79.1
/VSET: J9.4, J10.8
/VSET2: J26.4, J27.8
/V_ASSY_VERSIONING: J4.4, R137.2, R180.2, R181.2
AREF: A1.AREF, J7.8
BLOWER_ENABLE: A1.D22, J8.4, R10.2
BLOWER_TACH: A1.A0, J5.1, R11.2
CANR: A1.CANR (CANRX), J4.7
CANT: A1.CANT (CANTX), J4.8
CIPO: A1.MISO (SPI_MISO), R150.2, TP_CIPO1.1
COPI: A1.MOSI (SPI_MOSI), R6.1, R151.2, TP_COPI1.1
D0: A1.D0 (D0/RX0), J6.1
D1: A1.D1 (D1/TX0), J6.2
D25: J8.5, R178.1
D27: A1.D27, J8.7
D29: A1.D29, J8.9
D31: A1.D31, J8.11
D32: A1.D32, J8.14
D37: A1.D37, J8.17, R91.2
D38: A1.D38, J8.20, R8.2
D39: A1.D39, C1.1, J1.1, J8.19
D40: A1.D40, J8.22, R156.1
D41: A1.D41, J8.21, R157.1
D42: A1.D42, J8.24, R155.1
D43: A1.D43, J8.23, R158.1
D44: A1.D44, J8.26, R159.1
D45: A1.D45, J8.25, R160.1
D46: A1.D46, J8.28, R144.2
D47: A1.D47, J8.27, R145.2
D48: A1.D48, J8.30, R146.2
D50: A1.D50, J8.32, R149.2
D51: A1.D51, J8.31, R9.1
D52: A1.D52 (D52_CS2), J8.34, R97.1
D53: A1.D53, J8.33, R98.1
DAC0: A1.DAC0, J4.5
DAC1: A1.DAC1, J4.6
GND: A1.GND1 (GND), A1.GND2 (GND), A1.GND3 (GND), A1.GND4 (SPI_GND), A1.GND5 (GND), A1.GND6 (GND), C1.2, C2.2, C3.2, C4.2, C5.2, C6.2, C7.2, C8.2, C9.2, C10.2, C11.2, C18.2, C19.2, C20.2, C21.2, C22.1, C23.2, C24.2, D1.2 (A), D2.2 (A), D4.1 (K), H1.1, H2.1, H3.1, H4.1, H5.1, J1.0 (PAD), J1.3, J1.6, J1.7, J1.8, J1.9, J3.2, J3.3, J7.7, J8.35, J8.36, J9.3, J9.5, J9.7, J9.8, J9.9, J10.6, J10.10, J10.14, J10.16, J10.18, J10.22, J11.2, J12.2, J15.0 (PAD), J15.14, J15.15, J15.16, J15.17, J18.1, J20.1, J24.3, J26.3, J26.5, J26.7, J26.8, J26.9, J27.6, J27.10, J27.14, J27.16, J27.18, J27.22, J32.1, J32.2, J33.1, J33.2, J34.1, J34.2, J35.9, J36.9, J101.1, J201.1, J201.2, J801.3, J802.1, J803.1, J804.1, J805.1, JP1.3 (B), JP2.1 (A), JP3.1 (A), JP4.1 (A), JP5.1 (A), JP6.3 (B), JP7.1 (A), JP8.1 (A), JP9.8, JP10.8, JP11.1 (A), JP12.1 (A), JP13.3 (B), JP14.1 (A), JP15.8, JP16.3, JP17.3, JP18.3, JP19.2, JP20.2, JP21.2, JP201.1 (A), JP202.1 (A), JP203.1 (A), JP204.3 (B), JP205.8, Q1.2 (S), Q3.2 (S), Q4.2 (S), Q11.2 (S), Q12.2 (S), Q13.2 (S), Q14.2 (S), Q801.2 (S), R32.1, R43.2, R46.2, R81.2, R85.1, R86.1, R87.1, R102.1, R104.2, R113.2, R114.2, R125.1, R128.1, R142.2, R143.2, R162.2, R181.1, R184.1, R185.1, R802.2, S1.1, S1.2, S2.1, S2.2, TP1.1, TP3.1, TP4.1, TP11.1, TP21.1
LED_BUILTIN: A1.D13, R129.2, R130.1
LOOPBACK13: A1.D36, J8.18, R92.2
unnamed: A1.D10 (D10_CS0), R174.2
unnamed: A1.D14 (D14/TX3), J2.1
unnamed: A1.D15 (D15/RX3), J2.2
unnamed: A1.IORF (IOREF), J3.7
unnamed: A1.A5, R131.1
unnamed: A1.A7, R133.1
unnamed: A1.A8, R134.1
unnamed: A1.A9, R135.1
unnamed: A1.A10, R136.1
unnamed: A1.A11, R137.1
unnamed: A1.D2, R170.2
unnamed: A1.D3, R171.2
unnamed: A1.D6, R138.2
unnamed: A1.D7, R139.2
unnamed: A1.D8, R172.1
unnamed: A1.D11, R175.2
unnamed: A1.D12, R176.2
unnamed: A1.D23, R173.1
unnamed: A1.D24, R177.2
unnamed: A1.D25, R178.2
unnamed: A1.D26, R179.2
unnamed: A1.RST1 (RESET), J3.6
unnamed: C2.1, J1.5, R8.1
unnamed: C22.2, ISO1.1, ISO2.1, ISO3.1, ISO4.1, ISO5.1, R32.2
unnamed: D1.1 (K), J20.4, Q1.3 (D), R33.2, R34.2, R36.1
unnamed: D4.2 (A), R130.2
unnamed: D801.2 (A), K801.2, R806.2
unnamed: D801.1 (K), K801.5, R804.2, R805.2, R807.1
unnamed: F801.2, K801.1
unnamed: A1.VIN, J3.1, R76.2, TP_VIN1.1
unnamed: A1.ND, J3.8
unnamed: J4.1, R134.2
unnamed: J4.2, R135.2
unnamed: J4.3, R136.2
unnamed: A1.A4, J5.5
unnamed: J5.6, R131.2
unnamed: J5.7, R132.2
unnamed: J5.8, R133.2
unnamed: J6.3, R170.1
unnamed: J6.4, R171.1
unnamed: J7.3, R174.1
unnamed: J7.4, R175.1
unnamed: J7.5, R176.1
unnamed: J7.6, R129.1
unnamed: J8.6, R177.1
unnamed: J8.8, R179.1
unnamed: A1.D28, J8.10
unnamed: A1.D30, J8.12
unnamed: J15.18, J19.1
unnamed: J15.19, J19.2
unnamed: J15.20, J19.3
unnamed: J15.21, J19.4
unnamed: J15.22, J19.5
unnamed: J15.23, J19.6
unnamed: J15.24, J19.7
unnamed: J37.1, R147.1
unnamed: J37.2, R162.1
unnamed: J37.3, R163.1
unnamed: J37.4, R164.1
unnamed: J38.1, J38.3, J38.5, J38.7, J38.9, J38.11, J40.1, J40.3, J40.5, J40.7, J40.9, J40.11, J42.1, J42.3, J42.5, J42.7, J42.9, J42.11, J56.1, J56.3, J56.5, J56.7, J56.9, J56.11, J58.1, J58.3, J58.5, J58.7, J58.9, J58.11
unnamed: J38.2, J38.4, J38.6, J38.8, J38.10, J38.12, J40.2, J40.4, J40.6, J40.8, J40.10, J40.12, J42.2, J42.4, J42.6, J42.8, J42.10, J42.12, J56.2, J56.4, J56.6, J56.8, J56.10, J56.12, J58.2, J58.4, J58.6, J58.8, J58.10, J58.12
unnamed: J39.1, J39.3, J39.5, J39.7, J39.9, J39.11, J41.1, J41.3, J41.5, J41.7, J41.9, J41.11, J55.1, J55.3, J55.5, J55.7, J55.9, J55.11, J57.1, J57.3, J57.5, J57.7, J57.9, J57.11, J59.1, J59.3, J59.5, J59.7, J59.9, J59.11
unnamed: J39.2, J39.4, J39.6, J39.8, J39.10, J39.12, J41.2, J41.4, J41.6, J41.8, J41.10, J41.12, J55.2, J55.4, J55.6, J55.8, J55.10, J55.12, J57.2, J57.4, J57.6, J57.8, J57.10, J57.12, J59.2, J59.4, J59.6, J59.8, J59.10, J59.12
unnamed: J43.1, J44.1, J45.1, J46.1, J47.1, J48.1
unnamed: J43.2, J44.2, J45.2, J46.2, J47.2, J48.2
unnamed: J43.3, J44.3, J45.3, J46.3, J47.3, J48.3
unnamed: J43.4, J44.4, J45.4, J46.4, J47.4, J48.4
unnamed: J43.5, J44.5, J45.5, J46.5, J47.5, J48.5
unnamed: J43.6, J44.6, J45.6, J46.6, J47.6, J48.6
unnamed: J43.7, J44.7, J45.7, J46.7, J47.7, J48.7
unnamed: J43.8, J44.8, J45.8, J46.8, J47.8, J48.8
unnamed: J43.9, J44.9, J45.9, J46.9, J47.9, J48.9
unnamed: J43.10, J44.10, J45.10, J46.10, J47.10, J48.10
unnamed: J43.11, J44.11, J45.11, J46.11, J47.11, J48.11
unnamed: J43.12, J44.12, J45.12, J46.12, J47.12, J48.12
unnamed: J43.13, J44.13, J45.13, J46.13, J47.13, J48.13
unnamed: J43.14, J44.14, J45.14, J46.14, J47.14, J48.14
unnamed: J43.15, J44.15, J45.15, J46.15, J47.15, J48.15
unnamed: J43.16, J44.16, J45.16, J46.16, J47.16, J48.16
unnamed: J43.17, J44.17, J45.17, J46.17, J47.17, J48.17
unnamed: J43.18, J44.18, J45.18, J46.18, J47.18, J48.18
unnamed: J43.19, J44.19, J45.19, J46.19, J47.19, J48.19
unnamed: J43.20, J44.20, J45.20, J46.20, J47.20, J48.20
unnamed: J43.21, J44.21, J45.21, J46.21, J47.21, J48.21
unnamed: J43.22, J44.22, J45.22, J46.22, J47.22, J48.22
unnamed: J43.23, J44.23, J45.23, J46.23, J47.23, J48.23
unnamed: J43.24, J44.24, J45.24, J46.24, J47.24, J48.24
unnamed: J43.25, J44.25, J45.25, J46.25, J47.25, J48.25
unnamed: J43.26, J44.26, J45.26, J46.26, J47.26, J48.26
unnamed: J43.27, J44.27, J45.27, J46.27, J47.27, J48.27
unnamed: J43.28, J44.28, J45.28, J46.28, J47.28, J48.28
unnamed: J43.29, J44.29, J45.29, J46.29, J47.29, J48.29
unnamed: J43.30, J44.30, J45.30, J46.30, J47.30, J48.30
unnamed: J49.1, J50.1, J51.1, J52.1, J53.1, J54.1
unnamed: J49.2, J50.2, J51.2, J52.2, J53.2, J54.2
unnamed: J49.3, J50.3, J51.3, J52.3, J53.3, J54.3
unnamed: J49.4, J50.4, J51.4, J52.4, J53.4, J54.4
unnamed: J49.5, J50.5, J51.5, J52.5, J53.5, J54.5
unnamed: J49.6, J50.6, J51.6, J52.6, J53.6, J54.6
unnamed: J49.7, J50.7, J51.7, J52.7, J53.7, J54.7
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

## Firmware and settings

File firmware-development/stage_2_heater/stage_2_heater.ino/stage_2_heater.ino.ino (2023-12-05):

//test config for display, thermocouple and ethernet
//Works with Control board V1.1
//Author: Lawrence Kincheloe
//

// https://github.com/adafruit/Adafruit-MAX31855-library
// https://ryand.io/AutoPID/
// https://github.com/mprograms/SimpleRotary
// https://github.com/olikraus/u8g2
// //
#include <Arduino.h>
#include <U8g2lib.h>
#include <MUIU8g2.h>
#include <SimpleRotary.h>
#include <SPI.h>
#include <Wire.h>
#include "Adafruit_MAX31855.h"
#include <AutoPID.h>

#include <Ethernet.h>
#include <EthernetUdp.h>

// Example creating a thermocouple instance with software SPI on any three
// digital IO pins.
// #define MAXDO   3
// #define EXT1_MAXCS   10
// #define EXT2_MAXCS   11
// #define INT1_MAXCS   12
// #define MAXCLK  5

#define EXT1_OUTPUT_PIN 33
#define EXT2_OUTPUT_PIN 34
#define INT1_OUTPUT_PIN 35

#define LCD_CLOCK 13 // Clock (Common), sometimes called SCK or SCL
#define LCD_MOSI 11  // MOSI (common), sometimes called SDA or DATA
#define LCD_RESET 46 // LCD reset, sometimes called RST or RSTB
#define LCD_CS  48    // LCD CS, sometimes called EN or SS
#define LCD_RS 47     // LCD RS, sometimes called A0 or DC, not used

#define  LED_PIN_RED  43
#define  LED_PIN_GREEN 44
#define  LED_PIN_BLUE 45

#define TEMP_READ_DELAY 800 //can only read digital temp sensor every ~750ms

//pid settings and gains
#define OUTPUT_MIN 0
#define OUTPUT_MAX 255
#define KP .12
#define KI .0003
#define KD 0

// SimpleRotary Library
// https://github.com/mprograms/SimpleRotary
// Pin A, Pin B, Button Pin
#define ENA_PIN 40
#define ENB_PIN 41
#define ENC_PIN 42
SimpleRotary rotary(ENA_PIN, ENB_PIN, ENC_PIN);


U8G2_ST7567_JLX12864_1_4W_SW_SPI u8g2(U8G2_R2,
                                      LCD_CLOCK,
                                      LCD_MOSI,
                                      LCD_CS,
                                      LCD_RS,
                                      LCD_RESET);

// // Initialize the Thermocouple
// Adafruit_MAX31855 ext1_thermocouple(MAXCLK, EXT1_MAXCS, MAXDO);
// Adafruit_MAX31855 ext2_thermocouple(MAXCLK, EXT2_MAXCS, MAXDO);
// Adafruit_MAX31855 int1_thermocouple(MAXCLK, INT1_MAXCS, MAXDO);

MUIU8G2 mui;

/*
  global variables which form the communication gateway between the user interface and the rest of the code
*/

double ext1_temperature = 0;
double ext2_temperature = 0;
double int1_temperature = 0;
double ext1_setPoint = 0;
double ext2_setPoint = 0;
double int1_setPoint = 0;
double ext1_outputVal = 0;
double ext2_outputVal = 0;
double int1_outputVal = 0;

uint16_t heater_idx = 0;

uint8_t num_value = 0;
uint8_t bar_value = 0;

struct ramp_rate_setpoint {
  double temperature, setPoint, outputVal;
  
};

AutoPID ext1_PID(&ext1_temperature, &ext1_setPoint, &ext1_outputVal, OUTPUT_MIN, OUTPUT_MAX, KP, KI, KD);
AutoPID ext2_PID(&ext2_temperature, &ext2_setPoint, &ext2_outputVal, OUTPUT_MIN, OUTPUT_MAX, KP, KI, KD);
AutoPID int1_PID(&int1_temperature, &int1_setPoint, &int1_outputVal, OUTPUT_MIN, OUTPUT_MAX, KP, KI, KD);




unsigned long lastTempUpdate; //tracks clock time of last temp update


//call repeatedly in loop, only updates after a certain time interval
//returns true if update happened
bool updateTemperature() {
  if ((millis() - lastTempUpdate) > TEMP_READ_DELAY) {
    // ext1_temperature = ext1_thermocouple.readCelsius(); //get temp reading
    // ext2_temperature = ext2_thermocouple.readCelsius(); //get temp reading
    // int1_temperature = int1_thermocouple.readCelsius(); //get temp reading
  if (isnan(ext1_temperature))
  {
     u8g2.print("ext1 T/C Problem");
  }
  if (isnan(ext2_temperature))
  {
     u8g2.print("ext2 T/C Problem");
  }
  if (isnan(int1_temperature))
  {
     u8g2.print("int1 T/C Problem");
  }
    
    lastTempUpdate = millis();

    return true;
  }
  return false;
}//void updateTemperature

/*
  list of heater names
*/
const char *heater[] = { "external 1", "External 2", "Internal 1"};
//set of operational states for the device
//
//
//
//
const char *heater_states[] = { "idle","preheat", "ramp-up", "operational" , "ramp-down" };


uint8_t show_temp_data(mui_t *ui, uint8_t msg) {
  if ( msg == MUIF_MSG_DRAW ) {
    u8g2_uint_t x = mui_get_x(ui);
    u8g2_uint_t y = mui_get_y(ui);
    u8g2.setCursor(x+5, y);
    u8g2.print("ext1:");
    u8g2.setCursor(x+50, y);
    u8g2.print(ext1_temperature);

    u8g2.setCursor(x+5, y+12);
    u8g2.print("ext2:");
    u8g2.setCursor(x+50, y+12);
    u8g2.print(ext2_temperature);

    u8g2.setCursor(x+5, y+24);
    u8g2.print("int1:");
    u8g2.setCursor(x+50, y+24);
    u8g2.print(int1_temperature);  
    //u8g2.print("=");  
    //u8g2.print(animals[animal_idx]);  
  }
  return 0;
}

uint16_t heater_states_get_param(void *data) {
  return sizeof(heater)/sizeof(*heater);    /* number of heaters */
}

const char *heater_states_get_str(void *data, uint16_t index) {
  return heater_states[index];
}

uint8_t mui_hrule(mui_t *ui, uint8_t msg) {
  if ( msg == MUIF_MSG_DRAW ) {
      u8g2.drawHLine(0, mui_get_y(ui), u8g2.getDisplayWidth());
  }
  return 0;
}

muif_t muif_list[] = {
  MUIF_U8G2_FONT_STYLE(0, u8g2_font_helvR08_tr),        /* regular font */
  MUIF_U8G2_FONT_STYLE(1, u8g2_font_helvB08_tr),        /* bold font */

  MUIF_RO("HR", mui_hrule),
  MUIF_U8G2_LABEL(),
  MUIF_RO("GP",mui_u8g2_goto_data),  
  MUIF_BUTTON("GC", mui_u8g2_goto_form_w1_pi),

  MUIF_U8G2_U8_MIN_MAX("NV", &num_value, 0, 99, mui_u8g2_u8_min_max_wm_mud_pi),
  MUIF_U8G2_U8_MIN_MAX_STEP("NB", &bar_value, 0, 16, 1, MUI_MMS_2X_BAR, mui_u8g2_u8_bar_wm_mud_pf),
  MUIF_U8G2_U16_LIST("NA", &heater_idx, NULL, heater_states_get_str, heater_states_get_param, mui_u8g2_u16_list_line_wa_mud_pi),

  /* register custom function to show the data */
  MUIF_RO("SH", show_temp_data), 

  /* a button for the menu... */
  MUIF_BUTTON("GO", mui_u8g2_btn_goto_wm_fi)  
};

fds_t fds_data[] = 

MUI_FORM(1)
MUI_STYLE(1)
MUI_LABEL(5, 8, "Stage2 Heater")
MUI_STYLE(0)
MUI_XY("HR", 0,11)
MUI_DATA("GP", 
    MUI_10 "Enter Data|"
    MUI_12 "Show Data")
MUI_XYA("GC", 5, 24, 0) 
MUI_XYA("GC", 5, 36, 1) 

MUI_FORM(10)
MUI_STYLE(1)
MUI_LABEL(5, 8, "Config Ramp Rates")
MUI_XY("HR", 0,11)
MUI_STYLE(0)
MUI_LABEL(5,23, "Num:")
MUI_LABEL(5,36, "Bar:")
MUI_LABEL(5,49, "Animal:")
MUI_XY("NV", 50, 23)
MUI_XY("NB", 50, 36)
MUI_XYA("NA", 50, 49, 44)
MUI_XYAT("GO", 114, 60, 1, " Ok ") 

MUI_FORM(12)
MUI_STYLE(1)
MUI_LABEL(5, 8, "Show Data")
MUI_XY("HR", 0,11)
MUI_STYLE(0)
MUI_XY("SH", 0, 23)
MUI_XYAT("GO", 114, 60, 1, " Ok ") 

;


char timeServer[] = "time.nist.gov";
char mcogs[] = "mcogs.coslabs.com";

// #define localPort 2390
#define localPort 57573

#define UDP_TIMEOUT 2000

unsigned long epoch = 0; // global to hold time

// Enter a MAC address and IP address for your controller below.
// The IP address will be dependent on your local network:
// This is the mac for ROB READs Due in Austin TX! Change if you are installing elsewhere
// until we can get dynamic mac addresss solved.
//byte mac[] = {
//   0xDE, 0xAD, 0xBE, 0xEF, 0xFE, 0xED
//};

byte mac[] = {
   0xDE, 0xAD, 0xBE, 0xEF, 0xFE, 0xFF
};
//byte mac[] = {
//   0xD4, 0x3D, 0x39, 0x39, 0x69, 0x5a
//};

char macString[20];

IPAddress ip(192, 168, 1, 177);

// buffers for receiving and sending data
#define buffMax 64*1024
byte packetBuffer[buffMax]; //buffer to hold incoming packet,

// An EthernetUDP instance to let us send and receive packets over UDP
EthernetUDP Udp;
#define W5200_CS  10
#define SDCARD_CS 4


void
printPacketInfo(int packetsize) {
    Serial.print(F("UDP Packet received, size "));
    Serial.println(packetsize);
    Serial.print(F("From "));
    IPAddress remoteIp = Udp.remoteIP();
    Serial.print(remoteIp);
    Serial.print(F(", port "));
    Serial.println(Udp.remotePort());
}

void
printTime(unsigned long time) {
  Serial.print(F("Unix time = "));
  Serial.println(time);
  // print the hour, minute and second:
  Serial.print(F("The UTC time is "));       // UTC is the time at Greenwich Meridian (GMT)
  Serial.print((time  % 86400L) / 3600); // print the hour (86400 equals secs per day)
  Serial.print(F(":"));

  // In the first 10 minutes of each hour, we'll want a leading '0'
  if (((time % 3600) / 60) < 10) Serial.print(F("0"));

  // print the minute (3600 equals secs per minute)
  Serial.print((time  % 3600) / 60);
  Serial.print(F(":"));

  // In the first 10 seconds of each minute, we'll want a leading '0'
  if ((time % 60) < 10) Serial.print(F("0"));

  Serial.println(time % 60); // print the second
}

// send an NTP request to the time server at the given address
unsigned long
getTime() {
  #define NTP_PACKET_SIZE 48
  byte ntpBuffer[NTP_PACKET_SIZE];

  memset(ntpBuffer, 0, NTP_PACKET_SIZE);  // set all bytes in buffer to 0

  // Initialize values needed to form NTP request
  ntpBuffer[0] = 0b11100011;   // LI, Version, Mode
  ntpBuffer[1] = 0;     // Stratum, or type of clock
  ntpBuffer[2] = 6;     // Polling Interval
  ntpBuffer[3] = 0xEC;  // Peer Clock Precision
  // 8 bytes of zero for Root Delay & Root Dispersion
  ntpBuffer[12]  = 49;
  ntpBuffer[13]  = 0x4E;
  ntpBuffer[14]  = 49;
  ntpBuffer[15]  = 52;

  // all NTP fields have been given values, now
  // you can send a packet requesting a timestamp:
  Udp.beginPacket(timeServer, 123); //NTP requests are to port 123
  Udp.write(ntpBuffer, NTP_PACKET_SIZE);
  Udp.endPacket();

  unsigned long startMs = millis();
  while (!Udp.available() && (millis() - startMs) < UDP_TIMEOUT) {}

  // if there's data available, read a packet
  int packetSize = Udp.parsePacket();

  if (packetSize) {
    //    printPacketInfo(packetSize);

    Udp.read(ntpBuffer, NTP_PACKET_SIZE);

    // the timestamp starts at byte 40 of the received packet and is four bytes,
    // or two words, long. First, esxtract the two words:
    unsigned long highWord = word(ntpBuffer[40], ntpBuffer[41]);
    unsigned long lowWord = word(ntpBuffer[42], ntpBuffer[43]);

    // combine the four bytes (two words) into a long integer
    // this is NTP time (seconds since Jan 1 1900):
    unsigned long secsSince1900 = highWord << 16 | lowWord;

    // now convert NTP time into everyday time:
    // Unix time starts on Jan 1 1970. In seconds, that's 2208988800:
    const unsigned long seventyYears = 2208988800UL;
    // subtract seventy years:
    return secsSince1900 - seventyYears;
  }
  return 0;
}

void
sendData(char *data) {
  Udp.beginPacket(mcogs, 57573);
  Udp.write("PUT ", 4);
  Udp.write("/", 1);
  Udp.write(macString, 17);
  Udp.write("/", 1);
  Udp.write("Data\n", 5);

  Udp.write("{ \"TimeStamp\": ", 15);
  char ts[15];
  sprintf(ts, "%ld", epoch);
  Udp.write(ts, strlen(ts));
  if (data && strlen(data)) Udp.write(data, strlen(data));
  Udp.write("}", 1);
  Udp.endPacket();

  unsigned long startMs = millis();
  while (!Udp.available() && (millis() - startMs) < UDP_TIMEOUT) {}
}

void getConfig() {
  Udp.beginPacket(mcogs, 57573);
  Udp.write("GET ", 4);
  Udp.write("/", 1);
  Udp.write(macString, 17);
  Udp.write("/", 1);
  Udp.write("Params\n", 7);
  Udp.endPacket();

  unsigned long startMs = millis();
  while (!Udp.available() && (millis() - startMs) < UDP_TIMEOUT) {}
  
  int packetSize = Udp.parsePacket();

  if (packetSize) {
    Serial.print(F("UDP Packet received, size "));
    Serial.println(packetSize);
    Serial.print(F("From "));
    IPAddress remoteIp = Udp.remoteIP();
    Serial.print(remoteIp);
    Serial.print(F(", port "));
    Serial.println(Udp.remotePort());

    // We've received a packet, read the data from it into the buffer
    //    byte b[1024];
    Udp.read(packetBuffer, packetSize);
    packetBuffer[packetSize] = '\0';

    String config = String((char *)packetBuffer);
    Serial.println(config);
  }
}

char cmd[1024];
int lastnonce = 0;

int getcontrol() {
  unsigned long startMs = millis();
  while (!Udp.available() && (millis() - startMs) < UDP_TIMEOUT) {}

  // if there's data available, read a packet
  int packetSize = Udp.parsePacket();
  if (packetSize) {
    //    printPacketInfo(packetSize);
    // Changing on a supposition that this line is an error - rlr
    // Udp.read(buffer, packetSize);
    Udp.read(packetBuffer, packetSize);
  }

}

void printNet() {
  Ethernet.MACAddress(mac);
  Serial.print(F("The MAC address is: "));
  for (byte octet = 0; octet < 6; octet++) {
    Serial.print(mac[octet], HEX);
    if (octet < 5) {
      Serial.print(F(':'));
    }
  }
  Serial.println();
  Serial.print(F("IP address: "));
  Serial.println(Ethernet.localIP());
  Serial.print(F("Subnet Mask: "));
  Serial.println(Ethernet.subnetMask());
  Serial.print(F("Gateway: "));
  Serial.println(Ethernet.gatewayIP());
  Serial.print(F("DNS Server: "));
  Serial.println(Ethernet.dnsServerIP());
}

void setup() {


  
  
 // ext1_myPID.setBangBang(4);
 // ext1_myPID.setTimeStep(4000);
  
 // ext2_myPID.setBangBang(4);
 // ext2_myPID.setTimeStep(4000);
  
  //int1_myPID.setBangBang(4);
  //int1_myPID.setTimeStep(4000);
  
  
  //define rotary encoder pinout
  pinMode(ENA_PIN, INPUT);
  pinMode(ENB_PIN, INPUT);
  pinMode(ENC_PIN, INPUT);

  //define SSR configuration
  pinMode(EXT1_OUTPUT_PIN, OUTPUT);
  pinMode(EXT2_OUTPUT_PIN, OUTPUT);
  pinMode(INT1_OUTPUT_PIN, OUTPUT);
  //define SSR initial output
  digitalWrite(EXT1_OUTPUT_PIN, LOW);
  digitalWrite(EXT2_OUTPUT_PIN, LOW);
  digitalWrite(INT1_OUTPUT_PIN, LOW);
  //define display pinout
  pinMode(LED_PIN_RED, OUTPUT);
  pinMode(LED_PIN_GREEN, OUTPUT);
  pinMode(LED_PIN_BLUE, OUTPUT);
 //define SSR initial output
  digitalWrite(LED_PIN_RED, HIGH);
  digitalWrite(LED_PIN_GREEN, HIGH);
  digitalWrite(LED_PIN_BLUE, HIGH);
  
  u8g2.begin();
  mui.begin(u8g2, fds_data, muif_list, sizeof(muif_list)/sizeof(muif_t));
  mui.gotoForm(/* form_id= */ 1, /* initial_cursor_position= */ 0);
 delay(500);
 
  // if (!ext1_thermocouple.begin()) {
  //   u8g2.print("ext1 ERROR.");
  //   while (1) delay(10);
  // }
  // if (!ext2_thermocouple.begin()) {
  //   u8g2.print("ext2 ERROR.");
  //   while (1) delay(10);
  // }
  // if (!int1_thermocouple.begin()) {
  //   u8g2.print("int1 ERROR.");
  //   while (1) delay(10);
  // }
  u8g2.print("DONE.");


    // Open serial communications and wait for port to open:
  Serial.begin(9600);
  while (!Serial) {
    ; // wait for serial port to connect. Needed for native USB port only
  }

  Serial.println(F("starting"));

  //  // start the Ethernet
  // if(!Ethernet.begin(mac))
  // {
  //     u8g2.print("ext1 ERROR.");
  //   while (1) delay(10);
  // }

  // // Check for Ethernet hardware present
  // if (Ethernet.hardwareStatus() == EthernetNoHardware) {
  //   Serial.println("Ethernet shield was not found.  Sorry, can't run without hardware. :(");
  //   while (true) {
  //     delay(1); // do nothing, no point running without Ethernet hardware
  //   }
  // }
  // if (Ethernet.linkStatus() == LinkOFF) {
  //   Serial.println("Ethernet cable is not connected.");
  // }
  // Udp.begin(localPort);

  // sprintf(macString, "%X:%X:%X:%X:%X:%X", mac[0], mac[1], mac[2], mac[3], mac[4], mac[5]);

  // printNet();
  // delay(1000);

  // for (int i = 10; epoch == 0 && i > 0; i--) {
  //   epoch = getTime();
  //   delay(500);
  // }
  // if (epoch == 0) Serial.println(F("Can't get time!"));
  // else printTime(epoch);
  

  // // start UDP
  // Udp.begin(localPort);
}

uint8_t is_redraw = 1;
uint8_t rotary_event = 0; // 0 = not turning, 1 = CW, 2 = CCW
uint8_t push_event = 0; // 0 = not pushed, 1 = pushed

void detect_events(void) {
  uint8_t tmp;
  
  // 0 = not pushed, 1 = pushed  
  tmp = rotary.push();
  if ( tmp != 0 )         // only assign the push event, never clear the event here
    push_event = tmp;
    
  // 0 = not turning, 1 = CW, 2 = CCW
  tmp = rotary.rotate();
  if ( tmp != 0 )       // only assign the rotation event, never clear the event here
    rotary_event = tmp;    
  
  
}
void handle_events(void) {
  // 0 = not pushed, 1 = pushed  
  if ( push_event == 1 ) {
      mui.sendSelect();
      is_redraw = 1;
      push_event = 0;
  }
  
  // 0 = not turning, 1 = CW, 2 = CCW
  if ( rotary_event == 1 ) {
    mui.nextField();
    is_redraw = 1;
    rotary_event = 0;
  }
  
  if ( rotary_event == 2 ) {
    mui.prevField();
    is_redraw = 1;
    rotary_event = 0;
  }    
}

void loop() {
  // put your main code here, to run repeatedly:

  //updateTemperature();
 // setPoint = analogRead(POT_PIN);
  ext1_PID.run(); //call every loop, updates automatically at certain time interval
  ext2_PID.run();
  int1_PID.run();
  
  analogWrite(EXT1_OUTPUT_PIN, ext1_outputVal);
  analogWrite(EXT2_OUTPUT_PIN, ext2_outputVal);
  analogWrite(INT1_OUTPUT_PIN, int1_outputVal);
  
  //digitalWrite(LED_PIN, myPID.atSetPoint(1)); //light up LED when we're at setpoint +-1 degree
  if( ext1_PID.atSetPoint(1))
  {
  }
  if( ext2_PID.atSetPoint(1))
  {
  }
  if( int1_PID.atSetPoint(1))
  {
  }


  //   // send a reply to the IP address and port that sent us the packet we received
  //   //  Serial.println("calling getConfig()!");
  // getConfig();
  // sendData(NULL);
  // //delay(20000);
  
  
  
  /* check whether the menu is active */
  if ( mui.isFormActive() ) {

    /* update the display content, if the redraw flag is set */
    if ( is_redraw ) {
      u8g2.firstPage();
      do {
          detect_events();
          mui.draw();
          detect_events();
      } while( u8g2.nextPage() );
      is_redraw = 0;                    /* clear the redraw flag */
    }

    detect_events();
    handle_events();
      
  } else {
      /* the menu should never become inactive, but if so, then restart the menu system */
      mui.gotoForm(/* form_id= */ 1, /* initial_cursor_position= */ 0);
  }
}

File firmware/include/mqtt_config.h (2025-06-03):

#ifndef MQTT_CONFIG_H
#define MQTT_CONFIG_H

// Note: Client certificate authentication is handled by embedding certificates
// in firmware/include/certificates.h and configuring the TLS client.
// No specific flags here are needed if always using embedded certs when TLS is active.

// MQTT Broker Details
// IMPORTANT: REPLACE "192.168.1.100" WITH YOUR ACTUAL MQTT BROKER IP ADDRESS OR HOSTNAME
#define MQTT_BROKER_IP "192.168.1.100" // Replace with your MQTT Broker's IP or hostname

// Standard MQTT Non-Secure port (MQTT over TCP, typically 1883)
#define MQTT_BROKER_PORT 1883

// MQTT Broker WebSocket URI (e.g., "ws://broker.example.com:80/mqtt" or "wss://broker.example.com:443/mqtt")
// Leave blank if not using WebSockets. If filled, this may take precedence over MQTT_BROKER_IP and MQTT_BROKER_PORT for connection.
#define MQTT_BROKER_WEBSOCKET_URI ""

// Standard MQTT Secure port (MQTTS over TCP, typically 8883)
// Used if MQTT_BROKER_WEBSOCKET_URI is blank and a secure TCP connection is desired.
#define MQTT_BROKER_SECURE_PORT 8883


// MQTT Credentials (optional, leave blank if not used)
#define MQTT_USERNAME ""
#define MQTT_PASSWORD ""

// MQTT Client ID prefix (MAC address will be appended)
#define MQTT_CLIENT_ID_PREFIX "OEDCS-"


// LWT (Last Will and Testament) Configuration
#define LWT_TOPIC_SUFFIX "/status" // MAC address will be prepended, e.g., devices/XX:XX:XX:XX:XX:XX/status
#define LWT_MESSAGE_ONLINE "online"
#define LWT_MESSAGE_OFFLINE "offline"
#define LWT_QOS 0
#define LWT_RETAIN true

// Data and Event Topics
// Base topic for device-specific communications
#define MQTT_DEVICE_BASE_TOPIC "devices/"
#define MQTT_DATA_TOPIC_SUFFIX "/data"   // MAC address will be prepended after base topic
#define MQTT_EVENT_TOPIC_SUFFIX "/events" // MAC address will be prepended after base topic

#endif // MQTT_CONFIG_H

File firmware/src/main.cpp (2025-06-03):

// Program information
#define COMPANY_NAME "pubinv.org "
#define PROG_NAME "OEDCS"
#define OEDCS_VERSION "; Rev: 0.4.16"  // potential fix to issue #411
#define DEVICE_UNDER_TEST "Hardware: Due"  // A model number
#define LICENSE "GNU Affero General Public License, version 3 "


#ifdef ARDUINO
#include <Arduino.h>
#endif

#include <core.h>
#include <cog_hal.h>

#include <flash.h>
#include <network_task.h>
#include <cog_task.h>
#include <OEDCS_serial_input_task.h>
#include <fault_task.h>
#include <duty_cycle_task.h>
#include <heater_pid_task.h>
#include <read_temps_task.h>
#include <serialReportTask.h>
#include <OEDCSNetworkTask.h>
#include <heartbeat_task.h>
#include <panel_blink_task.h>
#include <log_recorder_task.h>
// #include <display_task.h>
#include <shutdown_button_task.h>

#ifdef TEST_FANS_ONLY
#include <fanTEST_task.h>
#endif

using namespace CogCore;
static Core core;

/***** Declare your tasks here *****/
// DisplayTask displayTask;
CogApp::OEDCSNetworkTask OEDCSNetworkTask;
CogApp::CogTask cogTask;
CogApp::OEDCSSerialInputTask oedcsSerialInputTask;
CogApp::FaultTask faultTask;

CogApp::HeartbeatTask heartbeatTask;
CogApp::PanelBlinkTask panelBlinkTask;
CogApp::Log_Recorder_Task logRecorderTask;


HeaterPIDTask heaterPIDTask;
DutyCycleTask dutyCycleTask;
ReadTempsTask readTempsTask;
SerialReportTask serialReportTask;
ShutdownButtonTask shutdownButtonTask;
#include <machine.h>

MachineConfig machineConfig;
/***********************************/

// #define ETHERNET_REQUIRED 1
#define ETHERNET_REQUIRED 0 //No ethernet.


// This is to allow a code idiom compatible with the way
// the machine config is found  inside the Tasks
MachineConfig *getConfig() {
  return &machineConfig;
}

// TODO: we need to have setups for individual pieces
// of the Hardware Abstraction Layer
// I don't know why this didn't work inside the core.cpp file!!!


void setup()
{

  // TODO: This should be moved to a relay position.


  CogCore::serialBegin(115200UL);
  delay(500);

   // WARNING! need 5 second delay for pio compiler it seems
  // DO NOT REMOVE THIS STATEMENT!
  delay(5000);

  // We're doing this here because the Core may not be initialized
  watchdogReset();


  // TODO: consider doing this....
    // Serial.begin(BAUDRATE);
    // while (!Serial) {
    //   watchdogReset();
    // }
    // Debug<const char *>("starting\n");

  //Debug<const char *>("Starting COG...\n");
  Debug<const char *>("Starting ");
  Debug<const char *>(PROG_NAME);
  Debug<const char *>(OEDCS_VERSION);
  Debug<const char *>("\n");

  Debug<const char *>("Build: ");
  Debug<const char *>((__DATE__ " " __TIME__));
  Debug<const char *>("\n");

   //Print out the reset reason
  Debug<const char *>("=================\n");
  Debug<const char *>("ResetCause: ");
  switch(getResetCause()) {
  case 0: Debug<const char *>("general\n"); break;
  case 1: Debug<const char *>("backup\n"); break;
  case 2: Debug<const char *>("watchdog\n"); break;
  case 3: Debug<const char *>("software\n"); break;
  case 4: Debug<const char *>("user\n"); break;
  }
  Debug<const char *>("=================\n");

  // TODO: consider doing this....
    // Serial.begin(BAUDRATE);
    // while (!Serial) {
    //   watchdogReset();
    // }
    // Debug<const char *>("starting\n");

  delay(100);
  if (core.Boot() == false) {
      ErrorHandler::Log(ErrorLevel::Critical, ErrorCode::CoreFailedToBoot);
      // TODO: Output error message
      //return EXIT_FAILURE;
      return;
  }
  Debug<const char *>("Core booted...\n");
  delay(100);

  core.ResetAllWatchdogs();

  machineConfig.init();

  //  Eventually we will migrate all hardware to the COG_HAL..
  COG_HAL* hal = new COG_HAL();

  machineConfig.hal = hal;

  machineConfig.hal->DEBUG_HAL = 0;
  bool initSuccess  = machineConfig.hal->init();
  if (!initSuccess) {
    Debug<const char *>("Could not init Hardware Abstraction Layer Properly!\n");
    delay(50);
    abort();
  } else {
    Debug<const char *>("Successful init of Hardware Abstraction Layer!\n");
  }

  // Now we will set the machine state to "Off"
  getConfig()->ms = Off;

  /***** Configure and add your tasks here *****/

  CogCore::TaskProperties readTempsProperties;
  readTempsProperties.name = "readTemps";
  readTempsProperties.id = 19;
  readTempsProperties.period = readTempsTask.PERIOD_MS;
  readTempsProperties.priority = CogCore::TaskPriority::High;
  readTempsProperties.state_and_config = (void *) &machineConfig;
  bool readAdd = core.AddTask(&readTempsTask, &readTempsProperties);
  if (!readAdd) {
    CogCore::Debug<const char *>("ReadTemps Task add failed\n");
    abort();
  }

  CogCore::TaskProperties serialReportProperties;
  serialReportProperties.name = "serialReportTemps";
  serialReportProperties.id = 20;
  serialReportProperties.period = serialReportTask.PERIOD_MS;
  serialReportProperties.priority = CogCore::TaskPriority::High;
  serialReportProperties.state_and_config = (void *) &machineConfig;
  bool serialReportAdd = core.AddTask(&serialReportTask, &serialReportProperties);
  if (!serialReportAdd) {
    CogCore::Debug<const char *>("serialReport Task add failed\n");
    abort();
  }
  CogCore::TaskProperties cogProperties;
  cogProperties.name = "cog";
  cogProperties.id = 21;
  cogProperties.period = cogTask.PERIOD_MS;
  cogProperties.priority = CogCore::TaskPriority::High;
  cogProperties.state_and_config = (void *) &machineConfig;
  bool cogAdd = core.AddTask(&cogTask, &cogProperties);
  if (!cogAdd) {
    CogCore::Debug<const char *>("Cognitive Task add failed\n");
    abort();
  }

  getConfig()->ms = Off;
  cogTask.heaterPIDTask = &heaterPIDTask;


  CogCore::TaskProperties oedcsSerialProperties;
  oedcsSerialProperties.name = "oedcsSerial";
  oedcsSerialProperties.id = 22;
  oedcsSerialProperties.period = oedcsSerialInputTask.PERIOD_MS;
  oedcsSerialProperties.priority = CogCore::TaskPriority::High;
  oedcsSerialProperties.state_and_config = (void *) &machineConfig;
   bool oedcsSerialAdd = core.AddTask(&oedcsSerialInputTask, &oedcsSerialProperties);
  if (!oedcsSerialAdd) {
    CogCore::Debug<const char *>("SerialInputProperties add failed\n");
    abort();
  }
  oedcsSerialInputTask.cogTask = &cogTask;

  if (ETHERNET_REQUIRED) {
    CogCore::TaskProperties OEDCSNetworkProperties;
    OEDCSNetworkProperties.name = "OEDCSNetwork";
    OEDCSNetworkProperties.id = 24;
    OEDCSNetworkProperties.period = 5000;
    OEDCSNetworkProperties.priority = CogCore::TaskPriority::High;
    OEDCSNetworkProperties.state_and_config = (void *) &machineConfig;

    bool OEDCSNetwork = core.AddTask(&OEDCSNetworkTask, &OEDCSNetworkProperties);
    if (!OEDCSNetwork) {
      CogCore::Debug<const char *>("Retrieve Script UDP\n");
      abort();
    }
  }

  dutyCycleTask.whichHeater = (Stage2Heater) 0;
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

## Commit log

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2023-11-24 testing the high-temperature ability, got stuck at 370C
    [main.cpp]
2023-11-27 removed Ox in favor of Cog
    Per issue
    https://github.com/PubInv/NASA-MCOG/issues/4
    [main.cpp, stage2_heater.cpp, test_SanyoAceB97.cpp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]
2023-11-29 intermediate checkin, some bugs fixed, but targetTemp being used incorrectly
    [main.cpp]
2023-11-30 Update gitignore not to ignore FreeCAD files. Add the BigTree holes in pannel FreeCAD drawing.
    [BigTreeTechHolesInPanel.FCStd]
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2023-12-05 added initial graphics test
    updated stage_2 heater example with control1v1 pinout,
    put DueWithThreeSSRs in folder so arduino IDE won't complian
    [DueWithThreeSSRs.ino, GraphicsTest.ino, stage_2_heater.ino.ino]
2023-12-05 Update to test Mini-12864 Display. Tests encoder and buzzer. Remove dead code. RepRap button resets position. Encoder position only decrements sort of.
    [DueWithThreeSSRs.ino]
2023-12-05 Add blower enable and fan PWM control with PWM fixed.
    [DueWithThreeSSRs.ino]
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2023-12-06 Update schematic to reflect some reworks to V1.1 assemblies. 5V to Display. Display signal names. J35 pin8 to 10 short.
    [Adafruit-MAX31850-thermocouple-breakout-board.kicad_sch, Adafruit-MAX31855-breakout-board.kicad_sch, Adafruit-MAX31856-PCB-master.kicad_sch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]
2023-12-09 Add dimensions to PCB drawing. Modify MountMini12864 for holding PCB on desk.
    [MountMini12864.FCStd]
2023-12-10 Add R1 and R2 arguments to ADC Class. Show Rework for SENSE_AUX2 on schematic.
    [Control_1v1.kicad_sch]
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2023-12-11 fixing some bugs; fan control may be working now
    [main.cpp]
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2023-12-11 Remove dead code. Change program name reported on serial port. Fix magic numbers.
    [DueWithThreeSSRs.ino]
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2023-12-18 error with MachineConfig, probably not abstracted correctly
    [main.cpp]
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2023-12-19 issue with trying to abstract the fan class, there are several implementations of the fan and it needs refactoring
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2023-12-21 Update schematic with Mini pin information. Experiment with other constructors on the Ethernet sketch.
    [display_interface.kicad_sch]
2023-12-21 Set up for display working and add notes to the constructors which did and did not work display or LAN.
    [Ethernet_BigTreeTechMini12864.ino]
2023-12-22 fixing the 4x rpm issue, and minor changes to the heater out of bounds, which is still not working
2023-12-22 Stand alone DueTach trying to troubleshoot oscillating tac readings.
    [DueTach.ino]
2023-12-22 DueTach which shows oscillation of RPM when the main loop had delay.
    [DueTach.ino]
2023-12-22 Disable interupts when reading the tach_data_cnt but problem remains. Bumpted to Rev 0.3
    [DueTach.ino]
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2023-12-27 eliminate redundant and wrong print statement., Change to divid ratio for +24V and +12V for R1=40K
    [DueTach.ino]
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2023-12-28 added power supply, compiles but doesn't completely work
    [DueWithThreeSSRs.ino]
2023-12-28 fixed display and link status
    [DueWithThreeSSRs.ino]
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2023-12-29 fixed comms on HDS800
    [DueWithThreeSSRs.ino]
2023-12-29 fixed ethenet such that it turns on,also decreased fan speed to whisper quiet, added back in ssr testing
    [DueWithThreeSSRs.ino]
2023-12-30 updated Display ethernet logging, fixed PSU now correctly works with all psu's, updated resistor mod for the 24v psu detection,
    warning, debug code enabled to investigate why SW watchdog trips at 25 second mark
    [DueWithThreeSSRs.ino, main.cpp]
2024-01-03 reverted watchdog timer test code, fixed scheduler typedef of TimeMs as it uses negative integers in the scheduler attempted to speed up power supply serial fixed threshold issue wih detecting 24v as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
    [main.cpp]
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2024-01-04 removed error define flags and fixed fan fault stuck on
    [main.cpp, test_heater_ramp.cpp]
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2024-01-05 correctly detects properly configured and running psu, doesn't recover from power outages yet.
    [main.cpp]
2024-01-06 #171 fixed, as well as many more
    [main.cpp]
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2024-01-07 Added better debugging messaged for PSU error, removed error out on Latched PSU
    Added 12v power bad detection to cog_task, duplicate of 24v power bad detection
2024-01-08 missing 12v functions, previous commit
2024-01-08 added better fan error checking disable in PIO and added missing fault clear statement on restored power for 12v and 24v
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2024-01-08 Make the LAN status non blocking. The SSRS are now toggeling and the buzzer works. Bump to version 7. Rename to old name.
    [DueWithThreeSSRs.ino]
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2024-01-09 added lower temperature threshold, tested on my machine by waiting to reach temp and then cutting power to heater
    got "lost control of heater" error
    flags set for MOOK and MOM
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2024-01-15 not working yet, added code to enable and disable display and ethernet in tasks
    [RS232-powersupply.ino]
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2024-01-16 added missing stack_watts
    cleaned up stack over wattage code
    hooked up STACK_LOSS_PWR, renamed STACK_LOSS_CTL
    bumped revision to 0.3.16
    [main.cpp]
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2024-01-17 spelling fix and others
    [main.cpp]
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2024-01-18 reverted changes to DueWithThreeSSR's added display compile time commands to current targets
    [DueWithThreeSSRs.ino]
2024-01-18 bumpped revision 0.3.19 //fixed issue with 5 second log reports
    [main.cpp]
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2024-01-23 adding debug code to tryp to trap error
    [main.cpp]
2024-01-24 Add notes about reworkd to R106 and R108.
    [Control_1v1.kicad_sch]
2024-01-24 Add notes to schematic about level shifting 5V to 3.3V on Stack Power Supply. More annotation of many schematic blocks.
    [Adafruit-MAX31850-thermocouple-breakout-board.kicad_sch, Adafruit-MAX31855-breakout-board.kicad_sch, Adafruit-MAX31856-PCB-master.kicad_sch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]
2024-01-24 resolved issues with refactoring
    [main.cpp]
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2024-01-30 misapplied FAN_LOSS_PWR_FAULT_TOLERATION_TIME_MS, corrected it
    [main.cpp]
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2024-03-02 solved issued #219, I hope
    [main.cpp]
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2024-04-05 Add a rough up of a 3U and 18x15 inch enclosure chassis.
    [ThreeU_Chassis.FCStd]
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2024-06-11 Update RS232-powersupply.ino
    //testing brownout status bit after status0 update
    [RS232-powersupply.ino]
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2024-06-12 Update the RS2332-powersupply. Recover from brown out. Bump version to 0.7.
    [RS232-powersupply.ino]
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2024-06-21 Reduce chassi from 18" to 17" for clearance in rack.
    [ThreeU_Chassis.FCStd]
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2024-06-26 Add holes to chassis for front panel and rear panel and eventual top.
    [ThreeU_Assembly_SinglePower.FCStd, ThreeU_Chassis.FCStd]
2024-06-26 Fix 3UAssembly after adding holes broke constraints.
    [ThreeU_Assembly_SinglePower.FCStd]
2024-06-26 Fix rubber feet centering. Make unfolded drawing practice.
    [ThreeU_Chassis.FCStd]
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2024-06-28 On 3U chassis increase bend radius to material thickness. SendCutSend order form showed an error.
    [ThreeU_Chassis.FCStd]
2024-06-28 On 3U chassis set bend radius to 0.035 per vendor instruction. Place Controler V1.1 Mounting holes.
    [ThreeU_Chassis.FCStd]
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2024-06-30 Changed order of fold on chassis. This reports a DAG problem.
    [ThreeU_Chassis.FCStd]
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2024-07-01 Clone the front panel and add power siwtch, O2 on switch, O2 LED, 4 K thermocouple jacks, and Fan connector.
    [ThreeU_Chassis.FCStd]
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2024-07-01 Fix fold base objects per advise from Frothman.
    [ThreeU_Chassis.FCStd]
2024-07-01 Tweeks to chassi holes for DIN rail mounts. Tweek to power supply placement.
    [ThreeU_Chassis.FCStd]
2024-07-01 Commit before fixing Control board orentation.
    [ThreeU_Chassis.FCStd]
2024-07-01 Fixing Control board orentation.
    [ThreeU_Chassis.FCStd]
2024-07-01 Tweeking to chassis, reduce the slot count. Make flat power supply mounts slots.
    [ThreeU_Chassis.FCStd]
2024-07-01 Before trying to clear front panel hole errors when rack mount holes added.
    [ThreeU_Chassis.FCStd]
2024-07-01 Trying and failing to clear front panel hole errors when rack mount holes added.
    [ThreeU_Chassis.FCStd]
2024-07-02 Still trying and failing to clear front panel hole errors when rack mount holes added.
    [ThreeU_Chassis.FCStd]
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2024-07-04 Add a grounding hole to the rear panel. Try to add grouding hole to chassis. Update notes on Fand 3D model.
    [ThreeU_Chassis.FCStd]
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2024-07-08 Add a hole to front panel for C20 receptical. Delete old step file and add new one.
    [ThreeU_Chassis-BodyFrontPanelWithHoles20240703_1650.step, ThreeU_Chassis-BodyFrontPanelWithHoles20240708_1444.step, ThreeU_Chassis.FCStd]
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2024-07-11 Correct numberOfDevices in the legend of plot.
    [MAX31850_Tester.ino]
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2024-07-14 updated BOM and P&ID, need to review and update P&ID with part reference
    [Task 6 P and ID BOM.ods]
2024-07-14 updated with references, working on making sure all interconnects nessisary are accounted for
    [Task 6 P and ID BOM.ods]
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2024-07-16 Add drawings for 20" and 30" angle iron and a plant cage.
    [AngleIron20inch.FCStd, AngleIron30inch.FCStd, PlantCage.FCStd]
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2024-07-16 Change size on O2 hole in Plant Panel. Add plant panel to plant assembly.
    [PlantCage.FCStd, ThreeU_Chassis.FCStd]
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2024-07-16 Add back in the holes for I2C connector and Fan. Make a STEP file for Plant panel.
    [AssyPlantCage.FCStd, ThreeU_Chassis-BodyPlantPanelWithHoles20240716_1703.step, ThreeU_Chassis.FCStd]
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2024-08-09 Delete mech/enclosure/signal-desktop-keyring.gpg
    @LokiMetaSmith added this by mistake. this shouldn't have ever been in a git repo. not sure how it got in there.
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2024-09-03 updated task 6 BOM and p&id diagrams, should be complete for oxygen handling and measuring
    [Task 6 P and ID BOM.ods]
2024-09-09 Fix errors on Powerwerx PanelPlateSB1
    [ThreeU_Chassis.FCStd]
2024-09-09 Fix errors on Thermocouple panel mounts.
    [ThreeU_Chassis.FCStd]
2024-09-09 Fix missing horizontal contraint on C20 holes.
    [ThreeU_Chassis.FCStd]
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2024-09-17 updated bom, minor p&id updates, added models and notes on the models in the part model directory
    [5272K191_Yor-Lok Fitting for Copper Tubing.STEP, 5305K401_Yor-Lok Fitting for Stainless Steel Tubing.STEP, 7919A51_Hose Fitting for Compressed Gas.STEP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]
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2024-09-24 Make new Plane Panel by cloning updated Front panel. Update assembly drawing with plant panel.
    [AssyPlantCage.FCStd, ThreeU_Chassis.FCStd]
2024-09-25 Update AssyPlant with plant panel of 20240924. Add STEP models for Anderson, C20, Thermocouple, GX12, GX16, and bannana.
    [AssyPlantCage.FCStd]
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2024-09-25 added missing quick disconnect step file
    added updated notes and consideration for a different washer now we have a known plant panel thickness
    [7934A6_Quick-Disconnect Hose Coupling Set for Compre.STEP]
2024-09-25 Update AssyPlant to move Plant Panel to top. Update chassis for larger hole for O2 pipe.
    [AssyPlantCage.FCStd, ThreeU_Chassis.FCStd]
2024-09-25 Fix Panel Mount for SB50 width and height.
    [ThreeU_Chassis.FCStd]
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2024-09-26 Fix front panel anderson flang, fix plane panel anderson flang, fix O2 hole on plane panel.
    [ThreeU_Chassis.FCStd]
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2024-10-02 New STEP files for Front Panel and Plant Panel after fixing Issue 319.
    [ThreeU_Chassis-BodyFrontPanelWithHoles20241002.step, ThreeU_Chassis-BodyPlantPanelWithHoles20241002.step]
2024-10-04 Fix #323, math of logging records
    [main.cpp]
2024-10-07 adding keep alive and error detection LED handling
2024-10-12 minor updates, added missing model
    [4936K768_Compact Extreme-Pressure Steel Pipe Fitting.STEP, Task 6 P and ID BOM.ods]
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2024-10-14 The cable is a 1-to-1 pin connection, initial version had it inverted.
    Corrected and added a mirrored back view for easier assembly
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2024-10-22 ThreeU_Chassis.FCStd Front panel to REv 3. Modified to move top LED away from chassi top inteference by 0.25inches.
    [ThreeU_Chassis.FCStd]
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2024-12-02 Contrl 1.2 schematic Issue Mini-12864-Panel 3.3v on display 2.4ish volts #110
    [display_interface.kicad_sch]
2024-12-02 Contrl 1.2 schematic, fix for Issue control board V1 kills ethernet boards #66
    [Adafruit-MAX31850-thermocouple-breakout-board.kicad_sch, Control_1v2.kicad_sch, display_interface.kicad_sch]
2024-12-02 Contrl 1.2 schematic, fix for Issue Controller v1, COPI improperly attached to DO #54
    [Adafruit-MAX31850-thermocouple-breakout-board.kicad_sch]
2024-12-02 Contrl 1.2 schematic, fix for Issue Control V1.1, A4 SENSE_AUX2 Conflicts With LAN Card SDA ( So does A5) #116
    [Control_1v2.kicad_sch]
2024-12-02 Contrl 1.2 schematic, fix for Issue: Mini-12864-Panel STOP/KILL NP on R7, SHUTDOWN button Inoperative #109
    [display_interface.kicad_sch]
2024-12-02 Contrl 1.2 schematic, fix for Issue: [200~Add TP to 5VHead, 5V, Change TP Values for SilkScreen
    [Control_1v2.kicad_sch]
2024-12-02 Contrl 1.2 PCB, fix for Issue: silk screen on control 1v1 on J16 should be on J20 #142
    [Control_1v2.kicad_pcb]
2024-12-02 Contrl 1.2 schematic, fix for Issue: hds800ps12 and TF800A12K appear to be 5v TTL logic, and not 3.3v #144
    [Control_1v2.kicad_sch]
2024-12-02 Contrl 1.2 schematic, fix for Issue: not enough overhead on the 12v and 24v sense lines #145
    [Control_1v2.kicad_sch]
2024-12-02 Contrl 1.2 PCB, fix for Issue: Turn on silk screen Value for TP2 and TP20.
    [Control_1v2.kicad_pcb]
2024-12-02 Contrl 1.2 schematic, fix for Issue: Tach Failure, Missplugged at J20, Update J20 with Key #166
    [Fan controller.kicad_sch]
2024-12-02 Contrl 1.2 schematic, fix for Issue: Connect J3 pin 8 to the Due, Footrpint Arduino_Due_Shield_Annotated Missing Pin Number on ND on Schematic symbol and footprint. #348
    [Control_1v2.kicad_pcb, Control_1v2.kicad_sch]
2024-12-02 Contrl 1.2 PCB, fix for Issue: Fan connector routing.
    [Control_1v2.kicad_pcb, Control_1v2.kicad_sch, Fan controller.kicad_sch]
2024-12-02 Contrl 1.2 schematic, fix incorrect signal nameing on J20.
    [Fan controller.kicad_sch]
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2024-12-02 Contrl 1.2 schematic, adding relay for the battery. Adding connector for Status and Fault front panel LEDs.
    [display_interface.kicad_sch]
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2024-12-04 Fix #346, improving the fan issue
    [main.cpp]
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2024-12-11 Update Control_1v2.kicad_sch for correct JLCPCB part number on JST 2 pin XH Connector. Wire up J30 as connector for OEDCS Fan.
    [Adafruit-MAX31850-thermocouple-breakout-board.kicad_sch, Control_1v2.kicad_sch, SSR Interface.kicad_sch]
2024-12-12 Update thermocouple page for power to new amplifier. Update Battery to screw terminal, Update O2 front panel switch and LED connections to JST XH connectors.
    [Adafruit-MAX31850-thermocouple-breakout-board.kicad_sch, display_interface.kicad_sch]
2024-12-12 Update Control_1v2.kicad_sch for Power OK from power supply into Due for possible interupt service of power supply NOT OK.
    [Control_1v2.kicad_sch]
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2024-12-17 Add mechanical files for ThreeU enclousre invoice and FreeCAD for 02 plumbing parts.
    [O2Quick.FCStd]
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2024-12-18 Revert "Origin/esp32 compilation"
2024-12-18 Clearing more ERC schematic errors. Off grid. Remove some redundant Net names.
    [Adafruit-MAX31850-thermocouple-breakout-board.kicad_sch, Control_1v2.kicad_sch, display_interface.kicad_sch]
2024-12-18 Clearing more ERC schematic errors. Only errors related to libraries and ground symbol modified remain.
    [Adafruit-MAX31850-thermocouple-breakout-board.kicad_sch, Control_1v2.kicad_sch]
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2024-12-18 PCB V1.2. Clear PCB errors. Plenty of warnings still.
    [Control_1v2.kicad_pcb]
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2024-12-18 PCB V1.2. Set to ignore many silk screen errors. Only three errors left.
    [Control_1v2.kicad_pcb]
2024-12-19 PCB V1.2. Routing with out errors.
    [Control_1v2.kicad_pcb, Control_1v2.kicad_sch, SSR Interface.kicad_sch]
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2024-12-20 PCB V1.2. Add 3d model for power supply footprint. Set many headers connectors for DNI on schematic and PCB.
    [Adafruit-MAX31855-breakout-board.kicad_sch, Adafruit-MAX31856-PCB-master.kicad_sch, B24B-PHDSS-B-LF--SN---3DModel-STEP-56544.STEP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]
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2024-12-20 Add a connector next to the SHUTDOWN switch. Add 3D file for relay.
    [Control_1v2.kicad_pcb, Control_1v2.kicad_sch, SRD-05VDC-SL-C.STEP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]
2024-12-20 PCB V1.2. Fixes to parts for BOM and PL.
    [Control_1v2.kicad_pcb, Control_1v2.kicad_sch, I2C_Level_Shifter.kicad_sch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]
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2024-12-31 PL and POS file fixing truncated POS fields.
    [PL_Control_1v2_20241231_0705.xls]
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2025-01-02 Fix error with J805. Simplify by deleting some tabs.
    [PL_Control_1v2_20241231_0705.xls]
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2025-01-17 ThreeU_Chassis.FCStd add Kfactor and bend radius to spread sheet and rear fold.
    [ThreeU_Chassis.FCStd]
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2025-01-21 ThreeU_Chassis.FCStd Redraw the fold sketches of chassis. Fixes the eges of folds.
    [ThreeU_Chassis.FCStd]
2025-01-21 ThreeU_Chassis.FCStd Set K factor to 0.42 and bend radius to 0.889 mm.
    [ThreeU_Chassis.FCStd]
2025-01-22 Control_1v2.kicad_pcb and schematic, Change J804 to JILN JL500-50802G01 screw terminal. Fix Incompatible part called out for J804, C5142622. #374
    [Control_1v2.kicad_pcb, display_interface.kicad_sch]
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2025-02-11 fixes #388 and supporting two thermocouples
    [main.cpp]
2025-02-12 Correct notes to schematic identifying subaddress on MAX31850.
    [Adafruit-MAX31850-thermocouple-breakout-board.kicad_sch]
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2025-02-22 Add a sketch to toggle the MOSI pin to the LAN card. Used to troubleshoot short circuit.
    [Toggle_MOSI.ino]
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2025-03-13 moving constants and adjusting LOWER Battery limit, fixes #402
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2025-04-08 updated SBC docs and changed arduino.h to Arduino.h in panel.h, fixed issues 409 and 410
2025-04-13 final bug before trip to Blue Origin
    [main.cpp]
2025-04-16 potential fix to #411
    [main.cpp]
2025-06-02 Integrate MQTT for reporting, replacing UDP.
    This change introduces MQTT for sending JSON reports, replacing the previous
    UDP-based mechanism.
    Key features and changes:
    - Added PubSubClient library for MQTT communication.
    - Created `NetworkMQTT` class to encapsulate MQTT logic:
    - Connection to MQTT broker (with optional username/password).
    - Publishing messages.
    - Last Will and Testament (LWT) for online/offline status (`devices/<MAC>/status`).
    - Non-blocking reconnection logic with timed retries.
    - Updated `OEDCSNetworkTask` to utilize `NetworkMQTT` for its operations.
    - Removed the old `NetworkUDP` class and refactored the `NetworkTask` base class to be generic.
    - Introduc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
2025-06-02 Framework for Secure MQTT with WebSockets, TLS, and Client Certs
    This commit establishes the foundational framework for enhancing MQTT communication with security features including WebSockets, TLS, and client certificate authentication. It replaces PubSubClient with the more capable `arduino-mqtt` library.
    Key Changes:
    1. **Library Migration:**
    * Integrated `256dpi/MQTT` (`arduino-mqtt`) library, replacing `PubSubClient`.
    * Updated `platformio.ini` dependencies.
    2. **Certificate Management:**
    * Created `firmware/include/certificates.h` with PROGMEM placeholders for CA certificate, client certificate, and client private key. This defines the strategy for on-device cert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
    [mqtt_config.h]
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

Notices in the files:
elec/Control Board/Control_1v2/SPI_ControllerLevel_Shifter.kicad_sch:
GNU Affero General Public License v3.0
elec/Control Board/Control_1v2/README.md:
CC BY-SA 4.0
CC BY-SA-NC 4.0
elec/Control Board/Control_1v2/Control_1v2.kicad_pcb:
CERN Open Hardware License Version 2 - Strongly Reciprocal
